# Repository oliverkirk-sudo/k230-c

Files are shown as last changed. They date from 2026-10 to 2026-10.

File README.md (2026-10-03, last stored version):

# k230-c

## 当前检查点：已恢复 v12 + R2.1 源工程

本仓库保存 CM-K230 核心板的可编辑源工程和验证证据。v12 基线与 R2.1 累积增量均已恢复并核验。**这是原理图/候选封装恢复检查点，不是生产版本。当前候选仍没有完整核心板 PCB。**

当前入口：`project/cad/recovery-physical-candidate/CMK230_Core_REVIEW.kicad_pro`（原理图同名 `.kicad_sch`）。保持 `project/` 内相对目录结构即可解析已恢复的 10 个封装库。

## 本次重新验证（2026-10-03，KiCad 9.0.2）

- v12 ZIP：888 个成员 CRC 通过，886 个原始保留文件哈希匹配；SHA-256 `63dab93b8433b3a367571ec64b11568b9c81dc466e8d562ce2108b647d341e58`
- R2.1 ZIP：332 个成员 CRC 通过，325 个增量文件哈希匹配；SHA-256 `4e23cf611b37900dab169f0b44da5974ae70c65bbcf7624c97ccb16688eb3b5b`
- 增量在独立 v12 工作副本上通过防覆盖校验后应用，全部 325 个增量文件保持一致
- 新导出网表：254 个元件、1,509 个引脚绑定，与 R2.1 归档的元件、属性、网络、引脚功能和类型一致
- 恢复后新 ERC：0 个错误、0 个警告；10 个封装库均能解析
- R528 保持默认 DNP，存储默认禁止；149 个元件有封装字段，105 个仍未分配。R574 封装尚未完成验证

新结果在 `validation/2026-10-03-restored/`。`validation/2026-10-03-delta-only/` 保存基线尚未到达时的历史检查（0 错误、150 个缺库警告）；这些缺库警告已由完整恢复后的新结果取代。`project/` 中其他报告保留历史阶段含义，不能视为本次全部重新执行。

## 尚未完成的工程资格验证

- 当前 `recovery-physical-candidate` 没有完整核心板 PCB；历史 PCB、8 层试验和封装/负控夹具仍保留用于追溯，不是当前 6 层成品
- 38 × 38 mm 外形、140 个触点、1 mm 间距、恰好 6 个铜层及仅顶面贴装是设计要求，并非已达成的制造验收
- 尚需完成封装缺口、整板布局布线、DDR/时序、高温/上电、DFM 和工厂工艺确认
- TI 候选阻焊桥名义 80 µm；NXP 示例名义 55 µm。KiCad 全局最小阻焊桥设为 75 µm 时可能合并开窗。必须核对实际 CAM 与铜/蚀刻/阻焊/钢网/贴装能力

## 发布内容、来源与完整性

`project/` 保留源 CAD、库、脚本、数据、网表、工程审查和来源 URL/哈希，以及必要的 `LICENSE-01studio.txt` 上游 MIT 版权许可声明。未将该许可扩展为对其他第三方材料的新授权。

本公开源文件检查点经过筛选，未包含厂商 PDF/扫描页面、图像、运行时缓存、会话设置、日志、备份 ZIP 及部分大型历史 DDR 搜索生成结果。它不是两个原始 ZIP 的逐字节镜像。历史报告和冻结清单可能引用这些省略文件；需要相关生成结果的旧测试须先重新生成。完整排除项/原始哈希/两处非技术署名编辑见 `PUBLICATION_PROVENANCE.json`；当前发布文件完整性以根目录 `SHA256SUMS` 为准。

## English summary

The verified v12 baseline plus R2.1 delta has been restored. The active editable schematic resolves all 10 footprint libraries. Fresh KiCad 9.0.2 ERC has zero errors and zero warnings; the exported 254-component / 1,509-binding graph matches R2.1. There are 149 assigned and 105 unassigned component footprints. This is a source-recovery checkpoint, not a production release: no complete active six-layer board has been recovered or routed. Historical trials and tests retain their original limited scope.

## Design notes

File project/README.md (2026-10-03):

# CM-K230 核心板重设计：v12 评审工程

最新说明：[V12_CORE_REVIEW.md](V12_CORE_REVIEW.md)

保留 38×38mm、140 针、1mm 间距、顶面器件、1GB LPDDR4、16GB eMMC，以及断电切换外部 TF。R528 默认 DNP，存储禁止；整板尚未完成布局布线、启动或高温资格验证。

## 打开哪些文件

- cad/high-temp-candidate/CMK230_Core_REVIEW.kicad_pro：当前条件式高温原理图，18 页、ERC0；同名 PCB 只是150个封装的部分导入，内部元件未放置
- cad/bga-engineering-candidates/bh153-sparse-trial/BH153_SPARSE_LOCAL_TRIAL.kicad_pcb：独立原生 eMMC 逃线试验，保留17个未连通项和32个悬空警告
- cad/conditional-process-check/：保留v11的38封装独立条件工艺规则试验，不是生产规则释放
- cad/edge-bound-seed/：140针逐一接入实际网络的边缘种子，尚无内部器件
- cad/castellation-proposal/：冻结的半孔和八层叠层机械提案，尚待工厂/装配联合接受
- cad/integrated/：保留 Samsung 参考分支及其原有温度限制

既有 GUI 截图按其实际版本保留；本轮 CLI、原生解析、故障对照和各阶段的限制见最新报告。几何局部通过、原理图 ERC0、整板可制造和硬件通过是不同结论。

历史说明保留在 V9_CORE_REVIEW.md、V10_CORE_REVIEW.md、V11_CORE_REVIEW.md 及 docs/。旧 v4 的 eMMC 电源映射错误已修复，禁止使用 v4 制板。

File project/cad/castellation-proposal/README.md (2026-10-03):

# New castellation proposal, not fabrication release

Open `CMK230_Castellation_NOMINAL_PROPOSAL.kicad_pcb` to review the editable 38 × 38 mm edge geometry. The library contains 140 plated, all-layer castellated pads at 1 mm pitch, Ø0.50 mm requested nominal finished opening, and 0.80 × 1.80 mm oval copper. Both mask layers have 0.05 mm expansion; there are no paste apertures. The board has eight copper layers and a proposed 1.2 mm nominal thickness. No dielectric stack or impedance width is invented in this CAD file.

This is a new module fabrication proposal. The original carrier's 1.6 × 0.56 mm oval lands at normal coordinates ±18.746 mm are a different geometry. The proposed module drill rows lie at ±19 mm. The inner drawing rectangle is a conditional 1.30 mm component reservation, not a fabrication keepout rule accepted by a factory.

Read the [source-backed review](../../engineering/mechanical/castellation-stackup-proposal-review.md), [dimensional proof](../../engineering/mechanical/castellation-proposal-dimensional-proof.json), [source comparison](../../engineering/mechanical/castellation-fab-source-review.json) and [stackup proposal](../../engineering/mechanical/core-stackup-process-proposal.json). The main CAD and committed area-screen baseline are unchanged.

Do not use this footprint as the carrier mating footprint, order fabrication from it, or infer factory acceptance from a clean KiCad DRC. Run `engineering/mechanical/build_castellation_proposal.py` with the system Python/KiCad environment to reproduce the proposal. Generated native UUIDs may change while geometry remains identical.

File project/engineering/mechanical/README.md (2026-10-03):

# Mechanical and footprint audit

Date: 2026-09-30. Scope: selected TI footprints and BGA package coordinates for the 38 x 38 mm top-component CM-K230 review. No master CAD edited. No module castellation geometry inferred from the existing carrier mating footprint.

## Outcomes

- Four editable TI footprints in `../../cad/verified-footprints/CMK230_Verified.pretty`
- 42 numbered copper pads; 42 explicit mask openings; 42 paste apertures
- 568 independent numeric checks through KiCad's parser, including pin positions, sizes, corners, layer membership, mask/paste and courtyard enclosure
- Native KiCad DRC on the isolated footprint QA board: 0 violations, 0 unconnected items. Its 0.075 mm local clearance rule is a geometry-test setting, not evidence a PCB vendor can manufacture the module
- Native Gerber verification: all 42 flashes on each of F.Cu/F.Mask/F.Paste match independently transcribed positions, dimensions, shapes and corner radii
- Independent manufacturer-source extraction corroborates 200 RAM, 153 eMMC and 390 K230 physical-ball centers with no occupancy mismatches

## TI drawing results

| Package | Body nominal / maximum, mm | Drawing-verified exposed pattern | Chosen copper / mask details | Courtyard, mm |
|---|---|---|---|---|
| RSV0016A | 1.80 x 2.60 / 1.85 x 2.65 | 0.4 pitch; 15 lands 0.6 x 0.2; pin1 0.7 x 0.2 | NSMD; copper = exposed land; explicit 0.05 expansion; constant-offset corners | 2.80 x 3.60 |
| DBV0005A | 1.60 x 2.90 / 1.75 x 3.05 | 1.1 x 0.6 lands; x=+/-1.3; y=0,+/-0.95 | NSMD; chosen 0.05 expansion within TI 0.07 max | 4.30 x 4.10 |
| DMQ0006A | 1.50 square / 1.55 square | left 0.6 x 0.25 at x=-0.65; right 1.0 x 0.2 at x=+0.45; y=0,+/-0.5 | TI-preferred SMD; chosen minimum 0.05 copper overlap each side; copper 0.70 x 0.35 / 1.10 x 0.30; exposed R0.05 | 2.50 x 2.10 |
| YCG0015 | 1.05 x 1.78 / 1.07 x 1.80 | 3 columns x 5 rows at 0.35 pitch; 0.200 circular exposed opening | TI-preferred SMD; chosen minimum 0.0325 overlap; copper diameter 0.265; aperture diameter 0.200 | 1.60 x 2.30 |

Courtyards are project-selected: at least 0.25 mm beyond maximum body/copper/mask envelope, rounded outward to 0.05 mm. DBV additionally accounts for the drawing's possible 0.25 mm body flash per side. Courtyards are not vendor package dimensions or an approved module placement density rule.

RSV pin1 center is (-0.75,-0.60), while the other left-side centers are x=-0.80. Its longer land shares the same outer edge as the other left lands. The RSV top-view functional pinout differs from the TSSOP package. DMQ's data-sheet function diagram is a bottom view; the footprint is transformed to the component-side pattern with pin1 upper-left. YCG A1 is (-0.35,-0.70), A3 (+0.35,-0.70), E1 (-0.35,+0.70).

The YCG stencil aperture is a 0.21 mm rounded square with R0.05 corners, not a 0.21 mm circular aperture. Its TI example stencil is 0.075 mm thick. RSV/DBV/DMQ examples are 0.125 mm. Those are assembly examples rather than automatically compatible selections for one board; obtain a reviewed common or stepped stencil.

Selected drawn minimum copper / mask gaps: RSV 0.200 / 0.100 mm; DBV 0.350 / 0.250 mm; DMQ 0.150 / 0.250 mm; YCG 0.085 / 0.150 mm. These are nominal geometric gaps, not guaranteed post-fabrication tolerances. SMD overlaps at the minimum must still be qualified for registration and etch tolerances.

## Existing KiCad library comparison

The installed libraries were read and preserved unchanged. Their common package names are not exact replacements for these TI examples:

- `SOT-23-5`: IPC-generated pads at x=+/-1.1375, size 1.325 x 0.6, rather than the TI example x=+/-1.3, size 1.1 x 0.6
- `UQFN-16_1.8x2.6mm_P0.4mm`: different IPC land lengths/centers (pin1 0.9 x 0.2 at -0.8,-0.6; others 0.8 long), rather than the exact RSV board example
- `WSON-6_1.5x1.5mm_P0.5mm`: TLV702-derived generic geometry; cannot substitute for DMQ's asymmetric short/long contacts
- A same-body QFN with a center exposed pad is not valid for RSV. No such pad was added

The installed-library JSON records actual parsed dimensions and rotations. Different IPC land dimensions are not themselves proof an installed footprint is unsafe; they simply do not reproduce the selected official TI land examples.

## Evidence and reproduction

- `small-parts-footprint-spec.json`: package dimensions, exact sources, process choices and build data
- `small-parts-pad-coordinate-audit.csv`: electrical pad positions and functions
- `small-parts-verification.json`: native-parser checks and footprint hashes
- `native-gerber-verification.json`: independently checked KiCad-exported aperture geometry
- `footprint-geometry-qa-drc.json`: native DRC result
- `TI-footprint-layer-gallery.png`: copper/mask/paste layers rendered from actual loaded footprint objects
- `native-svg/`, `native-render/`: KiCad's own footprint exports, visually reviewed
- Official PDF page/image evidence is retained outside this distributable tree in the reference workspace; source manifest records URLs and hashes
- `ti-source-manifest.json`: official URLs, local reviewed source hashes and pages
- `installed-kicad-library-comparison.json`: installed package comparisons
- `bga-mechanical-audit.md` and `bga-*-physical-centers.csv`: independent BGA findings, sources, centered coordinates and release boundaries

Run `python3 build_verified_footprints.py`, then `/usr/bin/python3 validate_verified_footprints.py`. Export the isolated QA board F.Cu/F.Mask/F.Paste through `kicad-cli pcb export gerbers`, then run `python3 check_native_gerbers.py`. The validator deliberately does not import the generator's spec; the Gerber validator uses a separate transcription. Native KiCad Python is available in `/usr/bin/python3`.

If regenerating exports, point XDG_CONFIG_HOME, XDG_CACHE_HOME and XDG_DATA_HOME to writable temporary locations. The footprint library uses explicit local mask/paste settings; keep the unnumbered mask/paste primitives when integrating.

Original manufacturer PDFs and source-image copies are research evidence, not new licensed package deliverables; preserve their attribution/usage terms and use source links in any externally distributed package. This audit does not expand source redistribution rights.

## Remaining release boundaries

The three large BGA sources establish occupancy, ball-center pitch, body envelope and orientation, not a complete PCB copper/mask/stencil design. Never use the published ball diameter as an automatic PCB pad diameter. K230's 0.270 mm mask statement is package-context evidence; it does not alone establish a board land pattern. Module castellations, drill/plating/edge offsets and the manufacturing edge definition remain unverified separately from the original carrier land pattern.

## Placement-only continuation

`../../cad/verified-footprints/placement-only/` contains an isolated 38 x 38 mm editable KiCad canvas with the 3 BGA mechanical placeholders and the actual 10 small-IC instances of the four verified TI footprint types. All are top-side. `placement-only-canvas.png` is the annotated preview. The 13 chosen assembly envelopes fit without overlaps (minimum pair gap 0.85 mm; outline gap 2.45 mm). There are no BGA copper/mask/paste pads, routes, vias, drills, zones or edge contacts. See the canvas README for the explicit omissions: this is body-fit evidence only, not proof of escape, passive fit, thermal/PDN performance or manufacturing feasibility.

## Compact-package alternatives, 2026-09-30 continuation

The expanded BOM makes the original 13-IC body canvas insufficient as a full-fit result. `compact-package-audit.md` reviews pin-equivalent DRL/DCK choices for SN74AUP1G06/07/08/17 and the exact TPS3808 DBV-to-DRV remap, with three new editable candidate footprints in `../../cad/verified-footprints/compact-options/`. Five AUP DRL instances plus two TPS3808 DRV instances recover 30.04 mm² against seven rough 11.52 mm² DBV reservations. The compact candidate coupon passes 226 native numeric checks and independent copper/mask/paste Gerber checks; no master integration was done.

`compact-inductor-mechanical-review.md` records the official DFE201610E-R47M drawing and 6.67 mm² body/land or 7.20 mm² hypothetical mask-sensitive reservations, pending electrical/thermal selection. `compact-area-scenarios.json` freezes the old area-screen hash and keeps the proposed savings separate from a latest full-BOM estimate. A limited U96-only update leaves essentially no arithmetic margin even before complete routing and support-part changes. These remain area-screen candidates, not proof of manufacturable single-sided fit.

Latest correction: U92/U94 use the six-pad SN74AUP1G97 DRL Schmitt-AND footprint; U96 and its capacitor are removed by the design lead. The older five-AUP area scenarios are historical, as is the optional eight-rail monitor assumption. See the first section of `compact-package-audit.md` and `compact-AUP1G97-status.json`. The expanded compact library now passes 302 numeric checks and 23/23/24 copper/mask/paste Gerber checks.

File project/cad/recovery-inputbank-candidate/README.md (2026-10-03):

# RCV-INBANK-R12 conditional sibling

Open CMK230_Core_REVIEW.kicad_sch to inspect the alternative eight-part22µF input-bank circuit. The preferred comparison baseline remains ../recovery-physical-candidate; every existing R11 project file is unchanged.

Exactly eight input values/footprints change and four named input capacitors are removed. All six100nF bypasses remain. No other values, pin/net/function/type bindings or population states change. The candidate is250 components/1501 bindings, with238 footprint identities and12 gaps. Fresh ERC and generator/graph checks pass within that scope.

See ../../recovery/r12-input-bank-candidate/README.md for exact references, current source evidence, Ceff assumptions,120→176µF nominal input increase, inrush/VIN-fall gates and34–36mm² matched-area cost. No full PCB, physical fit, operating qualification or production release follows from this candidate. R528 remains DNP and storage qualification remains inhibited.

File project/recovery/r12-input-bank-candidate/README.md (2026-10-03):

# R12: separate 22 µF input-bank candidate

This is a coherent alternative circuit, not the preferred or production-qualified core. The baseline at cad/recovery-physical-candidate is preserved byte-for-byte from published R11. Open cad/recovery-inputbank-candidate/CMK230_Core_REVIEW.kicad_sch to inspect this alternative. No full PCB or manufacturing output is produced.

## Exact revision

Eight existing positions become22µF CL31B226KPHNNNE input candidates: C203,C210,C211,C216,C217,C220,C225,C230. Only C204,C221,C226,C231 are removed. U22/U23 retain two local bulk capacitors each; U21/U24/U25/U26 have one each. C205,C209,C215,C222,C227,C232 retain their100nF bypass duties and values. All other nominal values, component population/BOM flags and numbered pin/function/type/net identities remain unchanged.

The candidate contains250 components and1501 bindings across457 nets. It has238 assigned footprints and12 gaps. The physical baseline remains254/1509 with230 assigned and24 gaps. JP1,R45,R47 and R528 remain DNP. Default storage qualification is still inhibited.

## Evidence and cost

Fresh manufacturer curves, not the archived result alone, support a conditional screen of6.925µF per selected part at5.5V. The pairs screen at13.849µF against the adopted8µF TPS628640B input criterion; the singles screen at6.925µF against the3µF TPS6282xA criterion. Initial tolerance, normalized typical AC response, temperature, aging and model reserve are individually identified in source-review. Separate typical curves and illustrative reserves do not establish a guaranteed combined minimum or lifetime qualification.

Nominal input bulk capacitance rises from120 to176µF. The same six100nF bypasses are retained and excluded from those bulk totals. Charging/inrush, source impedance, VIN ringing, input RMS current and ripple heating require review. TPS628640B's VIN falling-rate requirement below UVLO remains a hard integration gate; the favorable Ceff screen does not demonstrate compliance.

Matched source geometry comparisons add approximately34.40–36.08mm² despite removing four parts. The actual selected R11 footprint has a4.85×2.45mm engineering courtyard; eight rectangles total95.06mm² before routes, loops and access. That exact reservation and the earlier matched-clearance comparisons are different metrics. Neither proves38mm board fit. Continuing actual copper, local return and inductor/sense constraints remain required.

## Coherent source and checks

The alternative is regenerated from its sibling build_review.py with guarded original10µF values and exact VIN_5V/GND pin mappings. Source generator declarations and libraries shared with the baseline are not edited. A historical sidecar field is clarified as exclusion from generic Samsung bypass reassignment; it is not a claim that later Murata eMMC footprints are absent.

validate_candidate.py accepts explicit project, baseline and runtime directories. It verifies all remaining component properties and the complete pin/function/type/net graph, the generated pin CSV, symbol pin library, mandatory bypasses, DNP safeguards and exact source footprint identities. Fresh ERC reports zero violations. A separate runtime regeneration reproduces the same electrical contract. Negative controls reject an undeleted reference, removed100nF bypass, wrong survivor value/footprint, populated R528 and a capacitor moved from input to output.

All1417 already-published project files remain byte-identical; only the sibling and its review directory are new. Source review was originally bound to R10; the explicit R10→R11 scope bridge confirms the reviewed input/regulator/divider/bypass scope is unchanged, without claiming equal whole-master hashes.

## Remaining release boundaries

This alternative does not qualify combined Ceff, VIN collapse behavior, startup, current/thermal stress, stability, PDN, routing or placement. It does not resolve the47µF land gap, RTC startup/accuracy, BootROM/OTP storage policy, memory procurement or full-board process acceptance. The original baseline remains the comparison source. Promotion requires the relevant electrical and physical validation; no production readiness is claimed.

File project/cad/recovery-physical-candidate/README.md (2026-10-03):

# Physical candidate RCV-PHYS1

Active reconstruction candidate: this schematic binds U14 and U92 to independently audited manufacturer land examples. Frozen RCV-LOGIC1 remains the electrical reference. No PCB has been reconstructed in this branch. Exactly six copper layers, 38 mm outline, 140 contacts and top-only assembly remain requirements.

TI mask expansion is an engineering choice with an 80 µm nominal web. NXP source mask expansion produces a 55 µm web; KiCad merges these openings when global minimum mask web is 75 µm. Use actual exported CAM verification. Neither geometry is factory-approved. Do not globally relax unrelated mask rules to make these packages pass. Copper, etch, mask registration, stencil and assembly tolerances require a coherent process contract.

R3 binds R574 to a source-derived Vishay0201 land candidate and L22–L26 to existing Murata land candidates. These six added assignments preserve all values and nets;155 references now have footprints and99 remain unassigned. See ../../recovery/r3-physical-coverage/README.md for current validation and process limits. None of these footprints is factory-qualified. Default R528 is DNP and storage remains inhibited. Footprint assignment and ERC do not qualify thermal behavior, startup, DDR routing, timing, or manufacturing.

R4 adds all three BGA engineering footprint identities:158 assigned,96 unassigned. See ../../recovery/r4-bga-coverage/README.md. No full six-layer layout or factory-qualified BGA construction is implied.

R5 conditionally changes only eight DAT pullups to43k and assigns their source-land candidates:166 assigned/88unassigned. See ../../recovery/r5-dat43/README.md. Resistance-budget compliance is distinct from lifetime, signaling, boot and production qualification.

R6 assigns25 conditional bias-resistor footprints and the exact L21 source-land candidate, preserving all values and nets:192 assigned/62 gaps. See ../../recovery/r6-passive-coverage/README.md. Its correct winding-start orientation and larger maximum-body reservation do not establish a power-loop or board-fit pass.

R7 assigns ten further link/feature footprints and excludes three fabricated copper features from the BOM:202 assigned/52 gaps. All values, bindings and DNP states are preserved. See ../../recovery/r7-links-and-features/README.md. Default DNP does not remove R528 paste apertures; production stencil selection remains unresolved.

R8 assigns nine process-dependent ferrite patterns and four feedforward-capacitor source lands:215 assigned/39 gaps, unchanged values/nets/population. See ../../recovery/r8-filter-feedforward-lands/README.md. The18µm pattern reservation is not a selected or approved six-layer stack; hot DCR, bias response and process registration remain open.

R9 assigns six source-range eMMC bypass lands:221 assigned/33 gaps, with all nominal values/nets/population preserved. See ../../recovery/r9-emmc-bypass-lands/README.md. Table13 nominal/effective interpretation and combined operating capacitance remain explicit qualification gates.

R11 assigns nine Samsung22µF source-land identities with unchanged electrical graph/population:230 assigned/24 gaps. See ../../recovery/r11-22uf-source-lands/README.md. The47µF land proposal and input-bank options remain unselected; source-land coverage is not Ceff or board-fit qualification.

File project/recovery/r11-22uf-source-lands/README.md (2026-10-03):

# R11: 22 µF source-land identities

This conditional footprint checkpoint follows published R10, commit05b3254a3c19f15cf78588ed8095e06ab68f32da. It adds no completed core placement, routing or manufacturing qualification.

## Exactly nine assignments

C206/C207/C208 remain the CPU output bank, and C212/C213/C214 remain the KPU output bank. C540/C552 retain their respective DRAM VDD2/VDDQ local roles on VDD1P1_DDR_IO; C562 remains local VDD1 decoupling on VDD1P8. Their shared footprint does not merge these physical or electrical duties.

Each receives the conditional source-land identity for Samsung CL31B226KPHNNNE, nominal22µF, ±10%,10V,X7R,1206. No nominal value, component count, net, pin type/function, DNP or BOM flag changes. The full graph remains254 references,1509 bindings and457 nets. Coverage becomes230 assigned and24 missing. R528 remains DNP and default storage is inhibited.

## Geometry and process distinction

The exact manufacturer's metric3216±0.20mm reflow row is applicable. Its allowed gap/land-length/width ranges are1.64–1.76 /1.19–1.31 /1.74–1.86mm. The selected midpoint is two1.25×1.80mm rectangular copper pads centered at x=±1.475mm:1.70mm inner gap and4.20mm outer span. These are engineering selections within manufacturer ranges, not a prescribed unique land.

The maximum body is3.40×1.80mm, maximum height1.80mm. Mask expansion+0.05mm and separate1:1 paste apertures are project assumptions. The4.85×2.45mm courtyard uses a0.05mm stroke, leaving0.25mm from the nominal mask envelope to the courtyard's inner stroke edge. This construction is explicitly distinct from a manufacturer courtyard or factory approval. Assembly placement/etch/mask/stencil tolerances, solder transfer and reliability remain open.

The47µF candidate reviewed alongside this part has no matching exact±0.40mm-length reflow row. Its separate engineering proposal remains unselected and unassigned. The FLOW table is not substituted for a reflow recommendation. Input-capacitor bank count/value options also remain unapplied.

## Electrical and validation scope

The current CPU/KPU output banks retain the adopted30µF effective-capacitance design criterion per bank. Assigning22µF nominal parts does not establish combined biased/hot/aged Ceff or converter stability. DRAM local capacitors retain their own allocation, locality, return and PDN obligations; they do not automatically count as remote regulator capacitance.

Fresh KiCad9.0.2 ERC and exact graph/population comparison pass. The isolated20×13mm six-layer one-footprint fixture has no routing and unique diagnostic nets; its DRC has zero rule/unconnected items, with two copper/mask/paste flashes each. It is not the38×38mm module. Negative controls detect CPU/KPU or DRAM rail mixups, nominal changes and wrong pad geometry. Independent source/native review accompanies the final checkpoint.

Remaining24 footprint gaps comprise12 input capacitors, four47µF outputs, four oscillator load capacitors, C815, two oscillator feedback resistors and the RTC crystal. Complete top-only placement, a coherent six-layerHDI process, routing, startup/boot, clock accuracy, SI/PDN, sourcing and physical thermal/electrical testing remain unfinished. This source identity does not release production files.

The native [copper/mask comparison](bulk22-copper.svg) was visually checked. Independent review reports77 checks and six negative controls passing, including a real native clearance failure. This remains isolated geometry evidence.

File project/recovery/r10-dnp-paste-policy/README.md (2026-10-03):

# DNP stencil export policy review

**Result: PASS_REVIEW_ONLY on KiCad 9.0.2+dfsg-1.** The installed Gerber CLI and Python plot API do not expose a paste-specific “suppress DNP” option. A reversible, separately named assembly-board derivation successfully removes DNP paste while preserving copper, mask, holes, electrical bindings, placement and population attributes. This review does not qualify a stencil, assembly process, or production release.

## Installed controls and evidence

The local `kicad-cli pcb export gerbers --help` exposes these DNP controls:

- `--hide-DNP-footprints-on-fab-layers`
- `--sketch-DNP-footprints-on-fab-layers`
- `--crossout-DNP-footprints-on-fab-layers`

Their names and help scope them to fabrication layers. The installed `PCB_PLOT_PARAMS` has corresponding `Get/SetHideDNPFPsOnFabLayers`, `Get/SetSketchDNPFPsOnFabLayers` and `Get/SetCrossoutDNPFPsOnFabLayers` methods, but no DNP paste filter. `FOOTPRINT.IsDNP/SetDNP`, BOM/PnP exclusion flags, `PAD.Get/SetLayerSet`, and `LSET.RemoveLayer` are separate APIs. Position export independently has `--exclude-dnp`.

The installed evidence is retained in [Gerber help](final-evidence/gerbers-help.txt), [position help](final-evidence/pos-help.txt), and [API inventory](final-evidence/installed-api.json). The [official KiCad 9 CLI documentation](https://docs.kicad.org/9.0/en/cli/cli.html) corroborates the documented scope. The conclusion is bounded to the inspected 9.0.2 runtime, not other KiCad releases or third-party exporters.

Actual default CLI, hide-on-Fab CLI, combined Fab controls, and native Python `SetHideDNPFPsOnFabLayers(True)` plotting all retain the same DNP paste flashes in the fixture. In this build the tested CLI hide flag also left the fixture Fab output unchanged; this review does not claim that those Fab controls were effective or diagnose that separate behavior.

## Population source and immutable inputs

Authoritative inputs are the supplied project's `cad/recovery-physical-candidate/master.xml` and `tools/population_contract.py`. Their hashes and the source footprint-library hashes are in [results.json](final-evidence/results.json). The master marks **JP1, R45, R47 and R528 DNP**. JP1, J1, TP81 and TP82 are fabricated features in the population contract.

DNP is taken from the native master property and reconciled against board attributes, not inferred from value text, a generic BOM exclusion, or a reference prefix. Native BOM/PnP/board-only attribute parity, footprint library identity and every numbered electrical pad/net binding must agree with the master before derivation and on the derived board. Reference coverage alone is never sufficient electrical parity. Duplicate references, duplicate/ambiguous population properties, and unexplained board/master differences are errors. The master symbol pin declarations must exactly match its net-node pin set. Every included footprint must contain all expected numbered electrical pads, with no unknown numbers; each native pad must carry the exact expected net name. Multiple physical pads with one number are allowed only when every copy matches that same expected net. Both source and derived boards undergo these checks, including when subset-fixture mode is enabled.

The current master explicitly supplies a net node for every declared symbol pin, including NC pins. There are no NC or virtual-pin exceptions in this policy. An NC pad with an explicit master net must match that net; an importer that substitutes net zero needs a separately reviewed explicit rule. Missing master nodes, implicit virtual pins and unrecognized numbered mechanical pads fail closed rather than being guessed. File-level checks also reject electrical identity on non-copper pads and nonzero net declarations on unnumbered pads before native KiCad can normalize those declarations away.

The published master, population contract and footprint-library sources remained byte-identical. No published main-board or current R8 CAD was edited. The fixture deliberately represents only eight master references; the 246 absent references are explicitly reported, not silently treated as complete coverage.

## Derived-board procedure

1. Pin a source board, master XML and population contract by SHA-256. Keep the source as the canonical design. Require complete master reference coverage and exact per-reference pin/net parity by default; `--allow-subset-fixture` is an explicit review-only exception.
2. Generate a new, separately named native `.kicad_pcb` file. The helper refuses to overwrite the source or an existing output. Do not update footprint libraries, run footprint replacement, recalculate placement, or refill zones.
3. For each reconciled DNP footprint, remove only `F.Paste` and `B.Paste` layer membership from pads that retain other layers. Preserve the pad number, UUID, copper geometry, net, mask settings, position and every other field.
4. Remove a paste-only pad object only when it has no number, net declaration or drill. The CRCW0201 source footprint uses two such standalone apertures, so removing paste from its numbered copper pads alone would do nothing. Numbered/net-bound/drilled paste-only objects fail for review instead of being discarded.
5. Remove footprint-owned paste-only graphics from DNP footprints. All other footprint tokens remain unchanged. Paste-layer properties, zones, wildcard paste layers, unowned board paste, and groups referencing removed apertures fail closed for ownership/format review. These unsupported constructs are not guessed or silently dropped.
6. Reject paste on any contract-declared bare fabricated feature, including JP1 and TP81/TP82. A missing fitted-part aperture is likewise an error, not an acceptable side effect.
7. Verify that all remaining native board tokens exactly match the expected allowed-only edit; reload with native KiCad; check that DNP pads, graphics, fields and zones have no native paste membership; confirm native save/reload preserves the edit. Keep hashes and a per-object change manifest. Source and derived pin/net checks are independent of the allowed-only token comparison, so faithfully preserving a wrong source net does not pass.
8. Export **only F.Paste and B.Paste from the derived board** for the population variant. Continue taking copper, solder mask, outline and drill deliverables from the canonical source. Preserve the existing reconciled BOM/PnP process independently. Regenerate the derived artifact whenever the board, population variant, library binding or source contract changes.

The helper uses a bounded native S-expression patch instead of a full-board rewrite for the initial derivation. This preserves every non-paste token verbatim; KiCad itself then loads, saves and plots the result. A whitespace-insensitive token comparison allows native formatting while rejecting changes to values. The source plus the manifest makes the operation reversible: discard the derived board and regenerate; never copy it back into the canonical project.

R528 remains DNP and placement-excluded, and its original separated copper/net assignments remain unchanged. Removing its paste is one assembly safeguard; maintaining its electrical inhibit also requires the no-fit assembly instruction and the existing electrical/interlock review. This fixture does not certify circuit behavior.

## Reproduced results

The small two-sided fixture loads the existing source-library CRCW0201, bare bridge and bare testpad geometry. It adds clearly synthetic paste graphics/apertures, a mixed copper/paste pad case, a same-number/same-net plated-hole pad on TP81, track and via to exercise export semantics. The TP81 duplicate pad is a deliberate fixture control, not a source footprint-library change. Original numbered pads retain their authoritative master pin-net bindings; R528 retains VDD1P8 on pin 1 and BOOT_VOLTAGE_QUALIFIED_1V8 on pin 2, plus DNP and placement exclusion. It is not a production layout or a replacement netlist.

| Measurement | Default / Fab hide | Derived stencil |
|---|---:|---:|
| F.Paste flashes | 9 | 3 |
| B.Paste flashes | 7 | 3 |
| F.Paste component attribution | DNP and fitted | R529 only |
| B.Paste component attribution | DNP and fitted | R46 only |
| Fitted paste graphic regions | 1 per side | 1 per side |

Each surviving side has the fitted resistor's two source-library apertures plus one synthetic test aperture. The tested default DNP paste includes intentionally added test geometry; these counts must not be quoted as production-board aperture counts.

All **42 checks** pass, including sixteen intentional rejected controls:

- Copper deletion from R528 is rejected
- Fitted R529 aperture loss is rejected
- Paste added to bare TP81 is rejected for the bare-feature rule
- R528 board DNP-attribute removal is rejected
- R528 master-DNP removal is rejected independently
- Unowned board-level paste is rejected
- Wrong-net R528 and fitted R529 pads are rejected independently on source and derived boards (four controls)
- Missing R528 numbered pads and unknown TP81 pad numbers are rejected
- A duplicate-number TP81 pad with the wrong net is rejected, while both same-net copies pass
- A nonzero net declaration on an unnumbered pad is rejected
- Non-paste footprint position changes are rejected by the allowed-only token comparison
- A master missing a declared pin's net node is rejected without inventing an NC/virtual exception

Full F.Cu, B.Cu, F.Mask, B.Mask, Edge.Cuts and F.Fab Gerber content compares equal after removing only creation timestamp, file identity and checksum metadata. Excellon drill geometry compares equal after timestamp removal. Default PnP CSV is byte-identical and contains only fitted R46 and R529; DNP and bare features remain excluded. BOM attributes and master inputs are unchanged; no independent purchasing BOM regeneration is claimed.

The manifest records 14 unique expected pins and 15 numbered physical pads for the eight-reference fixture. This includes the deliberate same-number TP81 duplicate. It records an empty NC/virtual exception list. The results file also pins both executed Python scripts by SHA-256.

Machine-readable evidence: [checks and hashes](final-evidence/results.json), [per-object derivation manifest](final-evidence/derivation.json), [derived native board](final-evidence/DERIVED_STENCIL_REVIEW_ONLY.kicad_pcb), [native roundtrip](final-evidence/NATIVE_ROUNDTRIP_REVIEW_ONLY.kicad_pcb). Negative fixtures are deliberately invalid and must never be used as manufacturing inputs.

## Reproduce with parameterized paths

Requires the installed KiCad CLI and the Python interpreter that provides `pcbnew` (here `/usr/bin/python3`). No additional package installation is required. The output directory must be new.

```sh
/usr/bin/python3 test_policy.py --project "$PROJECT_ROOT" --out "$REVIEW_RUN_DIR"
```

Run an independent review derivation on a complete board:

```sh
/usr/bin/python3 derive_assembly_paste.py \
  --source "$SOURCE_BOARD" \
  --output "$DERIVED_BOARD" \
  --master "$MASTER_XML" \
  --population-contract "$POPULATION_CONTRACT" \
  --report "$DERIVATION_REPORT"

kicad-cli pcb export gerbers \
  --layers F.Paste,B.Paste \
  --output "$STENCIL_REVIEW_DIR/" \
  "$DERIVED_BOARD"
```

Supply only trusted project code as the population-contract argument. For a deliberately incomplete isolated fixture, explicitly add `--allow-subset-fixture`. To recheck an existing derived board, use `--verify-only` and a new report destination.

**Boundary:** CAD export policy is demonstrated for the supported constructs on this runtime. There is no claim about stencil thickness, area ratio, transfer efficiency, paste chemistry, print registration, mask-process limits, reflow or assembly yield. Those require a separate manufacturing/process review. No vendor was contacted and no production output was issued.

## R10 integration on the recovered project

R10 adds only this review/tool directory to exact published R9. Every existing project file remains byte-identical: the circuit revision remains RCV-R9, with221 assigned footprints and33 gaps. The42-check fixture suite was rerun against this exact project, not merely copied from the earlier R7 review.

The actual recovered R7 ten-reference native fixture was also tested. It uses an Audit_Footprints library alias, which strict source/master checking initially rejected as intended. A separate copy normalizes only those ten FPID strings after confirming every copied .kicad_mod is byte-identical to its authoritative current library file. The original fixture is preserved. This does not waive electrical parity.

[test_recovered_fixture.py](test_recovered_fixture.py) reproduces that normalization and derivation using explicit --project and --out arguments. [The actual-fixture result](recovered-fixture/recovered-fixture-results.json) confirms copper/mask18→18 flashes and paste14→12, removing only R528's two apertures. All non-paste CAM layers remain equal; all numbered pad/net identities and population flags agree with the current master. This is a recovered fixture, not the complete core board.

The synthetic two-sided fixture deliberately exercises both front and back paste. It does not change the user's top-only core assembly requirement. Deliberately corrupted negative fixtures and all diagnostic Gerbers are review artifacts, never production inputs. The bounded export-policy defect is addressed by the verified derivation, while full-board application and stencil/process qualification remain open.

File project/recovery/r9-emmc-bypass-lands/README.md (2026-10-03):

# R9: eMMC bypass footprint candidates

This conditional checkpoint assigns six previously empty footprints. Its predecessor is published R8, commit f5181cb06de490fb23de0e79c619210a664b3212. No complete PCB, assembly release or operating qualification is claimed.

## Preserved circuit

C64/C65 remain on EMMC_VDDIM, the eMMC internal regulator capacitor node at U3.C2. C69/C70 remain on VEMMC_IO, the VCCQ rail fed from VDD1P8 through R561. C71/C72 remain on VDD_3V3, the VCC supply. Every capacitor's pin2 remains GND. The internal regulator node must not be treated as VCCQ or driven by an external supply.

All 254 component values, 1,509 pin/function/type/net bindings across 457 nets, population and BOM flags remain unchanged. The six footprint identities are the only component-attribute changes. Coverage becomes 221 assigned, 33 unassigned. JP1/R45/R47/R528 remain DNP, and default storage qualification remains inhibited.

## Source-based geometry, conditional component choice

C64/C69/C71 use the candidate Murata GRM188R71A225KE15D: 2.2µF, ±10%, 10V, X7R, 0603, −55…125°C. Copper pads are 0.65×0.70mm at x=±0.675mm, giving a0.70mm inner gap. This is a midpoint engineering selection inside the manufacturer reflow ranges, not a mandated exact pattern. Maximum body is1.70×0.90mm, maximum height0.90mm. The project courtyard is2.60×1.50mm.

C65/C70/C72 use the candidate GRM155R71C104KA88D:100nF, ±10%,16V,X7R,0402,−55…125°C. Copper pads are0.40×0.50mm at x=±0.40mm, with0.40mm inner gap. Maximum body is1.05×0.55mm, height0.55mm. The project courtyard is1.80×1.20mm.

Both use rectangular copper, +0.05mm mask expansion and separate1:1 paste apertures. Mask/stencil/placement tolerances and courtyards are explicit engineering process choices. Current manufacturer approval sheets, lifecycle, procurement quantity and actual factory acceptance remain open. JLC catalog identity was found, but MOQ1 was not verified. No components were ordered.

## Capacitance qualification remains open

Micron Table13 gives capacitor Min/Max/Typ values but does not explicitly define their operating effective-capacitance basis, bias, tolerance, temperature or aging conditions. These preserved nominal choices fit the printed table. That is not a guaranteed hot/bias/aging margin. Conversely, interpreting the columns as absolute effective minima would be an additional unverified assumption, not an established Micron compliance failure.

The source review retains conditional numerical budgets and the unknown residual effects. Do not infer a numerical VDDIM voltage from VCCQ; the inspected Micron source gives no such range. A different nominal capacitance, if later justified, requires a separate coherent electrical revision. No such change is made here.

## Verification scope

Fresh KiCad9.0.2 ERC reports zero violations. Full exported graph and population comparison allows only the six footprint fields to change. The two-footprint geometry fixture is20×13mm with six copper layers, unique diagnostic nets and no interconnects. It has zero rule violations and four copper/mask/paste flashes per layer. It is not the38×38mm core or evidence of local BGA bypass placement.

Mutation checks catch a wrong CReg net, an unauthorized nominal-value change and wrong land geometry. Independent source/native checks accompany the checkpoint. The prior default-DNP paste export gate remains open for actual assembly; these diagnostic outputs are not a production stencil.

The remaining33 gaps include30 capacitors, two oscillator feedback resistors and the RTC crystal. Top-only full placement, six-layerHDI stack/routing, PDN/SI, cold-storage boot policy, clock startup/accuracy, thermal behavior and physical validation remain unfinished.

The native [copper/mask preview](bypass-copper.svg) was visually checked: left0603, right0402. It omits identification and drawing-sheet layers for clarity; all source CAD remains editable. This is an isolated geometry comparison.

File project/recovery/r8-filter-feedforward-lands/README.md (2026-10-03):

# R8: conditional analog-filter and feedforward lands

This checkpoint adds thirteen footprint identities to the recovered core schematic. It is not a complete layout or a production release. The exact predecessor is published R7, commit 1fddab33bbd0a6d00e7c53c8f09ba6f72e5ada13.

## Electrical identity and coverage

FB202–FB210 receive a conditional Murata BLM15PX121SN1D source-pattern option. C202/C219/C224/C229 receive KEMET C0402C122J5GACTU density-B source lands. No values, pin/net/function/type bindings, BOM flags or population states change. There are 254 components, 1,509 bindings, 457 nets, 215 assigned footprints and 39 gaps. JP1/R45/R47/R528 remain DNP. Source contracts nominate exact parts; assigning a footprint does not silently qualify generic value strings as a final procurement BOM.

## Ferrite copper is process-dependent

The exact Murata drawing specifies exposed lands 0.4 x 0.5 mm centered at x=±0.4 mm, but its power-family copper extends beneath solder resist. For the exact part's 2 A rating class, copper width d is 1.2/0.7/0.5 mm for 18/35/70 µm copper. Three distinct footprint variants preserve this distinction. The schematic uses the explicitly named 18 µm option as the larger conditional reservation. This does not choose or approve the six-layer factory stack.

Each numbered copper pad is 0.4 x d mm. Separate unnumbered mask apertures expose only the nominal 0.4 x 0.5 mm source opening; separate paste apertures use the same nominal dimensions as an engineering assumption. No expansion or registration allowance is included in that exact mask model. Factory acceptance must establish mask/copper registration and actual process margins. The engineering courtyard is 1.8 mm wide and at least 1.2 mm tall, increasing to1.8 mm for the 18 µm variant. These courtyards are not manufacturer assembly approval.

The rectangles implement only the local source pattern. They do not prove the continuing trace cross-section, heat spreading, filter impedance under DC bias, or current qualification. Initial55 mΩ and post-test70 mΩ are room-condition limits, not guaranteed hot DCR. Guide currents are reference module budgets, not measured peak loads. FB206 additionally feeds the R401 startup strap, whose pad current is not closed. The source-based branch screens and residual voltage budgets remain conditional; noise, transient, sequencing and thermal validation are still necessary.

## Feedforward source applicability

TI's Cff=12µ/Rbottom equation gives1.2 nF for each actual10 kΩ lower divider resistor. The four capacitor pin2 terminals reach the regulator FB pins; pin1 remains on the respective output side of the upper feedback resistor. KEMET density-B lands use0.62 mm square copper pads at x=±0.45 mm and the published1.90 x1.00 mm courtyard. Maximum body envelope is1.05 x0.55 mm, maximum height0.55 mm. Mask expansion+0.05 mm and separate1:1 paste are explicit unqualified process choices.

The nominated part is1.2 nF±5%,50 V,C0G,−55…125°C. This preserves nominal values but does not establish loop stability over all regulator/load/temperature conditions. LCSC C22402196 was verified searchable with minimum/multiple20, a user-preference exception; the same exact part has a quantity-one DigiKey cut-tape option. No purchase or stock reservation has occurred.

## Verification and remaining limits

Fresh KiCad9.0.2 netlist comparison preserves the complete electrical graph and all population attributes. ERC reports zero violations. The diagnostic20 x13 mm, six-layer fixture compares the three ferrite variants and one capacitor footprint. It uses unique diagnostic nets and has zero rule violations/unconnected items; all four parts remain isolated. Native exports have eight copper, eight mask and eight paste flashes. It is not the module and is not an assembly or routing pass.

Mutation controls detect wrong thickness-dependent copper width, accidentally exposed ferrite shoulders and an incorrect FB terminal net. Independent source/native review is retained separately when complete. The existing R528 DNP stencil gate remains: default paste export still includes its apertures. No manufacturing outputs are released.

The39 remaining footprint gaps are36 capacitors, two oscillator feedback resistors and the RTC crystal. Full38 x38 mm top-only placement, six-layerHDI construction, routing, SI/PDN, clocks, boot behavior, thermal testing and factory qualification remain unfinished. Historical lost geometry is not reconstructed by these source lands.

The native [copper/mask comparison](filter-copper.svg) was visually checked: top row18/35/70µm ferrite variants, bottom density-B capacitor. Drawing-sheet and text layers are omitted for clarity; the source footprints retain their identification. This preview does not add process tolerances.

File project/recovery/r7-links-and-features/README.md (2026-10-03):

# R7: links and fabricated core features

This is a conditional schematic/footprint reconstruction checkpoint, not a routed or production-ready core. The published R6 checkpoint is its exact predecessor.

## Verified change

Ten references receive footprint identities: R205/R206, R220/R221/R401/R528/R561, JP1 and TP81/TP82. JP1 and both test pads become BOM-excluded fabricated copper features. All 254 values, 1,509 pin/function/type/net bindings across 457 nets, on-board flags and population states remain unchanged. Coverage is now 202 assigned and 52 unassigned. JP1, R45, R47 and R528 remain DNP.

The source-derived WSL and WFZ copper lands are accompanied by explicit engineering body, courtyard, mask and paste assumptions. R205/R206 use the existing TNPW land option; ordinary links use the existing CRCW land. Exact part current, hot resistance, tolerance drift and assembly limits remain conditional. See source-review and the independent audit for source URLs, dimensions and applicability limits. The source review records the earlier unassigned footprint state; this checkpoint adds geometry without changing those seven references' electrical identities or values.

JP1 is an intentionally open two-pad solder bridge. Open selects the eMMC mode intent; a manual bridge selects TF mode intent. It is serviceable only with power removed and discharged. Neither state establishes BootROM/OTP or storage-voltage qualification. TP81/TP82 are bare, top-side observation pads on their original PMU status nets, without paste or drills; they are not external drive ports. These are engineering proposals, not factory land recommendations.

## Validation and assembly limits

Fresh KiCad 9.0.2 ERC reports zero violations. The five-reference 26 x 12 mm geometry-only fixture has zero DRC items; its copper/mask/paste exports contain 8/8/4 flashes. The separate independent ten-reference fixture preserves shared net names and therefore reports three unrouted connections, with zero rule violations. It exports 18/18/14 flashes and only six fitted resistors in the position file. Neither fixture is the 38 x 38 mm module or proves connected circuitry.

The population helper preserves native copper and net identity while excluding fabricated features from BOM/position output. Negative controls catch lost DNP, lost copper, wrong test-pad net, inappropriate BoardOnly and position/BOM reinclusion. R528 remains electrically inhibited by default.

IMPORTANT: R528's two paste apertures remain in KiCad's default paste export despite DNP and placement exclusion. Production needs an explicit assembly/stencil variant and inspection of the resulting paste output. Diagnostic Gerbers here are not manufacturing releases. The same policy must cover other DNP parts; DNP alone is not a stencil rule.

## Remaining work

The 52 footprint gaps comprise 40 capacitors, nine ferrites, two oscillator feedback resistors and the RTC crystal. Combined hot/bias/aging effective capacitance, clocks, reset/PG margins, storage boot policy, sourcing and thermal limits remain open. Full top-only 38 x 38 mm placement and a complete six-layer PCB remain unfinished. No prior lost layout geometry is recreated by this checkpoint. Factory stackup, copper/mask/stencil tolerances, routing/SI and physical electrical/thermal tests are release gates.

Reproduce the lead checks with validate_coverage.py and explicit --project, --baseline, --runtime arguments using system Python with pcbnew. The independent validator similarly accepts explicit input/output paths. Keep diagnostic outputs apart from production exports.

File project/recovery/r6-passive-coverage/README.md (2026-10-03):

# R6: passive footprint coverage

This physical-only revision assigns source-derived footprint candidates to 25 ordinary bias resistors and L21. All 254 component values, 1,509 pin/function/type/net bindings and population attributes remain unchanged from R5. R45/R47 and R528 remain DNP; storage remains inhibited. The eight DAT pullups stay at the R5 43k value. Coverage is 192 assigned references and 62 gaps. There is still no complete active six-layer PCB.

## Bias resistor batch

The exact 25 references are listed in assignments.json. They use the already checked Vishay CRCW0201 land candidate: 0.28×0.43mm lands, 0.23mm gap, with declared process-only mask/paste/courtyard choices. No precision VSET, zero-ohm/high-current, or oscillator-feedback part is swept into this batch. Two of the25 positions are DNP boot options and stay unpopulated.

The included bias-review was performed on R3; r6-applicability.json confirms that these25 actual values, terminal nets and population attributes still match. Its old47k DAT hold is historical and was addressed separately by the conditional R5 change. Its hypothetical180-reference coverage is not the current R6 inventory. Candidate order codes do not establish stock, one-piece orderability, lifecycle or mission-life qualification.

The source screen's worst steady DC stress is3.361mW on R204 under its stated assumptions, versus17.647mW from the125°C derating graph. This does not prove actual film temperature or transient behavior. CORE PG→EN noise/ramp limits, private-I²C drive/leakage and RC limits, reset/PMU/boot timing, and R571/R572 idle-state guarantees remain open. A footprint assignment cannot close them. R33 stays270k with its existing total-resistance acceptance requirement.

## Exact L21 geometry

The unchanged part is0.47µH XFL4015-471MEB. The official Coilcraft Document769-2, revised2026-03-10, supplies the recommended copper geometry: two0.98×3.40mm rectangles with2.37mm center spacing, hence1.39mm inner gap. Component-top-view pad1 is at(+1.185,0), on the marked right-hand start/short-lead side, and maps to SW_CORE. Pad2 at(−1.185,0) maps to VDD0P8_CORE. The numeric pin convention is ours; the source identifies the marked terminal. Do not mirror a bottom-view drawing or treat this as a generic pin1-left inductor.

Maximum body is4.30×4.30mm and height1.60mm for the reviewed E termination. The full maximum-body F.Fab rectangle and positive-X assembly cue are included. The cue's drawn size is an engineering illustration, not a manufacturing mark dimension. Mask expansion50µm per edge, separate1:1 paste apertures and4.80×4.80mm courtyard are process assumptions. The courtyard is1.88mm² larger than the old4.60mm reservation; this increase is retained. Neither etch/placement tolerance nor stencil/process capability is qualified.

Coilcraft does not state the Murata-specific blanket under-coil prohibition in the reviewed sources. No such automatic keepout is added to L21. This does not approve arbitrary routing beneath it: switching-loop, return, sensing, coupling and EMI review remain required. L22–L26 retain their separate Murata restrictions. The MEB→MEC product-page note concerns packaging; no suffix or electrical part is silently substituted here. Hot inductance/current/saturation/loss, solder profile, thermal rise and module fit are not qualified.

## Native validation

Fresh KiCad9.0.2 export/ERC checks exactly26 Footprint changes and no other component/graph/population changes. The isolated10×10mm L21 fixture has six copper layers and no route or plane; its two single-pad nets only prove the intended terminal identity. Its nominal geometry DRC passes. Mirrored winding-start numbering, wrong SW/output mapping, altered PG resistor and populated boot DNP controls are rejected. A deliberately1.40mm clearance control rejects the actual1.39mm land gap. This is not a whole-board or power-loop pass.

Run validate_coverage.py with explicit --project, --baseline (published R5 project) and --runtime paths using Python with pcbnew. Keep the38×38mm outline,140contacts,top-only assembly and six layers as the final integration requirements. Source PDFs and raw vendor images are excluded from this deliverable.

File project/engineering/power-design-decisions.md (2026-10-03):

# D0 补充：电源矩阵与待决设计

本文件比D0增加可计算的23个K230电源域基线，但仍不是已接线的电源原理图。

## 预算定义
`rail-budget.csv`逐行记录官方指南电源域电压/电流及原文行号。所有GPIO-bank暂按3.3V计算，这是预算假设，不是接口电压决定。排除LPDDR3和K230D内部DRAM专属行，避免把K230D电流套到外接Samsung RAM。

按指南各域电流与所列标称电压简单相加为9.01W。**这只是器件级设计分配和，不代表实测、典型、保证最大值或一定同时出现的模块功耗。** 没有包含Samsung外部RAM、eMMC、外供3.3/1.8V、损耗、时钟/无源、瞬态余量。不能据此指定整板5V电源额定值。

最终VIN预算需逐工作模式计算：P_IN = Σ(P_rail/η_rail) + 保护/辅助损耗；I_IN=P_IN/VIN_min。η随电压/负载/温度变化；线损、启动浪涌、外供输出和最高CPU/KPU DVFS电压必须纳入。每路还需阶跃负载模型，而非只检查连续电流。

## 可研究的调压器路线（未冻结BOM）
- TI TPS62826：官方3A降压，2.4–5.5V输入、可调0.6–4V，1.5×1.5mm封装；可作为CORE固定标称电压的候选，不能替代KPU推荐4A能力。资料：https://www.ti.com/product/TPS62826
- TI TPS62864：官方4A、I2C/DVS，0.4–1.675V输出，15球0.35mm节距WCSP。电压范围覆盖CPU/KPU低压调节，但增加BGA制造难度、地址/启动默认/上拉/供电时序/固件验证。资料：https://www.ti.com/product/TPS62864
- 这些只是比EA3059更明确的能力候选；尚未选完整订货号、L/C/R、环路/瞬态、EN逻辑和PG时序。不能把典型应用直接当成针对本板验证过的方案。

## 兼容性约束决定电源控制方案
CM-K230已引出大量GPIO。为I2C调压器随意占用外露GPIO会增加负载或改变功能，所以目前不指定任何“空闲I2C脚”。先核对原板电源控制/BSP与K230专用控制能力，再确定控制路径；没有可兼容路径时，必须明确性能/功耗模式边界或取得接口变更许可。

## 顺序图准备
约束有向边：VDD0P8_CORE→VDD1P8，VDD0P8_CORE→各VDDIO3P3_0..5，AVDD0P8_MIPI→AVDD1P8_MIPI，AVDD1P8_RTC→AVDD1P8_LDO（允许同时）。必须叠加Samsung RAM/eMMC厂商的顺序要求。没有数值时序数据时，不臆造RC延迟。

候选实现是PG/监督器控制的确定性使能，而不是假定所有EN并联上拉就安全。外部bank提前供电可能打破芯片先后顺序并反灌，仍需原模块/底板合同解决。

## 电源域到外围的待连接矩阵
1. LPDDR4 VDD1=1.8V，VDD2/VDDQ=1.1V；与相关K230 DDR域供电网络按参考实现配合
2. VDD0P8_DDR_CORE、VDD1P1_DDR_IO、VAA_DDR不得按相似名字接成K230D专有DDR脚
3. eMMC VCC选择3.3V域；VCCQ待与MMC0固定/可切换IO域核对，未在网表短接
4. VOUT_3V3/VOUT_1V8必须给出外部额定电流、过载保护和先后时序；官网标注3.3V最大300mA、1.8V最大100mA，应至少满足这一兼容要求；瞬态、过载/短路与总输入预算仍待设计
5. BANK0..5_VDDIO方向/内部连接待证据，不把它们同时接内部稳压与外部电源

输出额定来源：https://wiki.01studio.cc/en/docs/canmv_k230/intro/canmv_k230/#pinout （pin7/8，2026-09-30读取）。两路同时最大负载还需额外1.17W输出及其转换损耗，尚未计入9.01W SoC域分配和。

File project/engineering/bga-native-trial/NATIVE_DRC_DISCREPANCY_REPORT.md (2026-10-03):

# BH153 native local fanout trial

The frozen analytical witness was reproduced in editable KiCad 9.0.2 geometry for **MTFC16GAPALBH-AAT**. Native DRC reports **17 connectivity errors and 32 warnings**. It reports **no copper-clearance, drill, hole-clearance, annulus or mask-bridge violations at the declared nominal rules**. This is a local geometry result, not a routed module or manufacturing release.

## What is represented

The board contains one U3 footprint, all 153 physical 0.30 mm circular copper lands, 29 plated through vias of nominal 0.30/0.15 mm, and 16 track segments implementing the frozen witness. The 11 host signals have local exits on F.Cu (L1) and In2.Cu (L3); the VDDIM exit is also retained. A6 is VSS/GND with the remote ground via. M6 is CLK. DS remains on EMMC_DS_UNUSED without a route or via.

There are eight copper layers and a 1.2 mm reference thickness. No dielectric stack is supplied. The square 20 mm Edge.Cuts boundary is explicitly a computational analysis window, not the 38 mm module outline or proposed component placement. There are no additional components, port footprints, copper zones or invented plane connections.

Every U3 function and current net identity was checked against master-pin-assignments.csv and master.xml. VSS and VSSQ are GND; VCC is VDD_3V3; VCCQ is VEMMC_IO. The 109 NC, 4 RFU and 7 VSF lands retain distinct pin-function metadata and the XML's 120 unique unconnected net identities. None are joined. The 43 absent grid sites and 56 unsoldered package test contacts receive no PCB land, mask or paste aperture.

## Declared candidate rules

| Feature | Selected native rule / nominal geometry |
| --- | --- |
| Copper clearance | minimum 0.1016 mm |
| Track width | minimum / actual 0.1016 mm |
| Via land | minimum / maximum / actual 0.30 mm |
| Via hole | minimum / maximum / nominal request 0.15 mm |
| Via annulus | minimum / nominal 0.075 mm |
| Hole to other-net copper | minimum 0.20 mm |
| Hole to hole | minimum 0.20 mm |
| Front mask | 0.40 mm land aperture; minimum web 0.10 mm |
| Paste | 0.30 mm circular aperture |
| Stencil | 0.10 mm analysis assumption, unqualified |

The source-reviewed alternative JLCPCB table's 0.15/0.25 mm minimum via pair implies a 0.05 mm nominal annulus. This candidate instead uses the preferred +0.15 mm diameter increase and explicitly enforces the resulting 0.075 mm minimum. Those via-specific values do not replace generic component PTH or castellation rules. The original analytical file still records the earlier 0.1524 mm hole-to-copper assumption; alternate-via-process-check.json and this native trial apply the stricter 0.20 mm rule.

Filled, planarized, copper-capped VIPPO is **required**. The native through-via symbols display a nominal drill; they do not model the physical cap. Via tenting flags omit separate mask apertures, while each physical BGA land supplies its own 0.40 mm aperture. Tenting is not a substitute for filled/capped processing. Nominal mask web and annulus meet their chosen limits with zero tolerance margin. Mask registration, physical drill/tool diameter, plating, etch, registration/breakout, reflow and high-temperature reliability remain unqualified.

## Why the analytic and native results differ

| Native finding | Count | Explanation |
| --- | ---: | --- |
| Unconnected items, error | 17 | GND needs 10 joins, VDD_3V3 needs 3, and VEMMC_IO needs 4. The local witness supplies individual escapes, not a PDN |
| Dangling via, warning | 20 | All 20 PG escapes end without an attached inner plane or additional routing |
| Dangling track, warning | 12 | Eleven host signal exits plus the VDDIM exit deliberately end in the local window |
| Other native violations | 0 | No additional violations under the stated nominal settings |

The analytical proof screened separation of its modeled geometry. It did not claim board connectivity. KiCad adds these explicit unfinished-connectivity findings. Preserving real PG net identities is what lets KiCad report the missing connections. No severity was ignored, no DRC exclusion was added, and in-footprint solder-mask bridges are not allowed.

A single-pad net with a local trace stub is not a connection to the SoC. Native DRC cannot report a missing component absent from this deliberately isolated board. Full schematic parity is therefore not claimed or run; the standalone window's one U3 footprint is checked pin-by-pin against the source CSV/XML instead. All 11 host endpoints, supply distribution, VDDIM stabilization and bypass/return networks remain unfinished outside the window.

## Positive controls prove the checks are active

Separate copies under rule-controls intentionally tighten one rule at a time. The candidate's files remain unchanged during these checks.

| Positive control | Expected native error | Findings |
| --- | --- | ---: |
| Annulus minimum 0.080 mm | annular_width | 29 |
| Hole-to-other-net copper 0.280 mm | hole_clearance | 199 |
| Hole-to-hole minimum 0.360 mm | hole_to_hole | 21 |
| Mask web minimum 0.110 mm | solder_mask_bridge | 200 |

These counts demonstrate enforcement, not additional candidate violations. See rule-control-results.json and the raw control reports. The real candidate retains 0.075/0.20/0.20/0.10 mm respectively.

## Editable files, evidence and reproduction

- Board, project and custom rules: ../../cad/bga-engineering-candidates/bh153-sparse-trial/BH153_SPARSE_LOCAL_TRIAL.kicad_pcb, .kicad_pro and .kicad_dru
- Footprint library: ../../cad/bga-engineering-candidates/bh153-sparse-trial/BH153_Engineering.pretty
- Native SVG exports and PNG renders: ../../cad/bga-engineering-candidates/bh153-sparse-trial/preview
- Unfiltered DRC output: native-drc.json, native-drc.log and native-drc-command.json
- Source and pin identities: source-manifest.json and native-net-mapping.csv/.json
- Re-import checks: native-validation.json
- Independent native parser audit: native-independent-review.json and verify_native_emmc_independent.py; all 1,009 checks passed on the final annotated board, including corroboration of the four raw control reports

Run with the installed distribution Python and KiCad 9: first generate_bh153_native_trial.py, then check_native_rule_controls.py, then verify_native_trial.py. Each script configures the requested temporary KiCad XDG directories. The generator also runs native SVG export and Inkscape rasterization. No external vendor upload, contact or order is performed; the restricted Micron CSN-33 source was not accessed or retried.

KiCad rule semantics: https://docs.kicad.org/9.0/en/pcbnew/pcbnew.html. Process-rule source and limitations are preserved in the frozen alternate-via-process-check.json. Exact Micron package geometry comes from the already reviewed package evidence; the 0.30/0.40/0.30 NSMD footprint is an engineering candidate, not a manufacturer-qualified land pattern.

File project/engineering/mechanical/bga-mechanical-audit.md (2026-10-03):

# BGA mechanical and orientation audit

Date: 2026-09-30. Scope: nominal ball-center coordinates, physical occupancy, view/orientation, and package dimensions for the CM-K230 review draft. No master CAD was modified. These results do not qualify copper lands, solder mask, paste apertures, escape routing, assembly or fabrication.

## Result

All three physical-ball sets are independently corroborated by the manufacturer mechanical drawings:

| Device | Actual balls | Grid | Pitch X / Y | Center-to-center span X / Y | Package body |
|---|---:|---|---|---|---|
| Samsung K4F8E304HB-MGCJ | 200 | 12 columns x 22 named rows | 0.80 / 0.65 mm | 8.80 / 13.65 mm | 10.00 +/-0.10 x 15.00 +/-0.10 mm |
| Samsung KLMAG1JETD-B041, 16GB | 153 | 14 x 14 | 0.50 / 0.50 mm | 6.50 / 6.50 mm | 11.50 +/-0.10 x 13.00 +/-0.10 mm |
| Canaan K230, not K230D | 390 | 20 x 20 | 0.650 / 0.650 mm | 12.350 / 12.350 mm | 13.000 nominal; 12.900-13.100 mm on both axes |

Numeric pitch/span dimensions printed in basic-dimension boxes or nominal-only table entries are not independently asserted to have an unspecified +/- dimensional tolerance. Retain the package drawing's GD&T rather than inventing a pitch tolerance.

## Coordinate convention and deliverables

CSV coordinates are millimetres, origin at nominal package center, component-side/top view, +X right and +Y down. This is a useful KiCad front-footprint local-coordinate convention. A backend using Cartesian +Y up must invert Y explicitly. Bottom-layer placement must be handled by the CAD tool's layer transform, not an additional undocumented manual mirror.

- `bga-K4F8E304HB-physical-centers.csv`: 200 physical positions
- `bga-KLMAG1JETD-physical-centers.csv`: 153 physical positions
- `bga-K230-physical-centers.csv`: 390 physical positions
- `bga-coordinate-verification.json`: counts, full absent-position sets, source hashes and provenance
- `bga-verify-coordinates.py`: reproducible occupancy extraction and coordinate generation

Only existing source labels accompany the positions. This mechanical audit does not independently re-audit every electrical function label or approve net assignments. No missing-ball pad is emitted. NC, RFU, and DNU are physical positions where the source draws a ball, and are not collapsed into NO_BALL.

## Samsung LPDDR4

Source: [Samsung K4F8E304HB-MGCJ Rev1.0, mechanical p9 and explicit top-view ballout p10](https://www.szyuda88.com/home/8/a/2lhtb2/resource/2021/05/26/60ade38424a32.pdf#page=9), manufacturer-authored PDF hosted by a third-party mirror. Local `lp4.pdf` SHA-256 is recorded in the verification JSON.

Rows top-to-bottom: A B C D E F G H J K L M N P R T U V W Y AA AB. Columns increase left-to-right 1-12 in top view. Page9's ball drawing is explicitly BOTTOM VIEW, with 12 at left and 1 at right. Page10 is explicitly TOP VIEW, with 1 at left. The index mark is upper-left on the top package view and upper-right on the bottom ball view.

For zero-based row index r and one-based column c: x=(c-6.5)*0.80; y=(r-10.5)*0.65. Consequently A1=(-4.400,-6.825), A12=(+4.400,-6.825), AB1=(-4.400,+6.825), AB12=(+4.400,+6.825).

Exactly 64 absent grid locations: all 12 positions in each of rows L and M, plus columns 6 and 7 in each of the other 20 rows. This leaves 20 populated rows x 10 populated columns =200. The apparent gaps are integer-multiple spacings on a regular grid: columns5-to8 =2.40 mm; rowsK-toN =1.95 mm. Do not compress those gaps or substitute a square 0.65 mm grid.

Page9 dimensions also specify:

- Total package height 0.90 +/-0.10 mm
- Solder-ball stand-off dimension 0.22 +/-0.05 mm
- 200 post-reflow ball diameters 0.31 +/-0.05 mm; the parenthetical solder-ball diameter is 0.30 mm
- Coplanarity-type callout 0.10 MAX to datum C
- Ball-position callout diameter0.15 at maximum material condition relative to A/B

Verification: extracted exactly 200 closed four-Bezier circle subpaths from page9 and mapped its reversed column order to page10's top-view grid. The occupied-position set matches the existing 264-grid/200-physical CSV without differences. One circle shares a PDF drawing object with an unrelated line; treating whole-object bounds as circles would miss it. Pixel coordinates were used only to identify occupied sites; published dimensions determine the exported XY.

## Samsung eMMC

Source: [Samsung eMMC Rev1.1 family PDF including KLMAG1JETD-B041, ballmap p5 and 8/16GB package Figure2 on p6](https://e2e.ti.com/cfs-file/__key/communityserver-discussions-components-files/791/Samsung-eMMC_2D00_2611204514.pdf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), manufacturer-authored PDF hosted on TI's forum. The 32GB drawing lower on p6 is not the selected16GB package-height specification.

Rows top-to-bottom: A B C D E F G H J K L M N P. The p5 wording is "Ball-side down view": balls facing down, with the component viewed from above. It has column1 at left and A1 upper-left. This agrees with the p6 TOP VIEW index mark. The p6 mechanical BOTTOM VIEW has column14 at left and column1/index corner at right. Do not interpret the p5 wording as a bottom-surface view and mirror it again.

For zero-based row index r and one-based column c: x=(c-7.5)*0.50; y=(r-6.5)*0.50. Thus A1=(-3.250,-3.250), A14=(+3.250,-3.250), P1=(-3.250,+3.250), P14=(+3.250,+3.250).

The 43 absent locations are:

- D5-D11
- E4, E11
- F4, F6-F9, F11
- G4, G6-G9, G11
- H4, H6-H9, H11
- J4, J6-J9, J11
- K4, K11
- L4-L11

All other 153 sites contain balls. In particular D4 exists while D11 does not, so a symmetric central-void shortcut is wrong. Existing functional classifications count107 NC,13 RFU and33 explicitly functional/power/ground balls.

Figure2's actual 8/16GB drawing specifies:

- Total height 0.70 +/-0.10 mm; the section/caption's0.8 mm is consistent with the maximum height, not a separately supported0.8 mm nominal height
- Stand-off dimension 0.21 +/-0.05 mm
- 153 ball diameters 0.30 +/-0.05 mm
- Coplanarity-type callout0.08 MAX
- Ball-position callout diameter0.15 at maximum material condition relative to A/B

Verification: p5 contains154 circle paths at153 unique positions because N12 is drawn twice. Unique sites match the existing196-grid/153-physical CSV. Independent p6 Figure2 mechanical-circle extraction, after horizontal reflection, yields the same153 positions. No mismatched locations were found. Rasterized pages5-6 were also visually reviewed.

## Canaan K230

Official sources: [Hardware Design Guide, package section](https://github.com/kendryte/k230_docs/blob/main/en/00_hardware/K230_Hardware_Design_Guide.md), [Figure2-1 top/bottom drawing](https://raw.githubusercontent.com/kendryte/k230_docs/main/zh/00_hardware/images/HDG/image005.png), [Figure2-2 height/detail drawing](https://raw.githubusercontent.com/kendryte/k230_docs/main/zh/00_hardware/images/HDG/image006.png), [Figure2-3 dimension table](https://raw.githubusercontent.com/kendryte/k230_docs/main/zh/00_hardware/images/HDG/image007.png), [Figure2-6 function/occupancy map](https://raw.githubusercontent.com/kendryte/k230_docs/main/zh/00_hardware/images/HDG/image010.png).

Rows top-to-bottom: A B C D E F G H J K L M N P R T U V W Y. Figure2-1's BOTTOM VIEW has column20 at left and1 at right. Mirroring it horizontally yields the component-side/top map shown by Figure2-6: column1 at left. The top package index corner is upper-left, but A1 itself has NO BALL. Do not create an A1 pad as a marker or retain an old schematic-only A1=NC entry.

For zero-based row index r and one-based column c: x=(c-10.5)*0.650; y=(r-9.5)*0.650. Outer ball-center rows/columns are +/-6.175 mm. The A1 reference grid coordinate is(-6.175,-6.175), but is absent. First existing row-A ball A2=(-5.525,-6.175). A20=(+6.175,-6.175); Y1=(-6.175,+6.175); Y20=(+6.175,+6.175).

Exactly10 absent positions: A1, E5, F5, R4, R5, T4, T5, T6, U4, U5. Remaining20x20-10=390 physical balls match the existing390-ball table.

Dimension-table values in mm:

| Symbol | Minimum | Nominal | Maximum | Meaning supported by figures |
|---|---:|---:|---:|---|
| A | 0.770 | 0.870 | 0.970 | Overall height |
| A1 | 0.160 | 0.210 | 0.260 | Stand-off dimension; not ball-name A1 |
| A2 | 0.600 | 0.660 | 0.720 | Body thickness dimension |
| c | 0.180 | 0.210 | 0.240 | Substrate dimension c |
| D/E | 12.900 | 13.000 | 13.100 | Body sides |
| D1/E1 | - | 12.350 | - | Ball-center spans |
| e | - | 0.650 | - | Pitch |
| b | 0.250 | 0.300 | 0.350 | Ball diameter parallel to datum C |

The drawing's tolerance table also lists aaa0.100, bbb0.100, ddd0.080, eee0.150, fff0.080. Their actual GD&T frames remain in the cited drawings; they are not PCB fabrication dimensions. The ball count N is390 and MD/ME is20/20. A separate nominal ball-diameter entry is0.300 mm.

Verification: a dark-neutral-pixel/connected-component pass over the official bottom-view mechanical drawing detected390 ball-ring components. Converting bottom-view columns to top-view yielded exactly the same10 holes as the official function grid and the existing390-ball table, without mismatches. The three mechanical images were downloaded from the exact official links above and visually reviewed; their hashes are recorded.

## Land-pattern and release boundaries

These sources establish nominal package ball centers and package dimensions, not complete board land patterns. In particular the following remain UNVERIFIED and must not be marked manufacturer-qualified:

1. PCB copper land diameter, land tolerance, NSMD versus SMD choice and copper shape
2. PCB solder-mask opening/expansion, mask registration allowance and minimum mask web
3. Paste aperture diameter/shape/reduction, stencil thickness and area-ratio/process qualification
4. Via-in-pad size, filling/capping/plating and escape/drill rules
5. Courtyard/assembly clearances and board-specific manufacturability limits

For RAM and eMMC, their0.31/0.30 mm callouts describe balls, not PCB pads. The0.15 GD&T callout describes package ball positioning, not a pad or via diameter. Neither inspected Samsung package page provides an explicit board copper/mask/paste recommendation.

The K230 guide says "Ball Solder Mask Opening:0.270mm" directly below the package drawings, together with package-datum/ball-diameter notes. This establishes a package-context mask-opening statement. It does not identify a board-side land pattern, state PCB NSMD/SMD, or give a copper diameter or stencil design. Do not treat0.270 mm as a verified board solder-mask opening without manufacturer clarification. In particular it cannot by itself justify board copper0.270/0.300 mm or a matching paste aperture.

A manufacturing-release footprint still needs an explicit supplier land-pattern/application recommendation or an approved PCB/assembly-house land-pattern design, tied to the selected stackup and process. This audit resolves the occupancy/orientation/center-coordinate gate only.

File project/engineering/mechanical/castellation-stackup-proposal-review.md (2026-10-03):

# 38 mm core: new edge, stackup and component-reservation proposal

Status: **reviewable engineering proposal; factory and module-assembly acceptance remain open**. The main design and its historical 2 mm area-screen band are unchanged. This proposal retains 140 numbered contacts, 35 per side at 1 mm pitch, and permits components only on the top side.

## Proposed geometry and its evidence

The editable [KiCad proposal](../../cad/castellation-proposal/CMK230_Castellation_NOMINAL_PROPOSAL.kicad_pcb) has a 38 × 38 mm outline, 140 plated holes centered on the outline, and oval pads measuring 0.80 mm along the edge by 1.80 mm normal to it. The pads exist on every copper layer and both mask layers. Unused inner annuli are retained. No paste apertures are included: the carrier stencil and solder volume belong to the later module-mounting process.

**Ø0.50 mm means the requested nominal finished plated opening before edge routing.** The KiCad drill value is this nominal request; it is not the production drill-tool diameter. Tool compensation, copper plating, residual barrel shape and their tolerances need one factory's combined approval.

[Cirtech's Rev 001/A design note, PDF page 3](https://www.cirtech-electronics.com/wp-content/uploads/2024/03/Edge-Plating-and-Castellations-web.pdf) lists nominal minima of 0.50 mm hole, 0.80 mm pad and 1.00 mm pitch. Cirtech identifies itself as a PCB supplier working with manufacturing partners. Its publication supports this candidate geometry but does not accept a specific factory, eight-layer build, pad extension or tolerance stack.

The original STEP investigation independently finds 140 nominal Ø0.50 mm edge cutouts at the same pitch. Its modeled board thickness is 1.538354 mm. Those findings support nominal shape and position; they do not establish copper lands, plating or fabrication tolerances. See [original STEP evidence](original-step-edge-evidence.json).

Nominal geometry gives 0.15 mm transverse annulus, 0.65 mm inward centerline copper beyond the hole, 0.20 mm adjacent copper gap and 0.50 mm hole-edge gap. A 0.05 mm mask expansion leaves a 0.10 mm mask web. End-hole centers sit 2 mm from the corner; copper leaves 1.6 mm of edge at either end. These are derived dimensions, not fabrication allowances.

## Published process limits prevent an unconditional release

The [16-source comparison](castellation-fab-source-review.json) preserves the contradictions rather than selecting convenient values:

- [JLCPCB's capability table](https://jlcpcb.com/capabilities/pcb-capabilities) lists 0.5 mm holes/gaps, but its [dedicated castellation article](https://jlcpcb.com/blog/castellated-pcbs-introduction-and-design-requirements) gives stricter hole, ring and corner limits. The candidate fails that stricter published envelope
- [PCBWay's dedicated half-hole page](https://www.pcbway.com/pcb_prototype/What_are_Plated_Half_Holes_Castellated_Holes_.html) allows smaller holes, while other pages differ on spacing and cost. Its post-routing size is not dimensioned clearly enough to infer a retained radial-depth requirement
- [PCBWay's manufacturing table](https://www.pcbway.com/pcb_prototype/PCB_Manufacturing_tolerances.html) distinguishes a normal 0.20 mm PTH ring from a 0.15 mm via ring. The candidate does not meet the former. Increasing pad width to 0.90 mm consumes the available mask separation
- The nominal 0.10 mm mask web is below a literal 4 mil (0.1016 mm) rule. A 0.05 mm opening is also slightly below 2 mil. Global mask registration moves openings together and does not itself narrow their web; opening-width and differential-position errors are separate unknowns
- Four densely contacted edges need a specific panel support and routing plan. The corner gaps are not proof that break tabs, clamping or depanelization are safe

Consequently the hypothesis is rejected as an already-qualified generic standard service. It remains a source-backed custom-process candidate. No vendor has been contacted, no design has been uploaded, and no fabrication order has been made.

## Derived component reservation

The proposed reservation is **1.30 mm from each nominal board edge**:

0.90 mm inward copper + 0.05 mm mask expansion + 0.0762 mm mask-position budget + 0.25 mm component separation = 1.2762 mm, rounded outward.

The 0.0762 mm figure comes from [PCBWay's standard quality table](https://www.pcbway.com/oem/quality-control.html). Using it here is an engineering budget, not a claim that PCBWay accepts the rest of the geometry. The 0.25 mm component-to-mask separation is an explicit assembly assumption. It is applied to actual body and exposed solder-land extents; courtyard conventions must not silently consume or double-count it.

This produces a conditional 35.4 × 35.4 mm region, **1253.16 mm²**, 97.16 mm² larger than the historical 34 × 34 mm screen. It does not make that area routable. BGA escape, local decoupling, power paths, thermal spreading, test access and component rework still consume it. Ordinary plane/trace edge clearance remains a separate rule. Bottom-side routing is possible, but exposed bottom copper outside the castellations must not contact the carrier.

## Mating proof and its limits

The original carrier lands are **ovals**, 1.599999 × 0.559994 mm, with the long axis normal to the edge. The source Altium file says `SHAPE=ROUND` with unequal dimensions; the existing converted carrier footprint agrees. The authoritative carrier center rows remain ±18.746 mm, while this module's hole centers are ±19 mm. The intended normal offset is therefore 0.254 mm. Microscopic coordinate-conversion noise is retained in the input record and normalized to the explicitly specified 1 mm module grid.

Exact oval cross-section integration gives nominal retained copper overlap of approximately **0.385866 mm² per contact**, excluding the half-hole void. A continuous interval proof gives at least 0.132499 mm² for any pure relative translation within ±0.15 mm on each axis, under nominal copper/hole/profile dimensions. Sampled full-shape minima are labeled as samples, not global proofs. A separate conservative calculation covers an illustrative ±0.10 mm translation plus ±0.10° module rotation by eroding an inscribed carrier rectangle and bounding contact displacement.

These are conditional geometric proofs. Carrier pad/mask tolerances, assembly capability, wetting, solder volume, warpage and post-reflow stand-off are unknown. A generic ±0.2 mm outline size tolerance is not a local drill-to-route specification. An intentionally conservative combination with generic ±0.075 mm hole position and ±0.08 mm bore tolerance can even fail to guarantee that the profile intersects a hole. That calculation demonstrates why a joint registration specification is required; it is not a claim about the actual factory's correlated process.

The [dimensional JSON](castellation-proposal-dimensional-proof.json), [contact CSV](castellation-proposal-contacts.csv) and [profile drawing](castellation-proposal-profile.svg) contain the parameters and proofs. No worst-case assembly acceptance is claimed.

## Eight-layer trial and escape gates

The [stackup/process proposal](core-stackup-process-proposal.json) selects PCBWay's published eight-layer, nominal 1.2 mm through-hole construction, catalog entry 13, as a simulation and escape-routing trial. At its stated 70% copper assumption, the seven pressed dielectric gaps are 0.1195 / 0.1300 / 0.1090 / 0.1300 / 0.1090 / 0.1300 / 0.1195 mm, with 1 oz finished copper per layer. The catalog finished thickness is 1.19 mm ±10%. The [source catalog](https://www.pcbway.com/multi-layer-laminated-structure.html) explicitly excludes blind/buried vias; its 50% copper entry changes the pressed thicknesses. Neither nominal board thickness nor these typical Dk values fixes an impedance geometry.

Proposed roles are signal / ground / signal / ground / power / signal / ground / signal. L1 carries all components. L6 routes require return-path review near L5 splits; L8 has no components. A named laminate appropriate for reflow, temperature, CTE and electrical loss remains to be selected. High Tg alone is not a thermal solution.

A 1.2 mm board changes the original STEP's nominal height; the separately listed 1.6 mm construction is an alternative. Filled, planarized, copper-capped vias may be needed inside solder lands. Tenting is not equivalent. Actual BGA land patterns and the functional-ball escape must be qualified before choosing this route. For example, at literal 4/4 mil width/clearance, one channel between equal 0.65 mm pitch lands requires land diameter at most 0.3452 mm; at 0.50 mm pitch the bound is 0.1952 mm. A through-via's inner-layer hole keepout can be more restrictive. The report includes a separately sourced HDI alternative; no blind-via geometry is silently added to the through-hole catalog stack.

Before any fabrication release, one factory and assembler must accept the whole combination: finished holes/tooling and all-layer annuli; drill-to-route/copper registration; masks and residual castellations; four-edge panel retention; final laminate/pressed stack and impedance; qualified BGA lands/vias and escape; mating alignment/soldering; and hot-condition PDN/thermal performance. This proposal closes the dimensional definition step, not those remaining acceptance gates.

## Independent verification

The [independent geometry review](castellation-proposal-independent-review.json) passes 47/47 checks, including all 140 library and board pads, contact mapping, the original carrier shape, exact-curve overlap, continuous translation/rotation bounds and final input hashes. The isolated KiCad 9.0.2 DRC reports zero violations with edge-clearance checks enabled and no exclusions. The approximately 8.35 × 10⁻⁹ mm² maximum numerical difference between separate integration methods is below the documented 10⁻⁷ mm² comparison tolerance. This verifies the nominal proposal and its calculations; it does not close the process gates above.

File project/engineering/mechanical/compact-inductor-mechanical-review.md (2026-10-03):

# Compact-inductor mechanical reservation review

Status: mechanical candidate only, not electrically selected or approved for manufacture. Scope is L24/L25/L26. No integrated CAD, BOM, netlist, or baseline-area file has been changed.

Latest-status note: the area scenarios below are frozen historical comparisons. The subsequent Schmitt-AND correction removes U96 and changes the optional monitor topology; no total below describes the latest consolidated BOM. Per-inductor mechanical dimensions and candidate reservation deltas remain applicable.

## Result

Murata DFE201610E-R47M=P2 permits a substantially smaller *candidate reservation*. A provisional 0.25 mm clearance around the union of maximum body and recommended lands produces 2.9 x 2.3 mm = 6.67 mm² per inductor. Replacing the existing 21.16 mm² reservation for each of L24/L25/L26 would save 14.49 mm² each, 43.47 mm² total.

Applied only to the frozen area-screen snapshot cited below, the dense full-BOM area sum would be 1175.03 mm², still 19.03 mm² above its provisional 1156 mm² inner region. This is not the latest full-design total: the parent reports that a fifth AUP U96 has since been added and other packages are under review. This alternative alone does not clear the optimistic area screen. Even an area sum below the region would not establish packing, BGA escape, routing, decoupling, thermal, EMI, or single-side assembly feasibility.

## Official drawing reviewed

- [Murata reference specification](https://pim.murata.com/asset/pim4/inductor/J(E)TE243A-0001_PDF_INDUCTOR), document J(E)TE243A-0001E-01, 10 pages. The legacy official URL redirects here. Exact DFE201610E-R47M=P2 row is on page 2. Source is marked Reference Only; its ordering note requires confirmation of product specifications before ordering.
- Page 1 physical drawing: body length 2.0 +/- 0.2 mm; width 1.6 +/- 0.2 mm; height 1.0 mm maximum. Maximum XY body is 2.2 x 1.8 mm. End-terminal depth callout is 0.5 +/- 0.3 mm along the length; opposed end terminals are shown. The document does not furnish an additional terminal thickness or coplanarity tolerance in this view.
- Page 5 recommended PCB pattern: outer span 2.4 mm, width 1.8 mm, gap between the two equal rectangular pads 0.8 mm. Therefore pad length is (2.4 - 0.8)/2 = 0.8 mm and pad-center pitch is 1.6 mm. Centering the drawing gives centers (-0.8, 0) and (+0.8, 0) mm for 0.8 x 1.8 mm pads. These are a mechanical interpretation, not an issued fabrication footprint.
- Body and PCB-pattern drawings were visually reviewed from the downloaded PDF, rather than inferred from nominal case code or PDF text. Pages 1, 5, and 7 were rendered and inspected. Page 1 had also been inspected in dot's cloud browser.
- [TI TPS62827 family datasheet](https://www.ti.com/lit/ds/symlink/tps62827.pdf), SLVSEF9I, March 2024 revision, page 13 Table 8-5, names DFE201610E-R47M and nominal 2.0 x 1.6 x 1.0 mm dimensions. This is candidate provenance, not rail qualification or a source for package tolerances. The supplied local TI page was visually reviewed.

## Courtyard assumptions and area sensitivity

The manufacturer does not define a courtyard in the reviewed source. Start with the bounding union of maximum physical body (2.2 x 1.8 mm) and recommended lands (2.4 x 1.8 mm): 2.4 x 1.8 mm. Add the stated margin on every side. No board-routing corridor or thermal-spreading area is included.

| Assumed clearance per side | Candidate reservation | Each | Three | Savings vs existing three | Dense full-BOM sum | Excess over provisional inner area |
| --- | --- | ---: | ---: | ---: | ---: | ---: |
| 0.25 mm | 2.90 x 2.30 mm | 6.67 mm² | 20.01 mm² | 43.47 mm² | 1175.03 mm² | 19.03 mm² |
| 0.30 mm | 3.00 x 2.40 mm | 7.20 mm² | 21.60 mm² | 41.88 mm² | 1176.62 mm² | 20.62 mm² |
| 0.50 mm | 3.40 x 2.80 mm | 9.52 mm² | 28.56 mm² | 34.92 mm² | 1183.58 mm² | 27.58 mm² |

Existing area basis is full-bom-area-screen.json: three 21.16 mm² reservations = 63.48 mm², dense sum 1218.50 mm². Values remain unselected reservations. The primary scenario leaves 19.03 mm² of *excess*, not spare area. The 0402-passive sum becomes 1312.81 mm² in the same primary scenario, 156.81 mm² above the provisional inner region. The region assumes a 2 mm perimeter band inside 38 x 38 mm; it is not recovered original mechanical geometry.

### Separate hypothetical solder-mask sensitivity

If a later board process chooses +0.05 mm mask expansion at every copper-land edge and 0.25 mm assembly clearance outside the resulting mask envelope, the hypothetical 2.5 x 1.9 mm mask span leads to a 3.0 x 2.4 mm = 7.20 mm² reservation. Savings would be 13.96 mm² per instance or 41.88 mm² for three. This is a separately labeled sensitivity case. It happens to equal the second table row, whose 0.30 mm margin was applied directly to the body/land union. No final mask geometry is chosen or claimed; the manufacturer source supplies none.

## Layout conditions and unresolved details

- Murata page 7 prohibits through holes and copper below the coil except copper to its electrodes. The source does not specify a layer exemption; do not assume inner copper or vias are permitted without clarification. A land-pattern-only area calculation does not remove this layout constraint.
- Murata page 7 also requires that neighboring components not contact this product. The selected clearance is an explicit screening assumption and needs assembly/rework approval.
- No manufacturer courtyard, paste/stencil dimensions, solder-mask expansion, land dimensional tolerance, or placement tolerance is supplied in the reviewed pattern. These remain open.
- This review makes no electrical selection. In particular, TI's 4.8 A table entry must not be read as continuous-current approval: Murata page 2 separately lists 4.8 A at its inductance-change criterion and 3.6 A at its temperature-rise criterion. Actual rail peak/RMS current, loss, temperature, saturation, stability/transients and qualification require separate analysis.
- Final supply status, ordering specification and application qualification are outside this mechanical review.

## Evidence and reproduction

The source PDF and rendered manufacturer pages are kept outside the distributable design tree in the shared reference directory. Their precise paths and source hash are in compact-inductor-mechanical-review.json. PDF SHA-256: 5c02415289b2b9d2c0ceb283cfe004a986d9e729dadbfe92917a381db5eae84e.

Arithmetic is recomputed from the existing area-screen JSON using exact decimal values. Only the three specified inductor reservations change in the hypothetical sums; all other assumptions remain as stated by that baseline. The JSON includes 0.25, 0.30, and 0.50 mm per-side sensitivity cases.

Frozen baseline SHA-256: f0e43cb06da1f73f0a66e424a0af90c178ac351d479c2cade8481b321131c3a6. File modification time recorded at review: 2026-09-30T11:54:18.679739+00:00. Snapshot first read for this review: 2026-09-30T12:00:54Z. Per-instance and three-instance savings can be reapplied to a future verified full-BOM baseline; the hypothetical historical totals must not be presented as latest design fit.

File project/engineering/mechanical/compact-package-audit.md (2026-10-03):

# Compact-package audit: Schmitt correction and alternatives

Date: 2026-09-30. Scope: package-only alternatives for selected AUP logic, TPS3808 supervisors, and mechanical inductor reservations. This is a derived engineering review, not a production release or master-CAD edit. No capacitors were removed or values changed to force an area result.

## Latest correction: SN74AUP1G97 Schmitt AND

This supersedes the earlier proposed 1G08/1G17 reset arrangement and its area scenarios. U92/U94 now use SN74AUP1G97DRLR, U91/U93 retain SN74AUP1G07/06 DRL5, and U89/U90 retain TPS3808 DRV with grounded EP7. U96 and its capacitor are removed by the design lead. The optional eight-rail monitor network is omitted from the latest topology. No old area total below describes that latest BOM.

The 100 kΩ / 100 nF external-reset RC creates slow edges, so this is an electrical Schmitt-input correction, not a pin-equivalent package change from 1G08. Official SN74AUP1G97 pp1-3 show B=pin1, GND=pin2, A=pin3, Y=pin4, VCC=pin5, C=pin6. All inputs are Schmitt-trigger. Page2's eight truth rows and page3's Figure4 confirm Y=(C?A:B); tying B pin1 to GND gives Y=A AND C. Pin2 must also connect GND. Both signal inputs therefore enter A3 and C6. No input is left floating.

New footprint: `CMK230_Compact_Candidates:TI_DRL0006A_AUP1G97_DrawingVerified_CANDIDATE`. It is in the same compact library. Six-pad drawing DRL0006A, 4223266/F, 11/2024, pp18-20: each copper land is 0.67 x 0.30 mm R0.05; x=±0.74 mm; y=-0.50,0,+0.50 mm. Pins 1/2/3 run down the left; 6/5/4 run down the right. Body X 1.1-1.3 mm, Y1.5-1.7 mm; height 0.6 mm max; allowed extra body flash 0.15 mm per side. The chosen courtyard remains 2.8 x 2.5 mm (7.00 mm²). Explicit NSMD mask openings use selected +0.05 mm per side, R0.10. Paste is 1:1 with copper; TI example stencil 0.100 mm. No exposed pad is present.

Updated verification covers all four compact alternatives: 302 native numeric checks, 23 copper/23 mask/24 paste Gerber apertures checked, zero isolated geometry-DRC violations. `compact-AUP1G97-status.json`, function-pin CSV and truth-table CSV preserve the specific logic evidence. No integrated master was edited by this footprint audit. Other compact footprints remain alternatives; they are not authorization to restore the obsolete reset topology.

## Historical decision-level result (superseded for latest BOM)

DRL is the useful logic-package candidate. The same SN74AUP1G06/07/08/17 base part can move from DBV to DRL without changing numbered signals. TPS3808G01 can use2x2 mm DRV WSON, but all six signals must be remapped and the grounded exposed pad added. Neither change selects the other logic functions or changes the intended supply/logic role.

For five AUP instances (U91, U92, U93, U94, U96) plus two TPS3808 instances (U89, U90), the chosen candidate envelopes recover 30.04 mm² compared with seven 11.52 mm² boxes in the rough screening convention. The DFE201610E-R47M inductor mechanical alternative can recover another 43.47 mm² for L24/L25/L26, or 41.88 mm² with the separately labeled mask-margin sensitivity. Electrical/thermal inductor qualification remains the design lead's task.

Those savings do not establish full-board fit. On the frozen 269-part area-screen baseline, then adding only the new U96 in DRL, the combined optimistic arithmetic is 1156.51 mm² against a provisional 1156 mm² interior. The mask-margin sensitivity gives 1158.10 mm². These limited counterfactual sums omit any other BOM updates and the new gate's support parts; they are not the latest full-design estimate. A zero/negative area difference would still not prove packing, local decoupling, fanout, routing, thermal or PDN feasibility.

## Exact electrical-pin equivalence

Official pin-function pages are page 3 of each AUP PDF, visually inspected:

- SN74AUP1G06: pin 1 NC,2 A,3 GND,4 Y (inverting open drain),5 VCC for DBV/DCK/DRL
- SN74AUP1G07: pin 1 NC,2 A,3 GND,4 Y (noninverting open drain),5 VCC for DBV/DCK/DRL
- SN74AUP1G08: pin 1 A,2 B,3 GND,4 Y (AND),5 VCC for DBV/DCK/DRL
- SN74AUP1G17: pin 1 NC,2 A,3 GND,4 Y (noninverting Schmitt buffer),5 VCC for DBV/DCK/DRL

This supports package-only substitution within each named base part. The functions are not interchangeable across these part numbers. Different package parasitics/thermal behavior and the application's voltage/temperature limits still require design review. All four DRLR ordering codes appear in their official package-option addenda; no stock or procurement guarantee is made.

Official TPS3808 pin table, page 4, requires DBV→DRV remapping:

| Function | DBV pin | DRV pin |
|---|---:|---:|
| RESET_N |1|6|
| GND |2|5|
| MR_N |3|4|
| CT |4|3|
| SENSE |5|2|
| VDD |6|1|
| Exposed thermal pad, connect GND | none |7|

The drawing labels the exposed land7. Data-sheet instructions require connecting the thermal pad to the ground plane; the package drawing requires soldering it. Add an explicit EP7 symbol pin and verify the real netlist after substitution. Renumbering only footprint pads to hide the package difference is not the recommended audit trail.

Current source assignments intentionally leave DBV CT pin 4 open for 20 ms timing. Retain that intentional open condition on DRV pin 3 if the same timing is retained. A current U89/U90 net adaptation is provided, but the supervisor circuit is being consolidated; recheck against the latest master before editing. This audit made no integration changes.

## Official drawings and chosen envelopes

The actual PDF pixels were inspected, not just extracted text. The full original PDFs and rendered source images remain outside this distributable directory. `compact-TI-source-manifest.json` records exact local hashes, official URLs and pages.

### AUP DRL0005A

Source drawing 4220753/E,11/2024. SN74AUP1G08 pp34-36;1G06 pp49-51;1G07 pp45-47;1G17 pp35-37.

- Body X 1.1-1.3 mm, Y1.5-1.7 mm; maximum height 0.6 mm; overall lead span1.5-1.7 mm
- Body drawing excludes mold flash/protrusions/gate burrs up to0.15 mm per side
- Five exposed metal lands 0.67x0.30 mm, R0.05. Centers x=±0.74; left y=-0.50,0,+0.50; right pin 4 y=+0.50, pin 5 y=-0.50
- NSMD preferred; selected explicit0.05 mm mask expansion equals the drawing maximum. Stencil 1:1 with lands, example 0.100 mm thick
- Chosen courtyard 2.8x2.5 mm=7.00 mm². Copper/mask drives X; body maximum plus flash drives Y. Source does not prescribe this courtyard

### AUP DCK0005A

Source drawing 4214834/G,11/2024. SN74AUP1G08 pp50-52;1G06 pp33-35;1G07 pp32-34.

- Body X 1.1-1.4 mm, Y1.85-2.15 mm; maximum height1.1 mm; overall lead span1.8-2.4 mm
- Up to0.25 mm body flash/protrusion per side is excluded from body dimensions
- Five 0.95x0.40 mm exposed lands, R0.05. Centers x=±1.10, left y=-0.65,0,+0.65; pin 4 lower right, pin 5 upper right
- NSMD preferred; selected 0.05 mm expansion is within TI 0.07 mm maximum. Stencil 1:1, example 0.125 mm thick
- Chosen courtyard 3.8x3.2 mm=12.16 mm². It does not beat the current 11.52 mm² rough DBV box because the latter is an optimistic screening assumption. It is not evidence that a DCK body is larger than DBV

### TPS3808 DRV0006A / DRV0006D

TPS3808 RevN PDF pp30-35 contains DRV0006D 4225563/A12/2019 and DRV0006A 4222173/C11/2025. Their board and stencil examples are geometrically identical; optional side-wall/wettable-flank package details do not change these board lands.

- Body 1.9-2.1 mm on both axes, maximum height0.8 mm
- Six 0.45x0.30 mm side lands, R0.05, x=±0.975; y=-0.65,0,+0.65. Component-side numbering1/2/3 down left,6/5/4 down right
- Exposed pad 7:1.0x1.6 mm copper, R0.05, center0,0
- NSMD preferred, chosen0.05 mm mask expansion within TI 0.07 mm maximum. Explicit mask pad 7 is1.1x1.7 mm
- Side lands use1:1 paste. EP7 uses two1.0x0.7 mm R0.05 apertures at 0,±0.45. The nominal rectangular area ratio is87.5%, rounded to88% in the TI drawing; rounding corners gives approximately87.35%. Do not replace this with one full-area EP paste aperture
- TI example stencil0.125 mm. Optional0.2 mm thermal vias shown in the drawing are not instantiated; via fill/cap/stackup/process choices remain unqualified
- Chosen courtyard 3.0x2.6 mm=7.80 mm²

## Area comparison and its limits

All candidate courtyards add at least 0.25 mm outside the relevant maximum body/flash, copper and selected mask aperture envelope, rounded outward to 0.05 mm. They are project assumptions, not TI specifications or routing keepouts.

| Alternative | Rough existing reservation each | Candidate each | Saving each |
|---|---:|---:|---:|
| AUP DBV→DRL |11.52|7.00|4.52|
| AUP DBV→DCK |11.52|12.16|-0.64|
| TPS3808 DBV→DRV |11.52|7.80|3.72|
| L24/L25/L26→DFE201610E, body/land reservation |21.16|6.67|14.49|
| Same inductor, hypothetical mask sensitivity |21.16|7.20|13.96|

Units aremm². The existing rough DBV box is not a verified same-policy footprint area: for example the prior official DBV0005A reconstruction using full flash/mask allowance occupied 17.63 mm². Therefore the savings above are modifications to the documented optimistic screen, not a comprehensive remeasurement of all 269+ components. More exact choices can increase other reservations.

`compact-area-scenarios.json` preserves baseline hash and the limited scenario arithmetic. No original baseline file was overwritten. Do not present its frozen sums as the latest consolidated BOM or infer spare routing area.
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

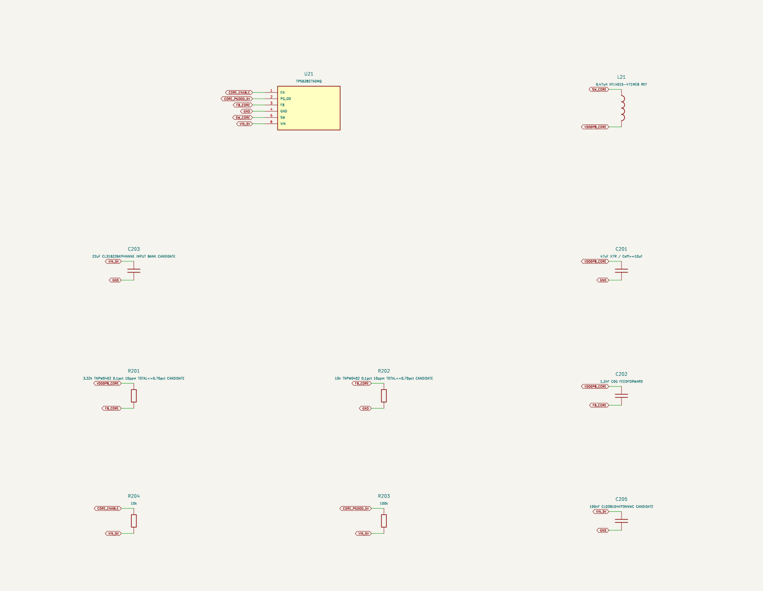
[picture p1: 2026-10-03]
project/recovery/r12-input-bank-candidate/core-input.png

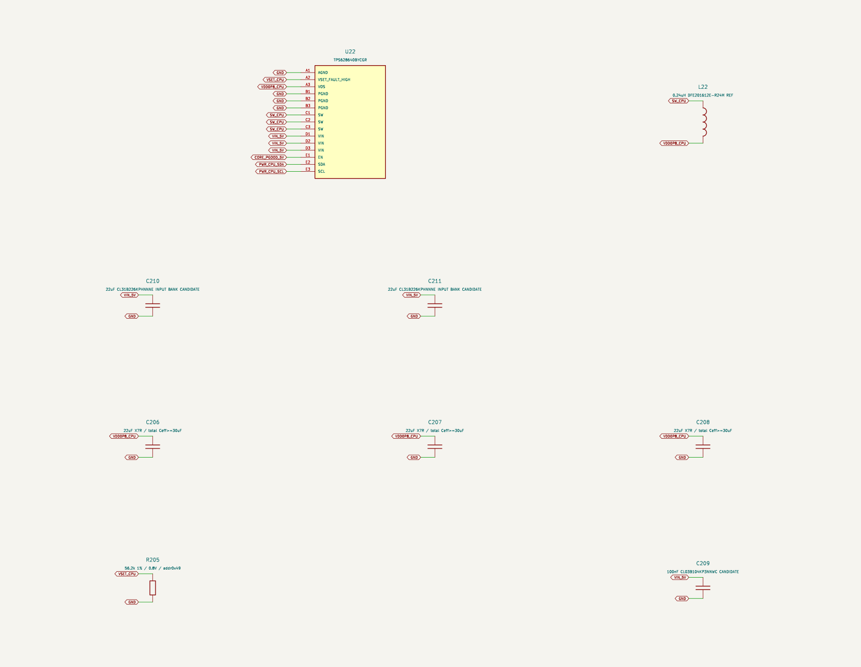
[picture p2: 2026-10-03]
project/recovery/r12-input-bank-candidate/cpu-input.png

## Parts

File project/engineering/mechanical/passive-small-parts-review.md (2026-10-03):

# Dense small passives: electrical and mounting screen

2026-09-30; compact 237-populated-part, 243-envelope design snapshot. The 0201 scenario contains 106 capacitor and 49 resistor envelopes at 1.1 × 0.7 mm. It already assigns larger boxes to all 1–47 µF capacitors, the precision feedback/sense resistors, the high-current R220 link, ferrites and power inductors. There is no basis to reject every 0201 assignment merely from the package name.

## Capacitors and unreserved bulk

Later source clarification from the design lead: the reference PLL/VAA filters use 100 nF local capacitors; the old “local bulk TBD” labels were speculative. No missing required bulk has been established or removed. The lead has added two source-backed MIPI 100 nF capacitors to the newer design. The counts and eleven-position sensitivity below describe this report's earlier snapshot, not a claim that eleven extra capacitors are required.

Six 100 nF bypass capacitors C205/C209/C215/C222/C227/C232 are directly on VIN_5V. A 6.3 V rating alone leaves limited supply-overshoot margin; a concrete 10 V option is preferable for the screening candidate. Official Samsung CL03B104KP3NNWC is a 0201 100 nF, 10 V X7R option; the separate capacitor review records its dimensions and typical bias curve. At 5 V it is approximately 56.8 nF, so “100 nF nominal fits” does not mean “100 nF effective is provided.” Most other 100 nF parts sit on 0.8/1.1/1.8/3.3 V rails, and still need rail-specific PDN acceptance.

C233–C238 and C240–C244 explicitly say “100nF REF / local bulk TBD.” Their present small boxes do not reserve additional bulk. If an additional 0603-like 2.2 × 1.3 mm capacitor is needed at each of these eleven sites, keeping the existing bypass parts adds **31.46 mm²** and eleven placements; an additional 0402-like 1.6 × 1.0 mm part each adds **17.60 mm²**. These are sensitivity cases, not recommendations to add eleven parts or to replace/remove the existing bypass capacitors. Filter impedance, load steps and analog-noise results determine actual need.

System ambient and local component temperature limits have not been established. The memory devices' case-temperature specification is not an 85°C board-ambient specification. An X5R alternative must not be substituted for the frozen X7R wording without a justified temperature range and effective-capacitance margin.

## Resistors and jumpers

Vishay CRCW0201 e3 provides a concrete ordinary-resistor family: 50 mW rating at 70°C, 30 V limiting element voltage, 1% grades, and a zero-ohm option CRCW02010000Z0ED specified at 50 mΩ maximum and 1 A maximum at 70°C. Its official 2022-09-21 drawing (document 20052 p2, inspected visually) gives body 0.60±0.03 × 0.30±0.03 × 0.23±0.03 mm; recommended copper pads 0.28 × 0.43 mm with 0.23 mm inner gap. The outer copper envelope is 0.79 × 0.43 mm, fitting the current 1.1 × 0.7 reservation with 0.155/0.135 mm per-side allowance. Mask, stencil and assembly clearance remain unqualified. A blanket 0.25 mm courtyard convention would enlarge even these small parts; the dense boxes are explicitly a denser assembly assumption.

For ordinary pull-ups/pull-downs, rated voltage is ample: 5.5 V across 10 kΩ is 3.03 mW; 3.3 V across 10 kΩ is 1.09 mW. The 1.1 V, two-240 Ω DDR_VREF divider dissipates approximately 1.26 mW in each resistor. This supports plausibility, not lifetime or signal-integrity qualification. R63/R64/R69–R71 calibration resistors need their actual pin currents and temperature accuracy checked; assigning the entire rail voltage to a calibration pin is not a valid substitute for that check. Existing total-error≤0.15% feedback and guard-divider parts are already excluded from the generic 0201 bin; a commodity 1% resistor cannot satisfy that budget.

**R561 is a supply feed, not a logic pull-up.** The lead's visually checked Samsung eMMC Table 33 gives 180 mA controller and 50 mA NAND for the 16 GB device under x8 HS400, using 100 ms RMS averaging. It does not guarantee transient peak current. At 180 mA, a 50 mΩ link contributes up to 9 mV and 1.62 mW using the published room-condition resistance, before PCB drop and temperature. A 0201 jumper is therefore not ruled out by that RMS figure, but peak/inrush, thermal derating and the 1.70 V minimum VCCQ margin must be qualified. If later enlarged to the existing 0402 reservation convention, R561 adds 0.83 mm².

R221 feeds the K230 VDD3P3_SD branch, for which the lead reports a 50 mA guide budget; it does not supply an external TF card's main supply. At 50 mA and 50 mΩ, link drop is 2.5 mV and dissipation 0.125 mW. Do not reject its 0201 reservation based on an assumed external-card load. A 0402 sensitivity for both R221 and R561 together is +1.66 mm², not a required correction established by this audit. R220 remains the separately selected 0603 low-ohmic power link.

## Concrete power-feed candidate and R220 correction

For a coherent conservative power-feed candidate, use **Vishay WFZ040200000ZE66** at R561 for review: 0402 metal-foil jumper, 3 mΩ maximum, 6.5 A published current rating with temperature derating (power derating begins at 70°C). Its body is 1.00±0.10 × 0.50±0.10 × 0.40±0.10 mm. The official p2 drawing gives two 0.50 × 0.60 mm pads with 0.40 mm gap, a 1.40 × 0.60 mm land envelope. Adding hypothetical 0.05 mm mask and 0.25 mm clearance gives a **2.0 × 1.2 mm reservation**, +1.63 mm² over R561's current box. At 180 mA and 3 mΩ, the room-condition link drop is 0.54 mV and loss 0.0972 mW. PCB and contact resistance, peak/inrush and operating temperature still require system acceptance. This exact MPN is listed on Vishay's product quality page; no purchase or procurement commitment was made.

**R220's reservation correction:** its already specified WSL060300000ZEA9 has two recommended 1.01 × 1.01 mm pads and 0.50 mm gap, hence a 2.52 × 1.01 mm copper envelope. This cannot fit the old 2.2 × 1.3 mm box. With the same hypothetical mask/clearance convention, round outward to **3.2 × 1.7 mm**, adding 2.58 mm². Vishay's 2026-08-24 WSL-9 p2 drawing was inspected visually. The lead subsequently authorized this reservation correction and R561's 2.0×1.2 mm candidate reservation in the current area tool. R220's circuit was not changed by this audit; do not add these already-applied deltas to the current baseline a second time.

## Concrete smaller ferrite candidate

Murata **BLM15PX121SN1D** is a 0402 DC-power-line ferrite with 120 Ω ±25% at 100 MHz; initial DCR≤0.055 Ω, post-test limit 0.070 Ω; rated current 2.0 A at 85°C, linearly derated to 1.1 A at 125°C. Body is 1.00±0.05 × 0.50±0.05 mm, height 0.50±0.05 mm. This meets the nominal impedance/DCR wording of FB202–FB210, but is not a complete electrical selection: biased impedance, noise attenuation, DC voltage drop, filter resonance and branch current must be reviewed.

Official drawing JENF243A_0018AR-01 pp3/4/9 was visually inspected. Recommended pad opening dimensions are gap a=0.4, outer span b=1.2, width c=0.5 mm. The manufacturer's power-line copper extension dimension d depends on current class and copper thickness. For the 2.2-A-or-lower row, d is 1.2 mm at 18 µm foil, 0.7 mm at 35 µm, and 0.5 mm at 70 µm. Thus a generic two-pad 0402 footprint must not erase the copper/current condition.

Using a **hypothetical** 0.05 mm mask expansion and 0.25 mm clearance around the union of maximum body, mask and local copper, then rounding outward, gives these provisional reservations:

| Foil thickness | Reservation | Area per bead | Delta for nine versus current 2.2×1.3 |
|---|---:|---:|---:|
| 18 µm | 1.8×1.7 mm | 3.06 mm² | +1.80 mm² |
| 35 µm | 1.8×1.2 mm | 2.16 mm² | −6.30 mm² |
| 70 µm | 1.8×1.1 mm | 1.98 mm² | −7.92 mm² |

These figures exclude the continuing power traces and route space. They do not authorize changing all nine parts, copper thickness or the PCB stackup. No ferrite footprint or master edit is made.

## Sources

- [Vishay CRCW0201 e3](https://www.vishay.com/docs/20052/crcw0201e3.pdf), SHA-256 `95854b1c87ad23bded6a4bc3f6c09c1d6fedb230cada90c6c80b39376ad35af1`; [exact jumper order code](https://www.vishay.com/en/product/20052/tab/quality/)
- [Vishay WFZ jumper specification](https://www.vishay.com/docs/30432/wfz-jumper.pdf), SHA-256 `e848e86d529942d7992878b21873481261d0f01f8511f236cb1ed8ad4b178352`; [exact WFZ040200000ZE66 listing](https://www.vishay.com/en/product/30432/tab/quality/); [WSL-9 existing power jumper](https://www.vishay.com/docs/30192/wsl-9.pdf)
- [Murata BLM15PX121SN1 current product page](https://pim.murata.com/en-us/pim/details/?partNum=BLM15PX121SN1%23); [official detailed specification](https://pim.murata.com/asset/pim4/ferriteBeadInductortypefilter/ENFA0018_PDF_FERRITEBEADINDUCTORTYPEFILTER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), SHA-256 `26e3632f29268632a2ae03ce1b86b971044e76f3b1ad7dbe24eb5c39f4f6c5ee`
- Existing project source Samsung `emmc.pdf` p25, Table 33, provided by the lead; power/signal roles checked against the frozen integrated `master.xml`

Manufacturer originals remain outside the distributable design tree. This report identifies plausible candidates and unresolved requirements; it establishes neither full-board fit nor routed/thermal/PDN feasibility.

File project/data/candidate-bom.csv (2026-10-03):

block | reference_candidate | qty | description | status | release_requirement
SoC | K230 | 1 | VFBGA390 13x13mm 0.65mm pitch | architecture candidate | Official full ball map and lifecycle; verify all power and reserved pins
RAM | K4F8E304HB-MGCJ | 1 | 8Gb LPDDR4; 2 channels x16; 200FBGA 10x15mm | Canaan verified model; Samsung datasheet checked | Exact package land pattern; channel and DQ/CA matrix; procurement; DDR training
eMMC | KLMAG1JETD-B041 | 1 | 16GB eMMC5.1; 153FBGA 11.5x13x0.8mm; host use HS200 | Samsung-authored datasheet checked from mirror | Lifecycle and availability; ball map; VCCQ-bank voltage; boot validation
CORE regulator | TPS62827A DMQ | 1 | Independent rail sized against peak and continuous load | Connected candidate; independently checked pins/divider | 4A rating;0.7992V nominal;dynamic/ripple/thermal and footprint validation
CPU regulator | TPS628640BYCGR | 1 | DVFS-capable rail | Connected candidate;0.8V startup;private CPU bus | 0x49;GPIO65/66 open-drain firmware and voltage-frequency validation
KPU regulator | TPS628640BYCGR | 1 | DVFS-capable rail | Connected candidate;0.8V startup;private KPU bus | 0x49;GPIO67/69 open-drain firmware and voltage-frequency validation
DDR and IO regulators | TPS62826A / TPS62825A | 3 | Appropriate DDR 1.1V/1.8V and 3.3V/1.8V network supplies | Connected candidates | 1.107V/1.8V/3.318V nominal;effective capacitance;transient and external loads
Analog supply filters | Ferrites and local capacitors | 9 ferrites | Reference-style isolated supply branches;common filtered PMU rail | Connected candidate;not ripple qualified | DCR/current/noise/resonance checks;LDO alternative if analog noise targets require
Main crystal | TBD | 1 | 24MHz; target <=20ppm; package and loading to be designed | requirement only | Crystal datasheet ESR and load; matched capacitors; startup test
RTC crystal | TBD | 1 | 32.768kHz; target <=20ppm | requirement only | RTC voltage network; load and startup test
Passives and protection | TBD | TBD | Decoupling; calibration; straps; filtering; protection | not selected | Complete reference schematic audit; actual rail and layout values

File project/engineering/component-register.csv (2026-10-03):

reference | value_or_candidate | footprint | DNP | excluded_from_BOM | stage | blocking_value | notes
U1 | K230 full 390 physical balls |  | False | False | REVIEW_ONLY_NOT_PROCUREMENT |  | Footprint and exact sourcing not released
U2 | K4F8E304HB 1GB LPDDR4 REVIEW |  | False | False | REVIEW_ONLY_NOT_PROCUREMENT |  | Footprint and exact sourcing not released
U3 | KLMAG1JETD 16GB eMMC REVIEW |  | False | False | REVIEW_ONLY_NOT_PROCUREMENT |  | Footprint and exact sourcing not released
J1 | CM-K230 edge contract ONLY |  | False | True | REVIEW_ONLY_NOT_PROCUREMENT |  | 140-pad interface model; not a physical extra connector
C41 | 12pF REF / TUNE |  | False | False | REVIEW_ONLY_NOT_PROCUREMENT |  | Footprint and exact sourcing not released
C42 | 12pF REF / TUNE |  | False | False | REVIEW_ONLY_NOT_PROCUREMENT |  | Footprint and exact sourcing not released
C43 | 12pF REF / TUNE |  | False | False | REVIEW_ONLY_NOT_PROCUREMENT |  | Footprint and exact sourcing not released
C44 | 12pF REF / TUNE |  | False | False | REVIEW_ONLY_NOT_PROCUREMENT |  | Footprint and exact sourcing not released
C45 | 100nF REF |  | False | False | REVIEW_ONLY_NOT_PROCUREMENT |  | Footprint and exact sourcing not released
R41 | 1M REF |  | False | False | REVIEW_ONLY_NOT_PROCUREMENT |  | Footprint and exact sourcing not released
R42 | 1M REF |  | False | False | REVIEW_ONLY_NOT_PROCUREMENT |  | Footprint and exact sourcing not released
R43 | 100k REF |  | False | False | REVIEW_ONLY_NOT_PROCUREMENT |  | Footprint and exact sourcing not released
R44 | 10k BOOT0 LOW |  | False | False | REVIEW_ONLY_NOT_PROCUREMENT |  | Footprint and exact sourcing not released
R45 | 10k BOOT0 HIGH / DNP |  | True | False | REVIEW_ONLY_NOT_PROCUREMENT |  | Footprint and exact sourcing not released
R46 | 10k BOOT1 HIGH |  | False | False | REVIEW_ONLY_NOT_PROCUREMENT |  | Footprint and exact sourcing not released
R47 | 10k BOOT1 LOW / DNP |  | True | False | REVIEW_ONLY_NOT_PROCUREMENT |  | Footprint and exact sourcing not released
Y1 | 32.768kHz / MPN TBD |  | False | False | REVIEW_ONLY_NOT_PROCUREMENT | YES | Footprint and exact sourcing not released
Y2 | 24MHz / MPN TBD |  | False | False | REVIEW_ONLY_NOT_PROCUREMENT | YES | Footprint and exact sourcing not released
C31 | 100nF |  | False | False | REVIEW_ONLY_NOT_PROCUREMENT |  | Footprint and exact sourcing not released
C32 | 100nF |  | False | False | REVIEW_ONLY_NOT_PROCUREMENT |  | Footprint and exact sourcing not released
C33 | 100nF |  | False | False | REVIEW_ONLY_NOT_PROCUREMENT |  | Footprint and exact sourcing not released
C34 | 100nF |  | False | False | REVIEW_ONLY_NOT_PROCUREMENT |  | Footprint and exact sourcing not released
JP1 | OPEN=EMMC / CLOSED=TF; COLD ONLY |  | True | False | REVIEW_ONLY_NOT_PROCUREMENT |  | Footprint and exact sourcing not released
R31 | 10k |  | False | False | REVIEW_ONLY_NOT_PROCUREMENT |  | Footprint and exact sourcing not released
R32 | 10k |  | False | False | REVIEW_ONLY_NOT_PROCUREMENT |  | Footprint and exact sourcing not released
R33 | 10k |  | False | False | REVIEW_ONLY_NOT_PROCUREMENT |  | Footprint and exact sourcing not released
R34 | 10k RESET BIAS |  | False | False | REVIEW_ONLY_NOT_PROCUREMENT |  | Footprint and exact sourcing not released
U11 | TMUX1574RSVR / CANDIDATE |  | False | False | REVIEW_ONLY_NOT_PROCUREMENT |  | Footprint and exact sourcing not released
U12 | TMUX1574RSVR / CANDIDATE |  | False | False | REVIEW_ONLY_NOT_PROCUREMENT |  | Footprint and exact sourcing not released
U13 | TMUX1574RSVR / CANDIDATE |  | False | False | REVIEW_ONLY_NOT_PROCUREMENT |  | Footprint and exact sourcing not released
U14 | SN74LVC1G32DBVR |  | False | False | REVIEW_ONLY_NOT_PROCUREMENT |  | Footprint and exact sourcing not released
C201 | 47uF X7R / Ceff>=10uF |  | False | False | REVIEW_ONLY_NOT_PROCUREMENT |  | Footprint and exact sourcing not released
C202 | 120pF C0G |  | False | False | REVIEW_ONLY_NOT_PROCUREMENT |  | Footprint and exact sourcing not released
C203 | 10uF 10V X7R |  | False | False | REVIEW_ONLY_NOT_PROCUREMENT |  | Footprint and exact sourcing not released
C204 | 10uF 10V X7R |  | False | False | REVIEW_ONLY_NOT_PROCUREMENT |  | Footprint and exact sourcing not released
C205 | 100nF |  | False | False | REVIEW_ONLY_NOT_PROCUREMENT |  | Footprint and exact sourcing not released
C206 | 22uF X7R / total Ceff>=30uF |  | False | False | REVIEW_ONLY_NOT_PROCUREMENT |  | Footprint and exact sourcing not released
C207 | 22uF X7R / total Ceff>=30uF |  | False | False | REVIEW_ONLY_NOT_PROCUREMENT |  | Footprint and exact sourcing not released
C208 | 22uF X7R / total Ceff>=30uF |  | False | False | REVIEW_ONLY_NOT_PROCUREMENT |  | Footprint and exact sourcing not released
C209 | 100nF |  | False | False | REVIEW_ONLY_NOT_PROCUREMENT |  | Footprint and exact sourcing not released
C210 | 10uF 10V X7R |  | False | False | REVIEW_ONLY_NOT_PROCUREMENT |  | Footprint and exact sourcing not released
C211 | 10uF 10V X7R |  | False | False | REVIEW_ONLY_NOT_PROCUREMENT |  | Footprint and exact sourcing not released
C212 | 22uF X7R / total Ceff>=30uF |  | False | False | REVIEW_ONLY_NOT_PROCUREMENT |  | Footprint and exact sourcing not released
C213 | 22uF X7R / total Ceff>=30uF |  | False | False | REVIEW_ONLY_NOT_PROCUREMENT |  | Footprint and exact sourcing not released
C214 | 22uF X7R / total Ceff>=30uF |  | False | False | REVIEW_ONLY_NOT_PROCUREMENT |  | Footprint and exact sourcing not released
C215 | 100nF |  | False | False | REVIEW_ONLY_NOT_PROCUREMENT |  | Footprint and exact sourcing not released
C216 | 10uF 10V X7R |  | False | False | REVIEW_ONLY_NOT_PROCUREMENT |  | Footprint and exact sourcing not released
C217 | 10uF 10V X7R |  | False | False | REVIEW_ONLY_NOT_PROCUREMENT |  | Footprint and exact sourcing not released
C218 | 47uF X7R / Ceff>=10uF |  | False | False | REVIEW_ONLY_NOT_PROCUREMENT |  | Footprint and exact sourcing not released
C219 | 120pF C0G |  | False | False | REVIEW_ONLY_NOT_PROCUREMENT |  | Footprint and exact sourcing not released
C220 | 10uF 10V X7R |  | False | False | REVIEW_ONLY_NOT_PROCUREMENT |  | Footprint and exact sourcing not released
C221 | 10uF 10V X7R |  | False | False | REVIEW_ONLY_NOT_PROCUREMENT |  | Footprint and exact sourcing not released
C222 | 100nF |  | False | False | REVIEW_ONLY_NOT_PROCUREMENT |  | Footprint and exact sourcing not released
C223 | 47uF X7R / Ceff>=10uF |  | False | False | REVIEW_ONLY_NOT_PROCUREMENT |  | Footprint and exact sourcing not released
C224 | 120pF C0G |  | False | False | REVIEW_ONLY_NOT_PROCUREMENT |  | Footprint and exact sourcing not released
C225 | 10uF 10V X7R |  | False | False | REVIEW_ONLY_NOT_PROCUREMENT |  | Footprint and exact sourcing not released
C226 | 10uF 10V X7R |  | False | False | REVIEW_ONLY_NOT_PROCUREMENT |  | Footprint and exact sourcing not released
C227 | 100nF |  | False | False | REVIEW_ONLY_NOT_PROCUREMENT |  | Footprint and exact sourcing not released
C228 | 47uF X7R / Ceff>=10uF |  | False | False | REVIEW_ONLY_NOT_PROCUREMENT |  | Footprint and exact sourcing not released
C229 | 120pF C0G |  | False | False | REVIEW_ONLY_NOT_PROCUREMENT |  | Footprint and exact sourcing not released
C230 | 10uF 10V X7R |  | False | False | REVIEW_ONLY_NOT_PROCUREMENT |  | Footprint and exact sourcing not released
C231 | 10uF 10V X7R |  | False | False | REVIEW_ONLY_NOT_PROCUREMENT |  | Footprint and exact sourcing not released
C232 | 100nF |  | False | False | REVIEW_ONLY_NOT_PROCUREMENT |  | Footprint and exact sourcing not released
C233 | 100nF REF / local bulk TBD |  | False | False | REVIEW_ONLY_NOT_PROCUREMENT | YES | Footprint and exact sourcing not released
C234 | 100nF REF / local bulk TBD |  | False | False | REVIEW_ONLY_NOT_PROCUREMENT | YES | Footprint and exact sourcing not released
C235 | 100nF REF / local bulk TBD |  | False | False | REVIEW_ONLY_NOT_PROCUREMENT | YES | Footprint and exact sourcing not released
C236 | 100nF REF / local bulk TBD |  | False | False | REVIEW_ONLY_NOT_PROCUREMENT | YES | Footprint and exact sourcing not released
C237 | 100nF REF / local bulk TBD |  | False | False | REVIEW_ONLY_NOT_PROCUREMENT | YES | Footprint and exact sourcing not released
C238 | 100nF REF / local bulk TBD |  | False | False | REVIEW_ONLY_NOT_PROCUREMENT | YES | Footprint and exact sourcing not released
C239 | 100nF local second PMU ball |  | False | False | REVIEW_ONLY_NOT_PROCUREMENT |  | Footprint and exact sourcing not released
C240 | 100nF REF / local bulk TBD |  | False | False | REVIEW_ONLY_NOT_PROCUREMENT | YES | Footprint and exact sourcing not released
C241 | 100nF REF / local bulk TBD |  | False | False | REVIEW_ONLY_NOT_PROCUREMENT | YES | Footprint and exact sourcing not released
C242 | 100nF REF / local bulk TBD |  | False | False | REVIEW_ONLY_NOT_PROCUREMENT | YES | Footprint and exact sourcing not released
C243 | 100nF REF / local bulk TBD |  | False | False | REVIEW_ONLY_NOT_PROCUREMENT | YES | Footprint and exact sourcing not released
C244 | 100nF REF / local bulk TBD |  | False | False | REVIEW_ONLY_NOT_PROCUREMENT | YES | Footprint and exact sourcing not released
FB202 | 120Ohm@100MHz Rdc<=0.1Ohm |  | False | False | REVIEW_ONLY_NOT_PROCUREMENT |  | Footprint and exact sourcing not released
FB203 | 120Ohm@100MHz Rdc<=0.1Ohm |  | False | False | REVIEW_ONLY_NOT_PROCUREMENT |  | Footprint and exact sourcing not released
FB204 | 120Ohm@100MHz Rdc<=0.1Ohm |  | False | False | REVIEW_ONLY_NOT_PROCUREMENT |  | Footprint and exact sourcing not released
FB205 | 120Ohm@100MHz Rdc<=0.1Ohm |  | False | False | REVIEW_ONLY_NOT_PROCUREMENT |  | Footprint and exact sourcing not released
FB206 | 120Ohm@100MHz Rdc<=0.1Ohm |  | False | False | REVIEW_ONLY_NOT_PROCUREMENT |  | Footprint and exact sourcing not released
FB207 | 120Ohm@100MHz Rdc<=0.1Ohm |  | False | False | REVIEW_ONLY_NOT_PROCUREMENT |  | Footprint and exact sourcing not released
FB208 | 120Ohm@100MHz Rdc<=0.1Ohm |  | False | False | REVIEW_ONLY_NOT_PROCUREMENT |  | Footprint and exact sourcing not released
FB209 | 120Ohm@100MHz Rdc<=0.1Ohm |  | False | False | REVIEW_ONLY_NOT_PROCUREMENT |  | Footprint and exact sourcing not released
FB210 | 120Ohm@100MHz Rdc<=0.1Ohm |  | False | False | REVIEW_ONLY_NOT_PROCUREMENT |  | Footprint and exact sourcing not released
L21 | 0.47uH XFL4015-471MEB REF |  | False | False | REVIEW_ONLY_NOT_PROCUREMENT |  | Footprint and exact sourcing not released
L22 | 0.24uH DFE201612E-R24M REF |  | False | False | REVIEW_ONLY_NOT_PROCUREMENT |  | Footprint and exact sourcing not released
L23 | 0.24uH DFE201612E-R24M REF |  | False | False | REVIEW_ONLY_NOT_PROCUREMENT |  | Footprint and exact sourcing not released
L24 | 0.47uH XFL4015-471MEB REF |  | False | False | REVIEW_ONLY_NOT_PROCUREMENT |  | Footprint and exact sourcing not released
L25 | 0.47uH XFL4015-471MEB REF |  | False | False | REVIEW_ONLY_NOT_PROCUREMENT |  | Footprint and exact sourcing not released
L26 | 0.47uH XFL4015-471MEB REF |  | False | False | REVIEW_ONLY_NOT_PROCUREMENT |  | Footprint and exact sourcing not released
R201 | 33.2k 0.1% |  | False | False | REVIEW_ONLY_NOT_PROCUREMENT |  | Footprint and exact sourcing not released
R202 | 100k 0.1% |  | False | False | REVIEW_ONLY_NOT_PROCUREMENT |  | Footprint and exact sourcing not released
R203 | 100k |  | False | False | REVIEW_ONLY_NOT_PROCUREMENT |  | Footprint and exact sourcing not released
R204 | 10k |  | False | False | REVIEW_ONLY_NOT_PROCUREMENT |  | Footprint and exact sourcing not released
R205 | 56.2k 1% / 0.8V / addr0x49 |  | False | False | REVIEW_ONLY_NOT_PROCUREMENT |  | Footprint and exact sourcing not released
R206 | 56.2k 1% / 0.8V / addr0x49 |  | False | False | REVIEW_ONLY_NOT_PROCUREMENT |  | Footprint and exact sourcing not released
R207 | 84.5k 0.1% |  | False | False | REVIEW_ONLY_NOT_PROCUREMENT |  | Footprint and exact sourcing not released
R208 | 100k 0.1% |  | False | False | REVIEW_ONLY_NOT_PROCUREMENT |  | Footprint and exact sourcing not released
R209 | 100k |  | False | False | REVIEW_ONLY_NOT_PROCUREMENT |  | Footprint and exact sourcing not released
R210 | 200k 0.1% |  | False | False | REVIEW_ONLY_NOT_PROCUREMENT |  | Footprint and exact sourcing not released
R211 | 100k 0.1% |  | False | False | REVIEW_ONLY_NOT_PROCUREMENT |  | Footprint and exact sourcing not released
R212 | 100k |  | False | False | REVIEW_ONLY_NOT_PROCUREMENT |  | Footprint and exact sourcing not released
R213 | 453k 0.1% |  | False | False | REVIEW_ONLY_NOT_PROCUREMENT |  | Footprint and exact sourcing not released
R214 | 100k 0.1% |  | False | False | REVIEW_ONLY_NOT_PROCUREMENT |  | Footprint and exact sourcing not released
R215 | 100k |  | False | False | REVIEW_ONLY_NOT_PROCUREMENT |  | Footprint and exact sourcing not released
R216 | 4.7k |  | False | False | REVIEW_ONLY_NOT_PROCUREMENT |  | Footprint and exact sourcing not released
R217 | 4.7k |  | False | False | REVIEW_ONLY_NOT_PROCUREMENT |  | Footprint and exact sourcing not released
R218 | 4.7k |  | False | False | REVIEW_ONLY_NOT_PROCUREMENT |  | Footprint and exact sourcing not released
R219 | 4.7k |  | False | False | REVIEW_ONLY_NOT_PROCUREMENT |  | Footprint and exact sourcing not released
R220 | 0R Rmax<=50mOhm |  | False | False | REVIEW_ONLY_NOT_PROCUREMENT |  | Footprint and exact sourcing not released
R221 | 0R Rmax<=50mOhm |  | False | False | REVIEW_ONLY_NOT_PROCUREMENT |  | Footprint and exact sourcing not released
U21 | TPS62827ADMQ |  | False | False | REVIEW_ONLY_NOT_PROCUREMENT |  | Footprint and exact sourcing not released
U22 | TPS628640BYCGR |  | False | False | REVIEW_ONLY_NOT_PROCUREMENT |  | Footprint and exact sourcing not released
U23 | TPS628640BYCGR |  | False | False | REVIEW_ONLY_NOT_PROCUREMENT |  | Footprint and exact sourcing not released
U24 | TPS62826ADMQ |  | False | False | REVIEW_ONLY_NOT_PROCUREMENT |  | Footprint and exact sourcing not released
U25 | TPS62825ADMQ |  | False | False | REVIEW_ONLY_NOT_PROCUREMENT |  | Footprint and exact sourcing not released
U26 | TPS62826ADMQ |  | False | False | REVIEW_ONLY_NOT_PROCUREMENT |  | Footprint and exact sourcing not released
C61 | 100nF REF |  | False | False | REVIEW_ONLY_NOT_PROCUREMENT |  | Footprint and exact sourcing not released
C62 | 100nF REF |  | False | False | REVIEW_ONLY_NOT_PROCUREMENT |  | Footprint and exact sourcing not released
C63 | 100nF REF |  | False | False | REVIEW_ONLY_NOT_PROCUREMENT |  | Footprint and exact sourcing not released
C64 | CReg TBD - verify Samsung |  | False | False | REVIEW_ONLY_NOT_PROCUREMENT | YES | Footprint and exact sourcing not released
R61 | 10k REF |  | False | False | REVIEW_ONLY_NOT_PROCUREMENT |  | Footprint and exact sourcing not released
R62 | 10k REF |  | False | False | REVIEW_ONLY_NOT_PROCUREMENT |  | Footprint and exact sourcing not released
R63 | 240R 1% REF |  | False | False | REVIEW_ONLY_NOT_PROCUREMENT |  | Footprint and exact sourcing not released
R64 | 240R 1% REF |  | False | False | REVIEW_ONLY_NOT_PROCUREMENT |  | Footprint and exact sourcing not released
R65 | 240R 1% REF |  | False | False | REVIEW_ONLY_NOT_PROCUREMENT |  | Footprint and exact sourcing not released
R66 | 240R 1% REF |  | False | False | REVIEW_ONLY_NOT_PROCUREMENT |  | Footprint and exact sourcing not released
R67 | 30k 1% REF |  | False | False | REVIEW_ONLY_NOT_PROCUREMENT |  | Footprint and exact sourcing not released
R68 | 30k 1% REF |  | False | False | REVIEW_ONLY_NOT_PROCUREMENT |  | Footprint and exact sourcing not released
R69 | 200R 1% REF |  | False | False | REVIEW_ONLY_NOT_PROCUREMENT |  | Footprint and exact sourcing not released
R70 | 200R 1% REF |  | False | False | REVIEW_ONLY_NOT_PROCUREMENT |  | Footprint and exact sourcing not released
R71 | 200R 1% REF |  | False | False | REVIEW_ONLY_NOT_PROCUREMENT |  | Footprint and exact sourcing not released
C501 | 4.7uF |  | False | False | REVIEW_ONLY_NOT_PROCUREMENT |  | Footprint and exact sourcing not released
C502 | 4.7uF |  | False | False | REVIEW_ONLY_NOT_PROCUREMENT |  | Footprint and exact sourcing not released
C503 | 100nF |  | False | False | REVIEW_ONLY_NOT_PROCUREMENT |  | Footprint and exact sourcing not released
C504 | 100nF |  | False | False | REVIEW_ONLY_NOT_PROCUREMENT |  | Footprint and exact sourcing not released
C505 | 100nF |  | False | False | REVIEW_ONLY_NOT_PROCUREMENT |  | Footprint and exact sourcing not released
C506 | 100nF |  | False | False | REVIEW_ONLY_NOT_PROCUREMENT |  | Footprint and exact sourcing not released
C507 | 100nF |  | False | False | REVIEW_ONLY_NOT_PROCUREMENT |  | Footprint and exact sourcing not released
C508 | 100nF |  | False | False | REVIEW_ONLY_NOT_PROCUREMENT |  | Footprint and exact sourcing not released
C509 | 100nF |  | False | False | REVIEW_ONLY_NOT_PROCUREMENT |  | Footprint and exact sourcing not released
C510 | 100nF |  | False | False | REVIEW_ONLY_NOT_PROCUREMENT |  | Footprint and exact sourcing not released
C511 | 100nF |  | False | False | REVIEW_ONLY_NOT_PROCUREMENT |  | Footprint and exact sourcing not released
C512 | 100nF |  | False | False | REVIEW_ONLY_NOT_PROCUREMENT |  | Footprint and exact sourcing not released
C513 | 100nF |  | False | False | REVIEW_ONLY_NOT_PROCUREMENT |  | Footprint and exact sourcing not released
C514 | 100nF |  | False | False | REVIEW_ONLY_NOT_PROCUREMENT |  | Footprint and exact sourcing not released
C515 | 100nF |  | False | False | REVIEW_ONLY_NOT_PROCUREMENT |  | Footprint and exact sourcing not released
C516 | 100nF |  | False | False | REVIEW_ONLY_NOT_PROCUREMENT |  | Footprint and exact sourcing not released
C517 | 4.7uF |  | False | False | REVIEW_ONLY_NOT_PROCUREMENT |  | Footprint and exact sourcing not released
C518 | 100nF |  | False | False | REVIEW_ONLY_NOT_PROCUREMENT |  | Footprint and exact sourcing not released
C519 | 100nF |  | False | False | REVIEW_ONLY_NOT_PROCUREMENT |  | Footprint and exact sourcing not released
C520 | 100nF |  | False | False | REVIEW_ONLY_NOT_PROCUREMENT |  | Footprint and exact sourcing not released
C521 | 4.7uF |  | False | False | REVIEW_ONLY_NOT_PROCUREMENT |  | Footprint and exact sourcing not released
C522 | 4.7uF |  | False | False | REVIEW_ONLY_NOT_PROCUREMENT |  | Footprint and exact sourcing not released
C523 | 100nF |  | False | False | REVIEW_ONLY_NOT_PROCUREMENT |  | Footprint and exact sourcing not released
C524 | 100nF |  | False | False | REVIEW_ONLY_NOT_PROCUREMENT |  | Footprint and exact sourcing not released
C525 | 100nF |  | False | False | REVIEW_ONLY_NOT_PROCUREMENT |  | Footprint and exact sourcing not released
C526 | 100nF |  | False | False | REVIEW_ONLY_NOT_PROCUREMENT |  | Footprint and exact sourcing not released
C527 | 100nF |  | False | False | REVIEW_ONLY_NOT_PROCUREMENT |  | Footprint and exact sourcing not released
C528 | 100nF |  | False | False | REVIEW_ONLY_NOT_PROCUREMENT |  | Footprint and exact sourcing not released
C529 | 4.7uF |  | False | False | REVIEW_ONLY_NOT_PROCUREMENT |  | Footprint and exact sourcing not released
C530 | 100nF |  | False | False | REVIEW_ONLY_NOT_PROCUREMENT |  | Footprint and exact sourcing not released
C531 | 100nF |  | False | False | REVIEW_ONLY_NOT_PROCUREMENT |  | Footprint and exact sourcing not released
C532 | 100nF |  | False | False | REVIEW_ONLY_NOT_PROCUREMENT |  | Footprint and exact sourcing not released
C533 | 100nF |  | False | False | REVIEW_ONLY_NOT_PROCUREMENT |  | Footprint and exact sourcing not released
C534 | 4.7uF |  | False | False | REVIEW_ONLY_NOT_PROCUREMENT |  | Footprint and exact sourcing not released
C535 | 100nF |  | False | False | REVIEW_ONLY_NOT_PROCUREMENT |  | Footprint and exact sourcing not released
C536 | 100nF |  | False | False | REVIEW_ONLY_NOT_PROCUREMENT |  | Footprint and exact sourcing not released
C537 | 100nF |  | False | False | REVIEW_ONLY_NOT_PROCUREMENT |  | Footprint and exact sourcing not released
C538 | 100nF |  | False | False | REVIEW_ONLY_NOT_PROCUREMENT |  | Footprint and exact sourcing not released
C539 | 100nF |  | False | False | REVIEW_ONLY_NOT_PROCUREMENT |  | Footprint and exact sourcing not released
C540 | 22uF |  | False | False | REVIEW_ONLY_NOT_PROCUREMENT |  | Footprint and exact sourcing not released
C541 | 4.7uF |  | False | False | REVIEW_ONLY_NOT_PROCUREMENT |  | Footprint and exact sourcing not released
C542 | 100nF |  | False | False | REVIEW_ONLY_NOT_PROCUREMENT |  | Footprint and exact sourcing not released
C543 | 100nF |  | False | False | REVIEW_ONLY_NOT_PROCUREMENT |  | Footprint and exact sourcing not released
C544 | 100nF |  | False | False | REVIEW_ONLY_NOT_PROCUREMENT |  | Footprint and exact sourcing not released
C545 | 100nF |  | False | False | REVIEW_ONLY_NOT_PROCUREMENT |  | Footprint and exact sourcing not released
C546 | 100nF |  | False | False | REVIEW_ONLY_NOT_PROCUREMENT |  | Footprint and exact sourcing not released
C547 | 100nF |  | False | False | REVIEW_ONLY_NOT_PROCUREMENT |  | Footprint and exact sourcing not released
C548 | 100nF |  | False | False | REVIEW_ONLY_NOT_PROCUREMENT |  | Footprint and exact sourcing not released
C549 | 100nF |  | False | False | REVIEW_ONLY_NOT_PROCUREMENT |  | Footprint and exact sourcing not released
C550 | 100nF |  | False | False | REVIEW_ONLY_NOT_PROCUREMENT |  | Footprint and exact sourcing not released
C551 | 100nF |  | False | False | REVIEW_ONLY_NOT_PROCUREMENT |  | Footprint and exact sourcing not released
C552 | 22uF |  | False | False | REVIEW_ONLY_NOT_PROCUREMENT |  | Footprint and exact sourcing not released
C553 | 4.7uF |  | False | False | REVIEW_ONLY_NOT_PROCUREMENT |  | Footprint and exact sourcing not released
C554 | 100nF |  | False | False | REVIEW_ONLY_NOT_PROCUREMENT |  | Footprint and exact sourcing not released
C555 | 100nF |  | False | False | REVIEW_ONLY_NOT_PROCUREMENT |  | Footprint and exact sourcing not released
C556 | 100nF |  | False | False | REVIEW_ONLY_NOT_PROCUREMENT |  | Footprint and exact sourcing not released
C557 | 100nF |  | False | False | REVIEW_ONLY_NOT_PROCUREMENT |  | Footprint and exact sourcing not released
C558 | 100nF |  | False | False | REVIEW_ONLY_NOT_PROCUREMENT |  | Footprint and exact sourcing not released
C559 | 100nF |  | False | False | REVIEW_ONLY_NOT_PROCUREMENT |  | Footprint and exact sourcing not released
C560 | 100nF |  | False | False | REVIEW_ONLY_NOT_PROCUREMENT |  | Footprint and exact sourcing not released
C561 | 100nF |  | False | False | REVIEW_ONLY_NOT_PROCUREMENT |  | Footprint and exact sourcing not released
C562 | 22uF |  | False | False | REVIEW_ONLY_NOT_PROCUREMENT |  | Footprint and exact sourcing not released
C563 | 4.7uF |  | False | False | REVIEW_ONLY_NOT_PROCUREMENT |  | Footprint and exact sourcing not released
C564 | 100nF |  | False | False | REVIEW_ONLY_NOT_PROCUREMENT |  | Footprint and exact sourcing not released
C565 | 100nF |  | False | False | REVIEW_ONLY_NOT_PROCUREMENT |  | Footprint and exact sourcing not released
C566 | 100nF |  | False | False | REVIEW_ONLY_NOT_PROCUREMENT |  | Footprint and exact sourcing not released
C567 | 100nF |  | False | False | REVIEW_ONLY_NOT_PROCUREMENT |  | Footprint and exact sourcing not released
C568 | 100nF |  | False | False | REVIEW_ONLY_NOT_PROCUREMENT |  | Footprint and exact sourcing not released
C569 | 100nF |  | False | False | REVIEW_ONLY_NOT_PROCUREMENT |  | Footprint and exact sourcing not released
C570 | 100nF |  | False | False | REVIEW_ONLY_NOT_PROCUREMENT |  | Footprint and exact sourcing not released
C571 | 100nF |  | False | False | REVIEW_ONLY_NOT_PROCUREMENT |  | Footprint and exact sourcing not released
C572 | 100nF |  | False | False | REVIEW_ONLY_NOT_PROCUREMENT |  | Footprint and exact sourcing not released
C573 | 100nF |  | False | False | REVIEW_ONLY_NOT_PROCUREMENT |  | Footprint and exact sourcing not released
C574 | 100nF |  | False | False | REVIEW_ONLY_NOT_PROCUREMENT |  | Footprint and exact sourcing not released
C575 | 100nF |  | False | False | REVIEW_ONLY_NOT_PROCUREMENT |  | Footprint and exact sourcing not released
C576 | 100nF |  | False | False | REVIEW_ONLY_NOT_PROCUREMENT |  | Footprint and exact sourcing not released
C577 | 100nF |  | False | False | REVIEW_ONLY_NOT_PROCUREMENT |  | Footprint and exact sourcing not released

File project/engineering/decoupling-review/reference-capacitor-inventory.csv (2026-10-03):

source | pdf_page | net_as_drawn | reference | value | role | note
01studio-CanMV-K230.pdf | 3 | VDD_0V8 | C52 | 4.7uF | digital local | VDD0V8_CORE;VDD0V8_CPU;VDD0V8_KPU;VDD0V8_DDRCORE tied to common rail
01studio-CanMV-K230.pdf | 3 | VDD_0V8 | C53 | 4.7uF | digital local | VDD0V8_CORE;VDD0V8_CPU;VDD0V8_KPU;VDD0V8_DDRCORE tied to common rail
01studio-CanMV-K230.pdf | 3 | VDD_0V8 | C54 | 100nF | digital local
01studio-CanMV-K230.pdf | 3 | VDD_0V8 | C55 | 100nF | digital local
01studio-CanMV-K230.pdf | 3 | VDD_0V8 | C56 | 100nF | digital local
01studio-CanMV-K230.pdf | 3 | VDD_0V8 | C57 | 100nF | digital local
01studio-CanMV-K230.pdf | 3 | VDD_0V8 | C58 | 100nF | digital local
01studio-CanMV-K230.pdf | 3 | VDD_0V8 | C59 | 100nF | digital local
01studio-CanMV-K230.pdf | 3 | VDD_0V8 | C60 | 100nF | digital local
01studio-CanMV-K230.pdf | 3 | VDD_0V8 | C61 | 100nF | digital local
01studio-CanMV-K230.pdf | 3 | VDD_0V8 | C62 | 100nF | digital local
01studio-CanMV-K230.pdf | 3 | VDD_0V8 | C63 | 100nF | digital local
01studio-CanMV-K230.pdf | 3 | VDD_0V8 | C64 | 100nF | digital local
01studio-CanMV-K230.pdf | 3 | VDD_0V8 | C65 | 100nF | digital local
01studio-CanMV-K230.pdf | 3 | VDD_0V8 | C68 | 100nF | digital local
01studio-CanMV-K230.pdf | 3 | VDD_0V8 | C69 | 100nF | digital local
01studio-CanMV-K230.pdf | 3 | VDD_0V8 | C70 | 100nF | digital local
01studio-CanMV-K230.pdf | 3 | VDD_0V8 | C71 | 100nF | digital local
01studio-CanMV-K230.pdf | 3 | VDD_0V8 | C72 | 100nF | digital local
01studio-CanMV-K230.pdf | 3 | VDD_0V8 | C73 | 100nF | digital local
01studio-CanMV-K230.pdf | 3 | VDD_1V1 | C74 | 4.7uF | SoC DDR IO local
01studio-CanMV-K230.pdf | 3 | VDD_1V1 | C75 | 100nF | SoC DDR IO local
01studio-CanMV-K230.pdf | 3 | VDD_1V1 | C76 | 100nF | SoC DDR IO local
01studio-CanMV-K230.pdf | 3 | VDD_1V1 | C77 | 100nF | SoC DDR IO local
01studio-CanMV-K230.pdf | 3 | VDD_1V1 | C78 | 100nF | SoC DDR IO local
01studio-CanMV-K230.pdf | 3 | VDD_1V1 | C79 | 100nF | SoC DDR IO local
01studio-CanMV-K230.pdf | 2 | VDD_1V1 | C20 | 22uF | DRAM local
01studio-CanMV-K230.pdf | 2 | VDD_1V1 | C21 | 4.7uF | DRAM local
01studio-CanMV-K230.pdf | 2 | VDD_1V1 | C22 | 100nF | DRAM local
01studio-CanMV-K230.pdf | 2 | VDD_1V1 | C23 | 100nF | DRAM local
01studio-CanMV-K230.pdf | 2 | VDD_1V1 | C24 | 100nF | DRAM local
01studio-CanMV-K230.pdf | 2 | VDD_1V1 | C25 | 100nF | DRAM local
01studio-CanMV-K230.pdf | 2 | VDD_1V1 | C26 | 100nF | DRAM local
01studio-CanMV-K230.pdf | 2 | VDD_1V1 | C27 | 100nF | DRAM local
01studio-CanMV-K230.pdf | 2 | VDD_1V1 | C28 | 100nF | DRAM local
01studio-CanMV-K230.pdf | 2 | VDD_1V1 | C29 | 100nF | DRAM local
01studio-CanMV-K230.pdf | 2 | VDD_1V1 | C30 | 100nF | DRAM local
01studio-CanMV-K230.pdf | 2 | VDD_1V1 | C31 | 100nF | DRAM local
01studio-CanMV-K230.pdf | 2 | VDD_1V8 | C32 | 22uF | DRAM local
01studio-CanMV-K230.pdf | 2 | VDD_1V8 | C33 | 4.7uF | DRAM local
01studio-CanMV-K230.pdf | 2 | VDD_1V8 | C34 | 100nF | DRAM local
01studio-CanMV-K230.pdf | 2 | VDD_1V8 | C35 | 100nF | DRAM local
01studio-CanMV-K230.pdf | 2 | VDD_1V8 | C36 | 100nF | DRAM local
01studio-CanMV-K230.pdf | 2 | VDD_1V8 | C37 | 100nF | DRAM local
01studio-CanMV-K230.pdf | 2 | VDD_1V8 | C38 | 100nF | DRAM local
01studio-CanMV-K230.pdf | 2 | VDD_1V8 | C39 | 100nF | DRAM local
01studio-CanMV-K230.pdf | 2 | VDD_1V1 | C40 | 22uF | DRAM local
01studio-CanMV-K230.pdf | 2 | VDD_1V1 | C41 | 4.7uF | DRAM local
01studio-CanMV-K230.pdf | 2 | VDD_1V1 | C42 | 100nF | DRAM local
01studio-CanMV-K230.pdf | 2 | VDD_1V1 | C43 | 100nF | DRAM local
01studio-CanMV-K230.pdf | 2 | VDD_1V1 | C44 | 100nF | DRAM local
01studio-CanMV-K230.pdf | 2 | VDD_1V1 | C45 | 100nF | DRAM local
01studio-CanMV-K230.pdf | 2 | VDD_1V1 | C46 | 100nF | DRAM local
01studio-CanMV-K230.pdf | 2 | VDD_1V1 | C47 | 100nF | DRAM local
01studio-CanMV-K230.pdf | 2 | VDD_1V1 | C48 | 100nF | DRAM local
01studio-CanMV-K230.pdf | 2 | VDD_1V1 | C49 | 100nF | DRAM local
01studio-CanMV-K230.pdf | 1 | VDD_3V3 | C13 | 100nF | IO bank pool | Banks0-4 use VDD_3V3; bank5 uses VDD_1V8; no one-to-one capacitor assignment
01studio-CanMV-K230.pdf | 1 | VDD_3V3 | C14 | 100nF | IO bank pool | Banks0-4 use VDD_3V3; bank5 uses VDD_1V8; no one-to-one capacitor assignment
01studio-CanMV-K230.pdf | 1 | VDD_3V3 | C15 | 100nF | IO bank pool | Banks0-4 use VDD_3V3; bank5 uses VDD_1V8; no one-to-one capacitor assignment
01studio-CanMV-K230.pdf | 1 | VDD_3V3 | C16 | 100nF | IO bank pool | Banks0-4 use VDD_3V3; bank5 uses VDD_1V8; no one-to-one capacitor assignment
01studio-CanMV-K230.pdf | 1 | VDD_3V3 | C17 | 100nF | IO bank pool | Banks0-4 use VDD_3V3; bank5 uses VDD_1V8; no one-to-one capacitor assignment
01studio-CanMV-K230.pdf | 3 | VDD_1V8 | C117 | 100nF | 1.8V local pool | Same rail serves generic SoC supply and other unfiltered loads; no per-ball mapping
01studio-CanMV-K230.pdf | 3 | VDD_1V8 | C118 | 100nF | 1.8V local pool | Same rail serves generic SoC supply and other unfiltered loads; no per-ball mapping
01studio-CanMV-K230.pdf | 3 | VDD_1V8 | C119 | 100nF | 1.8V local pool | Same rail serves generic SoC supply and other unfiltered loads; no per-ball mapping
01studio-CanMV-K230.pdf | 3 | VDD_0V8 | C85 | 22uF/10V | regulator output
01studio-CanMV-K230.pdf | 3 | VDD_0V8 | C86 | 22uF/10V | regulator output
01studio-CanMV-K230.pdf | 3 | VDD_0V8 | C87 | 22uF/10V | regulator output
01studio-CanMV-K230.pdf | 3 | VDD_1V1 | C92 | 22uF/10V | regulator output
01studio-CanMV-K230.pdf | 3 | VDD_1V1 | C93 | 22uF/10V | regulator output
01studio-CanMV-K230.pdf | 3 | VDD_1V1 | C94 | 22uF/10V | regulator output
01studio-CanMV-K230.pdf | 3 | VDD_3V3 | C99 | 22uF/10V | regulator output
01studio-CanMV-K230.pdf | 3 | VDD_3V3 | C100 | 22uF/10V | regulator output
01studio-CanMV-K230.pdf | 3 | VDD_3V3 | C101 | 22uF/10V | regulator output
01studio-CanMV-K230.pdf | 3 | VDD_1V8 | C106 | 22uF/10V | regulator output
01studio-CanMV-K230.pdf | 3 | VDD_1V8 | C107 | 22uF/10V | regulator output
01studio-CanMV-K230.pdf | 3 | VDD_1V8 | C108 | 22uF/10V | regulator output
CanMV-K230-V1.0_2023-09-15.pdf | 3 | CORE_0V8 | C56 | 22uF | digital local | CORE_0V8 powers CORE+CPU+DDR_CORE; tied to VDD_0V8 and KPU_0V8
CanMV-K230-V1.0_2023-09-15.pdf | 3 | CORE_0V8 | C57 | 4.7uF | digital local
CanMV-K230-V1.0_2023-09-15.pdf | 3 | CORE_0V8 | C58 | 100nF | digital local
CanMV-K230-V1.0_2023-09-15.pdf | 3 | CORE_0V8 | C59 | 100nF | digital local
CanMV-K230-V1.0_2023-09-15.pdf | 3 | CORE_0V8 | C60 | 100nF | digital local
CanMV-K230-V1.0_2023-09-15.pdf | 3 | CORE_0V8 | C61 | 100nF | digital local
CanMV-K230-V1.0_2023-09-15.pdf | 3 | CORE_0V8 | C62 | 100nF | digital local
CanMV-K230-V1.0_2023-09-15.pdf | 3 | CORE_0V8 | C63 | 100nF | digital local
CanMV-K230-V1.0_2023-09-15.pdf | 3 | CORE_0V8 | C64 | 100nF | digital local
CanMV-K230-V1.0_2023-09-15.pdf | 3 | CORE_0V8 | C65 | 100nF | digital local
CanMV-K230-V1.0_2023-09-15.pdf | 3 | CORE_0V8 | C66 | 100nF | digital local
CanMV-K230-V1.0_2023-09-15.pdf | 3 | CORE_0V8 | C67 | 100nF | digital local
CanMV-K230-V1.0_2023-09-15.pdf | 3 | CORE_0V8 | C68 | 100nF | digital local
CanMV-K230-V1.0_2023-09-15.pdf | 3 | CORE_0V8 | C69 | 100nF | digital local
CanMV-K230-V1.0_2023-09-15.pdf | 3 | CORE_0V8 | C70 | 100nF | digital local
CanMV-K230-V1.0_2023-09-15.pdf | 3 | CORE_0V8 | C71 | 100nF | digital local
CanMV-K230-V1.0_2023-09-15.pdf | 3 | CORE_0V8 | C72 | 100nF | digital local
CanMV-K230-V1.0_2023-09-15.pdf | 3 | KPU_0V8 | C73 | 22uF | digital local | Tied directly to VDD_0V8 and CORE_0V8
CanMV-K230-V1.0_2023-09-15.pdf | 3 | KPU_0V8 | C74 | 22uF | digital local | Tied directly to VDD_0V8 and CORE_0V8
CanMV-K230-V1.0_2023-09-15.pdf | 3 | KPU_0V8 | C75 | 4.7uF | digital local
CanMV-K230-V1.0_2023-09-15.pdf | 3 | KPU_0V8 | C76 | 100nF | digital local
CanMV-K230-V1.0_2023-09-15.pdf | 3 | KPU_0V8 | C77 | 100nF | digital local
CanMV-K230-V1.0_2023-09-15.pdf | 3 | KPU_0V8 | C78 | 100nF | digital local
CanMV-K230-V1.0_2023-09-15.pdf | 3 | KPU_0V8 | C79 | 100nF | digital local
CanMV-K230-V1.0_2023-09-15.pdf | 3 | DDR_1V2 | C80 | 22uF | SoC DDR IO local | LPDDR3 configured reference, not a 1.1V LPDDR4 recipe
CanMV-K230-V1.0_2023-09-15.pdf | 3 | DDR_1V2 | C81 | 4.7uF | SoC DDR IO local
CanMV-K230-V1.0_2023-09-15.pdf | 3 | DDR_1V2 | C82 | 100nF | SoC DDR IO local
CanMV-K230-V1.0_2023-09-15.pdf | 3 | DDR_1V2 | C83 | 100nF | SoC DDR IO local
CanMV-K230-V1.0_2023-09-15.pdf | 3 | DDR_1V2 | C84 | 100nF | SoC DDR IO local
CanMV-K230-V1.0_2023-09-15.pdf | 3 | DDR_1V2 | C85 | 100nF | SoC DDR IO local
CanMV-K230-V1.0_2023-09-15.pdf | 3 | DDR_1V2 | C86 | 100nF | SoC DDR IO local
CanMV-K230-V1.0_2023-09-15.pdf | 5 | DDR_VDDQ | C10 | 22uF | LPDDR3 DRAM local | As drawn; do not rename first DDR_VDDQ row to VDD2_VDDCA
CanMV-K230-V1.0_2023-09-15.pdf | 5 | DDR_VDDQ | C11 | 4.7uF | LPDDR3 DRAM local
CanMV-K230-V1.0_2023-09-15.pdf | 5 | DDR_VDDQ | C12 | 100nF | LPDDR3 DRAM local
CanMV-K230-V1.0_2023-09-15.pdf | 5 | DDR_VDDQ | C13 | 100nF | LPDDR3 DRAM local
CanMV-K230-V1.0_2023-09-15.pdf | 5 | DDR_VDDQ | C14 | 100nF | LPDDR3 DRAM local
CanMV-K230-V1.0_2023-09-15.pdf | 5 | DDR_VDDQ | C15 | 100nF | LPDDR3 DRAM local
CanMV-K230-V1.0_2023-09-15.pdf | 5 | DDR_VDDQ | C16 | 100nF | LPDDR3 DRAM local
CanMV-K230-V1.0_2023-09-15.pdf | 5 | DDR_VDDQ | C17 | 100nF | LPDDR3 DRAM local
CanMV-K230-V1.0_2023-09-15.pdf | 5 | DDR_VDDQ | C18 | 100nF | LPDDR3 DRAM local
CanMV-K230-V1.0_2023-09-15.pdf | 5 | DDR_VDDQ | C19 | 100nF | LPDDR3 DRAM local
CanMV-K230-V1.0_2023-09-15.pdf | 5 | DDR_VDDQ | C20 | 100nF | LPDDR3 DRAM local
CanMV-K230-V1.0_2023-09-15.pdf | 5 | DDR_VDDQ | C21 | 100nF | LPDDR3 DRAM local
CanMV-K230-V1.0_2023-09-15.pdf | 5 | DDR_VDDQ | C22 | 22uF | LPDDR3 DRAM local | As drawn; do not rename first DDR_VDDQ row to VDD2_VDDCA
CanMV-K230-V1.0_2023-09-15.pdf | 5 | DDR_VDDQ | C23 | 4.7uF | LPDDR3 DRAM local
CanMV-K230-V1.0_2023-09-15.pdf | 5 | DDR_VDDQ | C24 | 100nF | LPDDR3 DRAM local
CanMV-K230-V1.0_2023-09-15.pdf | 5 | DDR_VDDQ | C25 | 100nF | LPDDR3 DRAM local
CanMV-K230-V1.0_2023-09-15.pdf | 5 | DDR_VDDQ | C26 | 100nF | LPDDR3 DRAM local
CanMV-K230-V1.0_2023-09-15.pdf | 5 | DDR_VDDQ | C27 | 100nF | LPDDR3 DRAM local
CanMV-K230-V1.0_2023-09-15.pdf | 5 | DDR_VDDQ | C28 | 100nF | LPDDR3 DRAM local
CanMV-K230-V1.0_2023-09-15.pdf | 5 | DDR_VDDQ | C29 | 100nF | LPDDR3 DRAM local
CanMV-K230-V1.0_2023-09-15.pdf | 5 | DDR_VDDQ | C30 | 100nF | LPDDR3 DRAM local
CanMV-K230-V1.0_2023-09-15.pdf | 5 | DDR_VDDQ | C31 | 100nF | LPDDR3 DRAM local
CanMV-K230-V1.0_2023-09-15.pdf | 5 | DDR_VDDQ | C32 | 100nF | LPDDR3 DRAM local
CanMV-K230-V1.0_2023-09-15.pdf | 5 | DDR_VDDQ | C33 | 100nF | LPDDR3 DRAM local
CanMV-K230-V1.0_2023-09-15.pdf | 5 | DDR_VDD1_1V8 | C36 | 22uF | LPDDR3 DRAM local | As drawn; do not rename first DDR_VDDQ row to VDD2_VDDCA
CanMV-K230-V1.0_2023-09-15.pdf | 5 | DDR_VDD1_1V8 | C37 | 4.7uF | LPDDR3 DRAM local
CanMV-K230-V1.0_2023-09-15.pdf | 5 | DDR_VDD1_1V8 | C38 | 100nF | LPDDR3 DRAM local
CanMV-K230-V1.0_2023-09-15.pdf | 5 | DDR_VDD1_1V8 | C39 | 100nF | LPDDR3 DRAM local
CanMV-K230-V1.0_2023-09-15.pdf | 5 | DDR_VDD1_1V8 | C40 | 100nF | LPDDR3 DRAM local
CanMV-K230-V1.0_2023-09-15.pdf | 5 | DDR_VDD1_1V8 | C41 | 100nF | LPDDR3 DRAM local
CanMV-K230-V1.0_2023-09-15.pdf | 5 | DDR_VDD1_1V8 | C42 | 100nF | LPDDR3 DRAM local
CanMV-K230-V1.0_2023-09-15.pdf | 5 | DDR_VDD1_1V8 | C43 | 100nF | LPDDR3 DRAM local
CanMV-K230-V1.0_2023-09-15.pdf | 3 | VDD_1V8 | C90 | 100nF | 1.8V local pool
CanMV-K230-V1.0_2023-09-15.pdf | 3 | VDD_1V8 | C91 | 100nF | 1.8V local pool
CanMV-K230-V1.0_2023-09-15.pdf | 3 | VDD_1V8 | C92 | 100nF | 1.8V local pool
CanMV-K230-V1.0_2023-09-15.pdf | 3 | VDD_1V8_RTC | C93 | 100nF | RTC pool | VDD_1V8_RTC is tied to VDD_1V8 in source
CanMV-K230-V1.0_2023-09-15.pdf | 3 | VDD_1V8_RTC | C94 | 100nF | RTC pool | VDD_1V8_RTC is tied to VDD_1V8 in source
CanMV-K230-V1.0_2023-09-15.pdf | 3 | VDD_0V8 | C138 | 22uF | regulator output
CanMV-K230-V1.0_2023-09-15.pdf | 3 | VDD_0V8 | C139 | 22uF | regulator output
CanMV-K230-V1.0_2023-09-15.pdf | 3 | VDD_0V8 | C140 | 22uF | regulator output
CanMV-K230-V1.0_2023-09-15.pdf | 3 | DDR_1V2 | C142 | 22uF | regulator output
CanMV-K230-V1.0_2023-09-15.pdf | 3 | DDR_1V2 | C143 | 22uF | regulator output
CanMV-K230-V1.0_2023-09-15.pdf | 3 | DDR_1V2 | C144 | 22uF | regulator output
CanMV-K230-V1.0_2023-09-15.pdf | 3 | VDD_3V3 | C146 | 22uF | regulator output
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

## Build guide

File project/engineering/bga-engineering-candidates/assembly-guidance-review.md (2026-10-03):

# BGA land and assembly guidance: bounded engineering comparison

Status: **ENGINEERING CANDIDATES ONLY — NOT MANUFACTURER-QUALIFIED PCB FOOTPRINTS**. Reviewed 2026-09-30. No released CAD, frozen v10 files, orders, or vendor communications changed.

The accessible guidance supports a useful comparison of land constructions. It does not establish an approved Micron FW200, Micron BH153, or Canaan K230 footprint. Package solder-ball dimensions, package pad openings, PCB copper, PCB mask, and solder-paste apertures remain separate quantities.

## Primary evidence and limits

1. [Texas Instruments, SPRAA99C, nFBGA Packaging, May 2021](https://www.ti.com/lit/an/spraa99c/spraa99c.pdf), PDF pp6–7, 11, 15. The complete official PDF was downloaded; these pages were rendered and visually reviewed. Page 7 separates copper, mask opening, paste aperture, and stencil thickness. Selected NSMD examples are below. Its SMD counterparts exchange the copper and mask diameters. Page 6 balances package-interface and board-land dimensions; p11 refines NSMD copper to approximately 90% of the package interface. Page 15 makes mounted joint geometry dependent on paste, land, reflow, and package mass; reducing lands solely to increase standoff can worsen fatigue. Table examples and prose use different stencil thicknesses: they are process starting points, not one universal specification. The document recommends stencil area ratio at least 0.66. This is TI package guidance, not qualification of the reviewed parts.

| TI example pitch | PCB copper diameter | PCB mask opening diameter | Circular paste aperture | Stencil thickness | Area ratio, calculated |
|---:|---:|---:|---:|---:|---:|
| 0.50 | 0.300 | 0.400 | 0.300 | 0.100 | 0.750 |
| 0.65 | 0.350 | 0.450 | 0.350 | 0.127 | 0.689 |
| 0.80 | 0.400 | 0.500 | 0.400 | 0.152 | 0.658, rounded to 0.66 in TI |

2. [Infineon, Recommendations for Board Assembly of xWLy Packages, V03, 2016-01-11](https://www.infineon.com/dgdl/Infineon-Recommendations_Board_Assembly_xWLy_Packages-AP-v03_00-EN.pdf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), PDF pp8–9. Complete official PDF downloaded and those pages visually reviewed. NSMD exposes the pad sidewall; mask registration must leave the copper unobscured. Its 0.300 mm ball example uses 0.275 copper, 0.375 mask, 0.275 paste, and 0.100 stencil. Its prose mentions 0.075 mm mask clearance, while that table's diameter difference gives 0.050 mm per side: neither can be treated as a universal fabrication allowance. It warns that open vias drain solder and recessed microvia tops can increase voiding. Paste volume, print inspection, supplier capability, and component-specific routing matter. These wafer-level packages differ materially from molded memory BGAs, so use the document only as supporting process evidence. Search-result metadata described a newer revision, but the actual downloaded body is V03/2016; this report uses the body.

3. [Cypress/Infineon, AN98508, 001-98508 Rev. *D](https://community.infineon.com/gfawx74859/attachments/gfawx74859/KnowledgeBaseArticles/3788/1/Infineon-AN98508_Infineon_Serial_Peripheral_Interface_%28SPI%29_FL_Flas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), PDF p26 §4.1. Its official-hosted PDF text was accessible through the web tool before a subsequent local download returned HTTP 403. Retrieval stopped; no alternate endpoint or mirror was attempted. The inspected text gives an NSMD copper heuristic of 80–100% of solder-ball diameter and mask diameter 0.15 mm larger than copper. Its concrete examples concern Cypress SPI flash packages, not either Micron part or K230. This limited evidence is a secondary comparison only; it is not required to instantiate any candidate below. No complete local PDF was obtained and no rendered page was inspected.

NXP AN4982 was not obtained (web internal error; direct official request HTTP 404). It supplies no numeric evidence here. Micron CSN-33 was deliberately not accessed, retried, or obtained from any mirror. The older search-index quotation in existing mechanical work is not evidence used by this review.

Downloaded complete PDFs, source renders, and retrieval records reside outside the redesign deliverable tree at `/workspace/shared/k230-reference/mechanical/bga-engineering-candidates/`. Exact URLs, hashes, inspection pages, and failures are in `assembly-guidance-evidence.json`.

## Exact-package inputs, kept separate from the PCB

| Part | Verified physical grid | Package ball diameter | Package-side interface condition | Consequence |
|---|---|---|---|---|
| MT53E256M32D2FW-046 AAT:B | 200 balls; 0.80 X / 0.65 Y pitch | 0.436 ±0.050 | Post-reflow on 0.400 SMD ball pads | Tight 0.65 axis controls escape; package note does not authorize 0.400 PCB copper |
| MTFC16GAPALBH-AAT | 153 balls; 0.50 pitch | 0.319 nominal; no explicit diameter tolerance shown in inspected figure | Post-reflow on 0.300 SMD ball pads | 56 additional 0.270 test pads have no solder balls; never generate corresponding PCB solder lands |
| K230, escape comparison only | 390 balls; 0.65 pitch | 0.300 nominal, 0.250–0.350 | Guide lists 0.270 ball solder-mask opening in package context | A pitch-only 0.350 PCB land is not justified by this much smaller ball/interface |

Micron inputs come from the existing verified FW mechanics and LP4 grid review, and BH Figure 5, PDF p11 of the supplied automotive eMMC datasheet. K230 inputs come from the parent audit's verified package review. No exact-part PCB land-pattern instruction was found in these inputs. None establishes assembled standoff, paste volume, reflow recipe, or service-life qualification.

## Engineering candidates and calculated constraints

All dimensions below are millimetres. Every row is a **conditional nominal geometry for engineering evaluation**, not a recommended production footprint. Use only real solder-ball centers; preserve absent, NC, DNU, and VSF distinctions from the independent grid/net review.

| Evaluation case | NSMD copper | Mask opening | Circular paste aperture | Stencil thickness | Area ratio | Narrowest copper gap | Narrowest nominal mask web |
|---|---:|---:|---:|---:|---:|---:|---:|
| FW, pitch-table comparison | 0.350 | 0.450 | 0.350 | 0.100–0.120 | 0.875–0.729 | 0.300 | 0.200 |
| FW, interface-ratio comparison | 0.360 | 0.460 | 0.360 | 0.100–0.120 | 0.900–0.750 | 0.290 | 0.190 |
| FW, larger-land comparison | 0.400 | 0.500 | 0.400 | 0.100–0.120 | 1.000–0.833 | 0.250 | 0.150 |
| BH, interface-ratio comparison | 0.270 | 0.370 | 0.270 | 0.100 | 0.675 | 0.230 | 0.130 |
| BH, pitch-table comparison | 0.300 | 0.400 | 0.300 | 0.100 | 0.750 | 0.200 | 0.100 |
| K230, smaller-land comparison | 0.250 | 0.350 | 0.250 | 0.080–0.090 | 0.781–0.694 | 0.400 | 0.300 |
| K230, interface-size comparison | 0.270 | 0.370 | 0.270 | 0.100 | 0.675 | 0.380 | 0.280 |

FW spans 0.350–0.400 copper; 0.360 is 90% of its 0.400 package opening, conditionally treating that opening as the relevant wettable interface. BH 0.270 similarly compares 90% of its 0.300 interface with TI's 0.300 pitch example. K230 0.250–0.270 is only an escape sensitivity range near its smaller interface; the 90% arithmetic point is 0.243, not a selected land. The numerical resemblance of package and PCB dimensions does not convert a hypothesis into manufacturer approval.

Calculations are independent geometry:

- For a cylindrical aperture, area ratio = diameter / (4 × stencil thickness). At a 0.66 screening floor, maximum thickness = diameter / 2.64. Thus 0.270 allows at most 0.1023, while 0.250 allows at most 0.0947. A common 0.120 stencil gives only 0.5625 for 0.270; a 0.100 stencil gives 0.625 for 0.250. Those combinations fail this screen, although passing it still does not prove print yield.
- A nominal 0.050 radial NSMD mask clearance means mask diameter = copper diameter + 0.100. Evaluating 0.075 radial clearance instead adds 0.150 to the copper. BH then has only 0.080 web at 0.270 copper or 0.050 at 0.300 copper. These larger-mask variants are sensitivity checks requiring explicit fabrication capability; they are not interchangeable defaults.
- Straight escape between equal circular lands requires trace width + 2 × clearance ≤ pitch − copper diameter, before all tolerances. FW with 0.350 lands fits nominal 0.100/0.100 exactly, leaving no tolerance budget; 0.400 lands need finer rules. BH with 0.300 lands cannot fit even 0.075/0.075; 0.270 lands leave just 0.005 nominal spare. K230 at 0.270 leaves 0.080 spare with 0.100/0.100. Via capture pads, solder-mask-covered trace exposure, layer transitions, and signal integrity still require a routed study.
- For the limited ball-percentage heuristic, FW nominal 0.436 gives 0.3488–0.436. If one incorrectly required the rule to hold over every stated ball extreme, the lower bound would be 0.8 × 0.486 = 0.3888 and upper bound 0.386, leaving no intersection. K230 similarly produces 0.280 > 0.250. This demonstrates why a nominal ratio cannot replace toleranced solder-joint validation. BH lacks the ball tolerance needed even for that sensitivity exercise.

For an SMD comparison, TI's 0.500 copper / 0.400 opening and 0.400 copper / 0.300 opening are useful construction examples. The opening bounds the top wettable area; copper is larger underneath. Applying those to FW/BH would reduce nominal copper escape gaps to 0.150/0.100 respectively. Do not swap SMD and NSMD dimensions without rebuilding routing, mask registration, paste, and reliability assumptions.

### Additional BH SMD engineering case

**BH_SMD_CU0400_SM0300** is included as a separate, unqualified SMD evaluation case. Its geometry reproduces TI SPRAA99C Table 2-1's 0.50 mm-pitch SMD example: 0.400 copper diameter, 0.300 mask opening, 0.300 circular paste aperture, and 0.100 stencil. Its provenance is this general TI example; it is not a Micron land-pattern recommendation. All 153 physical solder-ball sites remain required, and the 56 bare package test pads remain excluded.

The BH package-side 0.300 SMD opening and this PCB-side 0.300 SMD opening give a nominal wettable-interface diameter ratio of 1.00. The copper diameter itself is 1.333 times the package opening, but 0.050 of copper is covered radially by mask. This distinction explains why the 0.400 SMD copper can be a supported generic comparison even though a 0.350 NSMD copper proposal falls outside the present NSMD comparison. That unsupported NSMD proposal does not become qualified by a sparse routing proof.

Calculated checks for the SMD case:

- Adjacent copper edge gap: 0.500 − 0.400 = **0.100 mm**. Literal 4 mil is **0.1016 mm**, so the nominal geometry fails a 4 mil copper-clearance rule by **0.0016 mm / 1.6 µm**. A separately specified 100 µm rule reaches equality, with zero nominal spare. Do not relabel 4 mil as 100 µm or imply that equality budgets copper-size/position tolerances.
- Mask opening edge gap: 0.500 − 0.300 = **0.200 mm**. This is mask web, not copper spacing; it cannot be used to claim a 0.200 mm electrical clearance.
- Mask overlap: (0.400 − 0.300) / 2 = **0.050 mm per side** nominally. To preserve SMD construction over the whole pad, the minimum copper radius minus maximum opening radius must exceed the worst-case relative registration displacement, with any required residual overlap. No fabrication tolerance budget has yet demonstrated this. Local loss of overlap creates unintended mixed SMD/NSMD geometry.
- Paste area ratio: 0.300 / (4 × 0.100) = **0.750**. This clears the 0.66 geometry screen; SPI transfer, aperture registration/sealing, flux, solder volume, wetting and reflow still require process validation.
- The 0.100 copper gap cannot carry a 0.075 trace with 0.075 clearance on both sides; that needs 0.225. VIPPO can avoid an inter-pad top-layer escape, but its drill, capture/annular ring, filling, capping, planarity, layer escape and full 153-site layout need their own fabrication/routing checks. A sparse proof does not establish those outcomes.

The covered pad edge changes wetting and the solder-joint neck relative to NSMD. Mask dimensional control, adhesion, thickness, registration and thermal/mechanical behavior therefore join the qualification inputs; do not inherit NSMD reliability results or treat the nominal interface ratio as life prediction. Higher-temperature operation makes representative board-level validation material, but does not itself select SMD or prove it unacceptable. The defensible outcome is an explicit SMD option for DFM/process review, conditional on a **separate literal 100 µm copper process** and a demonstrated tolerance budget; it cannot pass an unchanged literal 4 mil clearance check.

## Qualification still required

Release needs exact supplier/device/package revision applicability, finished copper and mask-registration tolerances, minimum surviving mask web, stackup and escape/via capability, planar filled/capped via treatment where needed, pad finish and paste/alloy compatibility, stencil transfer validation across the entire BOM, and an instrumented reflow process inside every component's limits. FW's supplied SACQ alloy must not silently become SAC305 in the process assumptions.

The high-temperature part ratings do not establish solder-joint life on this module. A representative assembly should demonstrate wetting, opens/bridges/voids and standoff through suitable inspection/cross-sections, electrical operation, and thermal/mechanical stress representative of the application. PCB thickness, CTE, package warpage, board support, copper balance, rework, and any underfill materially affect the outcome. Define acceptance criteria and mission profile before declaring a geometry qualified. No universal void percentage, reflow peak, underfill requirement, or lifetime is asserted here.

No proposed range closes the exact manufacturer land-pattern gap. It provides traceable choices and explicit constraints for a separate engineering candidate, preserving the current release boundary.

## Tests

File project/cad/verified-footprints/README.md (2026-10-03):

# Drawing-verified TI footprint library

Date: 2026-09-30. KiCad 9.0.2. This is an isolated engineering library, not a manufacturing release. No module master CAD or original carrier land pattern was changed.

## Editable outputs

The `CMK230_Verified.pretty` directory contains four front-side footprints:

- `TI_RSV0016A_TMUX1574_1.8x2.6_P0.4_DrawingVerified`: TMUX1574RSVR, 16 numbered copper pads
- `TI_DBV0005A_SN74LVC1G32_SOT23_5_DrawingVerified`: SN74LVC1G32DBVR, 5 numbered copper pads
- `TI_DMQ0006A_TPS6282xA_1.5x1.5_SMD_DrawingVerified`: TPS62824A/25A/26A/27A DMQ family, 6 numbered copper pads
- `TI_YCG0015_TPS628640_1.05x1.78_P0.35_SMD_DrawingVerified`: TPS628640BYCGR, 15 numbered copper pads

`DrawingVerified` means the package outline, numbered copper positions, exposed-metal geometry and TI example stencil were checked against the actual official drawing. It does not mean the selected PCB/assembly process has approved them. Numeric copper overlap and mask expansions chosen within TI's limits, and courtyard clearances chosen by the project, are documented separately from manufacturer dimensions.

`fp-lib-table` resolves the library relative to this directory. `Footprint_Geometry_QA_ONLY.kicad_pcb` and `.kicad_pro` load all four footprints on an isolated test coupon. That board has isolated one-pad nets, no functional circuit, no escape routing and no actual module connector. It is only for footprint geometry/DRC inspection. Do not send its QA Gerbers to manufacturing.

## Critical editing convention

Each footprint has one explicit, unnumbered `F.Mask`-only aperture per electrical pad. DMQ and YCG additionally have one unnumbered `F.Paste`-only aperture per electrical pad. These are deliberate CAD primitives, not extra pins. Preserve them when importing or modifying the footprints.

Copper pads intentionally omit `F.Mask`, avoiding two superimposed mask openings. All explicit mask apertures have local mask margin zero. All paste apertures have local paste margin and ratio zero. This keeps global board defaults from changing the audited example geometry.

Why explicit mask apertures? KiCad's ordinary rounded-pad mask-margin calculation rescales the corner radius with pad dimensions. It does not preserve the exact constant-radius offset required to reproduce the TI examples. Separate apertures preserve the DMQ exposed R0.05 corners and the specified circular YCG opening; native Gerber export was checked directly.

Coordinates are millimetres in component-side view: origin at nominal body center, +X right, +Y down. Pin 1/A1 is at the upper-left orientation. `F.Fab` shows nominal body with an orientation chamfer; `Dwgs.User` shows maximum body excluding any noted additional flash; `F.CrtYd` is a project-selected assembly clearance. There is no thermal center pad on RSV or DMQ.

## What remains before board release

- PCB/assembly-house approval of copper tolerances, mask registration/overlap, soldermask web, stencil design and paste process
- YCG's selected minimum-overlap SMD copper has 0.085 mm neighbor clearance at 0.35 mm pitch. Validate the selected fabricator's fine-pitch/HDI and escape capabilities
- TI's YCG paste example assumes a 0.075 mm stencil; the other three examples assume 0.125 mm. A single top-side board process needs an approved common or stepped-stencil solution, not unreviewed mixing of those examples
- Complete selected MPN/symbol-to-pad audit after integrating these footprints into the real schematic/PCB
- Placement, signal/power integrity, routing, thermal, assembly and real-board checks
- RAM, eMMC and K230 copper/mask/paste land patterns and module castellation manufacturing geometry remain separate release gates

See `../../engineering/mechanical/README.md` and the accompanying reports, layer gallery and verification JSONs.

## Compact alternatives addendum

`compact-options/` adds separate drawing-checked DRL and DCK logic-package candidates and a TPS3808 DRV WSON candidate. This does not change the four footprints above. Read its README before assigning them: TPS3808 requires every signal to be remapped and exposed pad 7 connected to GND. The compact audit covers SN74AUP1G06/07/08/17 within each same base part. See `../../engineering/mechanical/compact-package-audit.md` for source/verification evidence and bounded area comparisons.

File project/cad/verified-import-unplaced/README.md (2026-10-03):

# Partial core PCB import, unplaced

150 assigned source-reviewed candidate footprints have been imported from the current high-temperature schematic, including the 140-pad core edge. All 566 numbered electrical copper pads match their actual master-netlist nets. Unnumbered mask/paste-only apertures are retained and are not treated as electrical contacts. Schematic UUID paths are stored for continued KiCad editing.

All 149 internal footprints are parked outside the board outline. They are **not placed**, and no internal routing exists. 104 remaining component references still have no imported footprint. In particular, the main BGA land/escape candidates remain separate process studies. Missing footprints are not excluded from the schematic to hide this incompleteness.

The high-temperature project's same-named PCB is a copy of this partial import so the editable project can continue into layout. It is not a physical-fit, full parity or fabrication pass. Existing geometric DRC results for isolated footprints and the mechanical-only edge must not be applied to this board. Its parking arrangement intentionally violates normal finished-board expectations.

The source netlist hash, imported references and missing-reference list are recorded in import-validation.json. The source edge proposal is preserved separately.

## Native full-parity diagnostic on this incomplete import

Fresh HT-DRAFT13 checking reports 58 copper-clearance violations under the unqualified 0.20 mm default, 351 unrouted items, and 104 missing-footprint parity issues. The complete independent import ledger also lists 104 missing references. The extra sixth pin on the corrected U14 Schmitt OR increases the unrouted count by one; it is not a new short or missing logical net. All 566 imported numbered pads retain actual master-netlist bindings.

The older v11 diagnostic had 38 footprints, 341 bound pads, 138 unrouted items and 199 reported missing footprints versus 216 in its complete ledger. That historical report is preserved separately under engineering/process-rule-controls/default-v11-diagnostic.json. It does not describe the current 150-footprint import.

The tightest imported source land gap is0.085mm at U22/U23 (TPS62864 WLCSP), followed by0.15mm at the four TPS6282xA regulators and0.18mm at NVT4858. No rule was relaxed or violation excluded to obtain a pass. The source-reviewed footprint dimensions do not guarantee that the eventual board factory accepts those dimensions. A coherent process-specific rule set and complete layout remain necessary.

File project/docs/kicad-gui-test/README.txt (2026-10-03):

KiCad 9.0 actual cloud desktop GUI test, 2026-09-30 UTC

Test target: immutable extracted D0 CAD copy, not a finished internal core-board design.

Schematic loads: four symbol units, 140 module pins.
GUI ERC: 139 Pin not connected errors, 0 warnings. No errors were suppressed. Four default ignored test types are visible in erc-ignored.png: single-use global label, four-way junction, SPICE model issue, footprint filter mismatch.

PCB outline loads. Board status: 0 pads,0 vias,0 track segments,0 nets. GUI DRC:0 errors,0warnings,0unconnected items; schematic parity not run. A blank-outline DRC is not validation of a functioning circuit or manufacturing readiness.

Carrier mating footprint imports and displays140pads. Initial GUI Footprint Checker:1error (no courtyard defined),0warnings. The conservative assembly courtyard correction is complete. GUI retest:0 errors,0 warnings. The temporary import filename f is byte-identical to the delivered footprint, SHA256 4fcfaf56d54d20161bed00568c61657c48e143d964af848d7b44a9133fcd10ad. This footprint is a carrier land pattern, not a fabricated castellated core-board pad/drill design.

Screenshots were captured directly from the applications. No physical simulation, signal integrity/DDR timing analysis, firmware test or real hardware test was performed.

Final integrated update (2026-09-30): final13-root/power/erc.png show actual GUI on frozen thirteen-sheet master. Final GUI ERC51 =50errors+1warning, matching CLI. integrated-*.png are earlier ten-sheet/223-issue checkpoint, not final. No fabricated PCB/hardware qualification is implied.

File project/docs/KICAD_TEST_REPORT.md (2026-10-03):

# v9 高温候选实际GUI及双分支CLI检查

高温候选254引用，实际KiCad GUI打开并运行ERC，0错误/0警告。截图：kicad-gui-test/high-temp-root.png、high-temp-emmc.png、high-temp-erc.png。四个未核实Nexperia封装字段仍留空，不能把ERC0当作封装完整。标题栏文字偏长是已知显示问题，下一次非功能清理处理。

Samsung参考本轮为253引用，最新CLI/ERC/网表/PDF核对通过；没有声称它又做了GUI测试。两者温度/启动/布板均未合格。

# v8 当前CLI检查

18页、246引用，ERC0；743球位类型和主要网络回归通过。缓冲复位34项结构/16态检查通过。新温度要求仍阻止硬件释放，默认存储禁止。v7截图仅证明v7；v8未另做GUI检查；当前v8结果为CLI/网表/导出PDF检查，前次v7GUI截图仅适用于v7。

# v7 当前检查

2026-09-30：当前 18 页紧凑原理图经 KiCad 9 CLI 导出/检查，ERC 0。全部 743 个 BGA 球位类型审查已应用。未新增屏蔽规则；0 只表示当前原理图模型未报告违反。默认 R528 DNP，存储仍禁止。实际启动、PCB、波形、SI/PI和制造尚未合格。

实际 KiCad 9 GUI 重新加载当前 18 页工程并运行 ERC，结果 0 错误 / 0 警告，与 CLI 一致。标准 4 类默认忽略项目未改变。截图：kicad-gui-test/v7-root.png 和 v7-erc.png。早期 placement-only.png 只含 13 个 IC 外形，不能证明整板放得下；新增完整 BOM 矩形图不是 PCB 布局。

## 历史测试记录

v6 实际GUI复测已完成：KiCad9打开14页工程并重新运行ERC，结果14项=13错误+1警告，与CLI一致。截图 `kicad-gui-test/v6-root.png`、`v6-erc.png`。测试期间未修改CAD。没有声称ERC通过或可制板。

# v6 当前 CLI 复测

当前工程14页。KiCad9.0.2重新导出网表、ERC和PDF：13错误+1警告。131个存储器电源/地球位、65个DDR连接、62个外露GPIO和71个隔离子电路引脚分配回归通过；静态二选一真值表4状态通过。这些不是实物时序、SI、供电或启动测试。

本次修复eMMC供电名称反接，并增加可追溯电源声明、按官方数据标注不用引脚；所有未闭环的真实信号/供电问题均保留。19个CAD虚拟源不计入209个器件引用，也不进入BOM/PCB。

后续若有v6 GUI截图，以下补充；旧v4/v5/更早截图均仅为其版本历史，不能替代当前字节验证。

> v5供电纠正：请先阅读 `V5_CORRECTION_READ_FIRST.md`。旧v4的eMMC VDD/VDDF供电含义反接已修复；历史GUI截图不代表此修订。

# KiCad最终集成工程测试记录

最终对象：`cad/integrated/CMK230_Core_REVIEW.kicad_pro`，13页，209个参考位号、1382个针脚记录。

- 实际云端KiCad9 GUI成功打开根页及六轨电源页
- 最终GUI ERC为51项：50错误、1警告，与最终文件的CLI结果一致
- 细分：24个未连接引脚、26组未声明有效驱动/尚有集成问题的电源网络、1个MMC0_STROBE悬空全局端点
- 全部已分配针脚网络匹配XML导出；65条DDR对应、62个外露GPIO、TF无旁路、私有调压总线和关键偏置检查通过
- 真实NC/RFU/必须悬空端点均有制造商证据后才标记，没有用NC掩盖其他未知网络
- 没有PCB布局、完整上电验证、SI/PI、热测试或实际硬件功能测试

截图：`kicad-gui-test/final13-root.png`、`final13-power.png`、`final13-erc.png`。这不是ERC通过或可制板结论。

下面保留此前接口/配合封装测试的历史记录。`integrated-*.png`为较早的10页/223项检查快照，不是最终13页状态；其他旧截图对应最初D0接口/空轮廓。以本段和最终13页文件报告为准。

---

# KiCad 9 实际打开与规则检查

测试日期：2026-09-30。工具：云端桌面实际KiCad9 GUI，以及KiCad9.0.2命令行。截图位于`kicad-gui-test/`。测试范围是本D0接口草稿，不是尚未建立的内部电路。

## 结果
- 接口原理图成功打开；4个单元，140个编号/名称完整
- GUI ERC报告139条未连接错误、0警告。没有关闭相关未连接检查或加NC标记来消除错误；默认忽略项目截图另存：单次使用全局标签、四路连接点、SPICE模型问题、封装筛选器不匹配
- 导出网表有140个彼此独立的单节点未连接网络。pin45 ADC2在网表中明确未连接，但此次ERC未列出；具体遗漏原因尚未确认，不把139条报告解释为第140针已经连通
- PCB轮廓成功打开；仅38×38mm轮廓和说明，没有器件、铜、孔或布线。GUI DRC结果0；本次没有原理图一致性检查。这不表示核心板电气设计通过
- 底板配合封装成功打开，140个SMD焊盘。首次Footprint Checker发现1个缺少courtyard错误、0警告

## 已修复的courtyard
在工作版本的配合封装添加闭合F.CrtYd矩形，坐标±19.80mm、线宽0.05mm。现有铜焊盘包络±19.546mm，名义额外间距0.254mm；38mm本体包络较小，亦包含在内。此尺寸是保守的底板装配空间占位，不是已通过板厂批准的模块结构/半孔加工尺寸。

140个原焊盘中心和原始尺寸/方向保持不变。几何检查记录见`courtyard-validation.json`。含单个修复后配合封装的独立检查夹具，CLI DRC结果0违规、0未连项；原始不可变GUI测试副本没有覆盖。

GUI修复后Footprint Checker复测：0错误、0警告，截图`footprint-after.png`和`footprint-check-after.png`。为导入方便，窗口标题显示临时文件名f；该文件与交付封装SHA-256完全一致，140个焊盘未改变。复测未关闭检查规则。

## 如何理解这些检查
ERC仍有错误是因为接口没有内部电路。无器件的轮廓PCB获得0DRC，只能说明当前空轮廓没有报告违规。courtyard修复只改善配合封装装配检查，不解决半孔加工、DDR布线、BGA逃线、电源时序或TF/eMMC隔离。

## 继续设计前的具体问题
1. 官方TF边缘引脚与eMMC固件均指向MMC0；eMMC固件是1.8V/8bit/HS200。原模块在eMMC装配中的外部TF隔离/电压/使用限制须确认，不能把3.3V卡接到未确认的1.8V共享网络
2. 半孔孔径/镀层、实际板厚、叠层和制造公差未建立；现文件默认层数/厚度不是设计规格
3. DDR已有65信号端点候选及器件球图，仍需训练映射、完整供电/去耦/终端、版图与SI/PI审核
4. 两路对外电源按官网300mA/100mA要求设计；瞬态、过载、热和电源顺序未实测

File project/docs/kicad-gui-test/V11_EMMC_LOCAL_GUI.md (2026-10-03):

# v11 eMMC local-trial GUI test

The exact BH153_SPARSE_LOCAL_TRIAL.kicad_pcb was opened in cloud KiCad PCB Editor. The visible board statistics were153 pads,29 vias,16 track segments,136 nets and17 unrouted items.

A fresh GUI DRC run reported17 errors, all unconnected items, and32 dangling warnings. No tests were ignored. Schematic parity was not run for this local fragment. This matches the command-line/native validation; it does not prove complete core routing, timing, power-plane connectivity, capacitor placement or fabrication acceptance.

Screenshots: v11-emmc-local-open.png and v11-emmc-local-drc.png. The GUI operator did not save or alter the geometry. The earlier high-temp-* schematic GUI screenshots remain historical v9 evidence, not a GUI check of the current HT-DRAFT11 precision-resistor changes.

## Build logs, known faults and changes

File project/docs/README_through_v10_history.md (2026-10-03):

# v10：核心板评审工程

最新说明见 [V10_CORE_REVIEW.md](V10_CORE_REVIEW.md)。以下 v9 内容是历史检查记录，当前高温候选已增加 GW 封装和缩小反馈分压修订；新的边缘/叠层提案单独存放。默认 R528 DNP，存储禁止，尚非启动或制造合格设计。

# v9：核心板专用评审工程，含独立高温候选

保留38×38mm、顶面器件、140针1mm接口、1GB内存与16GB eMMC。允许同板断电切换eMMC/TF；TF卡座在核心板外，不设计底板、外设或外部散热系统。核心板内保留必要隔离和电平转换，不把接口电压问题转嫁为未说明的底板改造。

## 两个明确工程

- cad/high-temp-candidate/CMK230_Core_REVIEW.kicad_pro：新的条件式高温候选，18页、254个网表引用，247个拟装功能件。Micron1GB LPDDR4为105°C壳温等级，16GB eMMC为105°C环境温度等级；四个Nexperia逻辑器件为125°C环境温度等级。不是整板温度评级
- cad/integrated/CMK230_Core_REVIEW.kicad_pro：保留Samsung参考并补齐本轮去耦，18页、253个引用，246个拟装功能件。原85°C存储器限制明确保留

所有计数排除逻辑J1、四个DNP选项和两个观测点后才称为拟装功能件。R528仍默认DNP，主机存储通路禁止；两版均没有被证明可以启动。

## 本轮核验和修正

1. Micron两颗存储器全部353个物理球位有独立核对；保留真实NC/DNU/RFU/VSF差异。没有把不同料号简单改名为“兼容件”
2. Micron专属CReg、VCC/VCCQ本地旁路及独立DS偏置已落图；Samsung参考中的新增本地旁路仍为工程候选值
3. 官方完整检查表转成44项审查记录，覆盖22个章节，含11个自动断言。补上MICBIAS的4.7µF+100nF及VCM缺少的4.7µF；外设条目只保留接口边界，不扩展成外设设计
4. 原针脚合同的部分MIPI差分对间没有插入地针，与检查表建议存在继承的接口例外。针脚不改，后续用布局/回流/串扰验证处理，不能伪称全部建议已满足
5. 两版最新CLI ERC均为0；全部743个BGA电气类型、65条DDR连接、131个电源/参考节点和62个外露GPIO回归通过。互锁34项结构与16态检查通过
6. 高温候选已在实际KiCad GUI打开并重新ERC，0错误/0警告；截图为high-temp-root、high-temp-emmc、high-temp-erc。这证明工程载入与原理图模型检查，不是温度、启动或制造通过

## 物理进展与真实缺口

NVT4858和Y2晶体候选封装有图纸/几何审核。新的Nexperia微型封装没有冒用TI封装：其精确铜/阻焊/钢网多边形图目前未能读取，四个关联暂留空；正在评估同功能标准封装。三颗BGA仍没有获释放的生产焊盘/逃线方案。

当前Samsung基线的252个预留矩形可无重叠拼排，密集面积1043.50mm²；0402情形1175.47mm²超过暂定1156mm²内部面积。高温实料电容会显著改变这些数值；这一结果不适用于宣称高温版本已放得下。矩形没有解决局部去耦、热回路、BGA逃线或高速布线。

## 未关闭的核心板问题

- 暂按85°C密闭环境空气作保守筛选，尚非确认边界。存储器等级提高不代表热设计完成；K230、NVT4858、晶体、稳压器和无源器件仍须满足各自局部壳温/结温/环境温度限制
- Micron高温DDR需要正确训练、模式寄存器、温度相关刷新及可能的时序降额，不能沿用未审核的Samsung初始化
- 板级OTP首次驱动电压、读回和同OTP下MMC0双介质启动行为仍需依据。未生成或烧录OTP
- 高温逻辑的最窄静态低电平余量约60mV，供电全范围、噪声、棕断和实际复位波形未测
- 精确无源BOM、有效电容量、生产焊盘、叠层、完整布局布线、SI/PI及核心板实测仍未完成

官方IBIS模型要求适用的书面许可；未运行模型，亦未放入压缩包。没有采购、外部发送、外设设计或制造文件释放。旧v4存在的eMMC供电映射错误已修复，禁止用v4制板。

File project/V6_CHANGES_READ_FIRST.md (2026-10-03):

# v6 变更与当前硬件状态

本版延续v5对危险eMMC供电映射错误的修复：VDDF=VCC闪存主电源接3.3V，VDD=VCCQ接独立VEMMC_IO。v4不得接线或制板。

-131个LPDDR4/eMMC电源及地球位自动回归全部匹配
-官方K230引脚工作簿和参考图支持14个LPDDR4模式不用引脚、4个单rank不用输出；Samsung H5为HS400专用输出，在HS200方案中明确不用
-17个稳压器经L/FB/0Ω供电路径被逐条追踪；另对外部5V输入/地返回作CAD电源声明，没有给VEMMC_IO或六个bank输入伪造来源
-TMUX模拟触点改为passive类型，TEST_EN为input，MMC0_STROBE为input；更准确的类型暴露了真实未驱动输入问题
-当前KiCad实际GUI及CLI均为14项：13错误、1警告，工程14页。静态隔离真值表4种状态和71个引脚连接回归通过

ERC从51降到14不代表硬件接近可生产。余下项目中有启动依赖：PMU默认需要PAD64长按或PAD68高电平，当前输入开路/下拉没有证明PMU启动；完整硬件复位和存储使能仍缺失。PAD68自动启动有官方寄存器依据，下一步应把同域偏置、PMU状态和隔离时序共同设计。

官方文档还显示SDIO0启动电压涉及不可逆OTP；普通冷选择焊盘不能自行改变它。未生成或烧写OTP。固定1.8V主机配TF电平转换是待审方案，不是已完成修改，也没有降低原定性能。

通用TPS386000监控候选的DDR阈值/迟滞与当前最差电源公差不相容，因而没有装成一个表面完整但不能保证启动的复位电路。确切eMMC CReg参数仍待制造商资料。完整PCB、封装、顶面放置、半孔工艺、SI/PI、热、固件与实测均未完成。

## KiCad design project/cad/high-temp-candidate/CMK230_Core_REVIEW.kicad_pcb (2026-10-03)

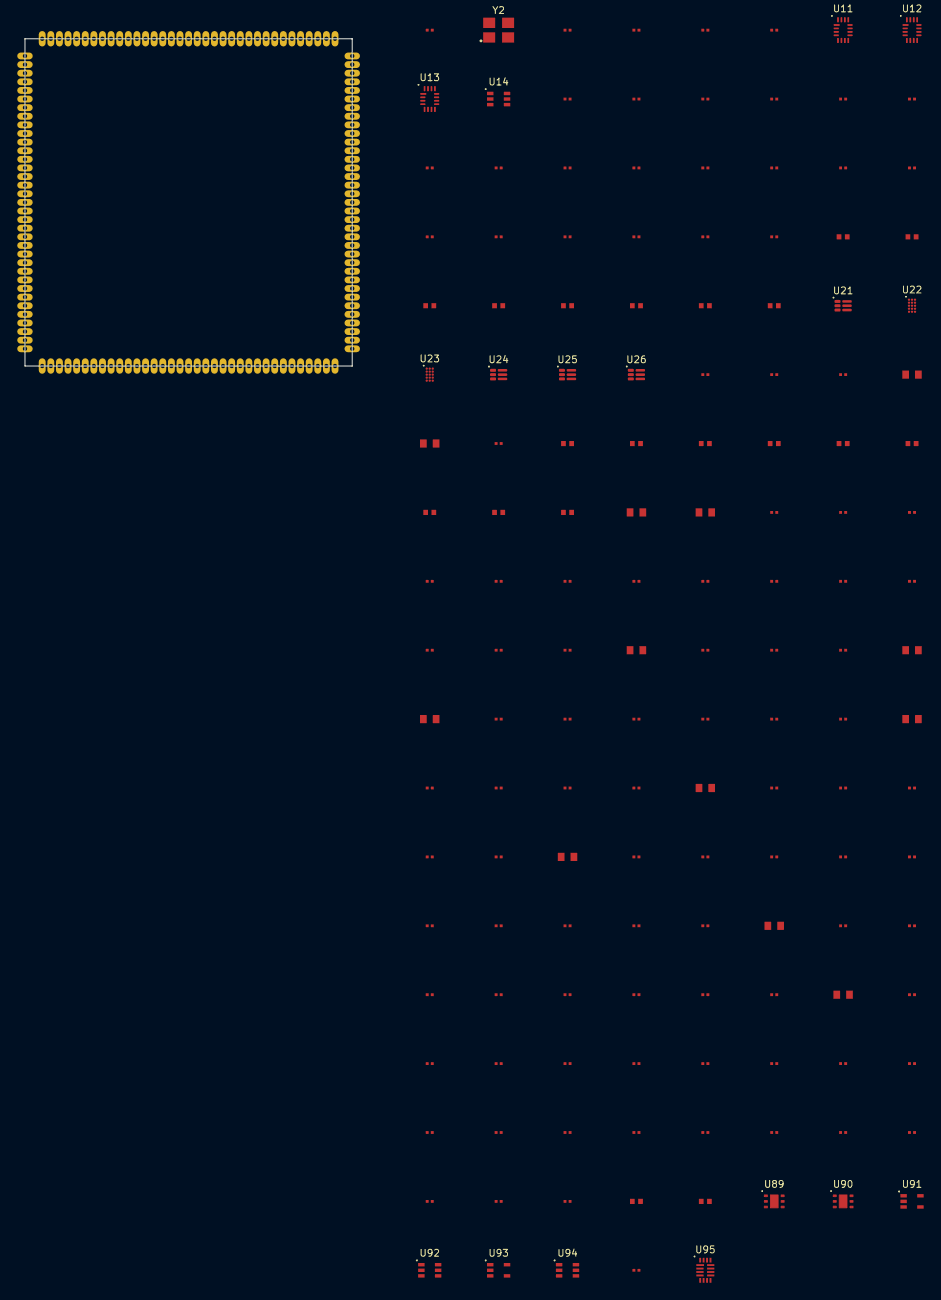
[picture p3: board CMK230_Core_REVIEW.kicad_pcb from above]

Board: 8 copper layers, 150 parts (0 on the bottom side), 49 nets, no tracks yet.

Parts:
C31, C32, C33, C34, C45, C61, C62, C63, C68, C205, C209, C215, C222, C227, C232, C233, C234, C235, C236, C237, C238, C239, C240, C241, C242, C243, C244, C245, C246, C503, C504, C505, C506, C507, C508, C509, C510, C511, C512, C513, C514, C515, C516, C518, C519, C520, C523, C524, C525, C526, C527, C528, C530, C531, C532, C533, C535, C536, C537, C538, C539, C542, C543, C544, C545, C546, C547, C548, C549, C550, C551, C554, C555, C556, C557, C558, C559, C560, C561, C564, C565, C566, C567, C568, C569, C570, C571, C572, C573, C574, C575, C576, C577, C809, C810, C811, C812, C813, C814, C816: 100nF CL03B104KP3NNWC CANDIDATE; Samsung_CL03B104KP3NNWC_MIDPOINT_LAND_DENSE_CANDIDATE
C66, C67, C501, C502, C517, C521, C522, C529, C534, C541, C553, C563: 4.7uF CL10B475KQ8NFQC CANDIDATE; Samsung_CL10B475KQ8NFQC_MIDPOINT_LAND_DENSE_CANDIDATE
J1: CM-K230 edge contract ONLY; CMK230_38x38_140P1_D0.50_Oval0.80x1.80_PROCESS_UNQUALIFIED
R63, R64, R65, R66: 240R TNPW0402 0.1pct 10ppm TOTAL<=0.70pct CANDIDA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; Vishay_TNPW0402_IPC7351_SourceLand_PROCESS_CANDIDATE
R67, R68: 30k TNPW0402 0.1pct 10ppm TOTAL<=0.70pct CANDIDATE; Vishay_TNPW0402_IPC7351_SourceLand_PROCESS_CANDIDATE
R69, R70, R71: 200R TNPW0402 0.1pct 10ppm TOTAL<=0.70pct CANDIDA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; Vishay_TNPW0402_IPC7351_SourceLand_PROCESS_CANDIDATE
R201: 3.32k TNPW0402 0.1pct 10ppm TOTAL<=0.70pct CANDID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; Vishay_TNPW0402_IPC7351_SourceLand_PROCESS_CANDIDATE
R202, R208, R211, R214, R526: 10k TNPW0402 0.1pct 10ppm TOTAL<=0.70pct CANDIDATE; Vishay_TNPW0402_IPC7351_SourceLand_PROCESS_CANDIDATE
R207: 8.66k TNPW0402 0.1pct 10ppm TOTAL<=0.70pct CANDID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; Vishay_TNPW0402_IPC7351_SourceLand_PROCESS_CANDIDATE
R210: 20k TNPW0402 0.1pct 10ppm TOTAL<=0.70pct CANDIDATE; Vishay_TNPW0402_IPC7351_SourceLand_PROCESS_CANDIDATE
R213: 45.3k TNPW0402 0.1pct 10ppm TOTAL<=0.70pct CANDID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; Vishay_TNPW0402_IPC7351_SourceLand_PROCESS_CANDIDATE
R525: 88.7k TNPW0402 0.1pct 10ppm TOTAL<=0.70pct CANDID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; Vishay_TNPW0402_IPC7351_SourceLand_PROCESS_CANDIDATE
U11, U12, U13: TMUX1574RSVR / CANDIDATE; TI_RSV0016A_TMUX1574_1.8x2.6_P0.4_DrawingVerified
U14: 74AUP1G97GW,125 SCHMITT OR CANDIDATE; Nexperia_SOT363-2_AUP1G97_DrawingVerified_CANDIDATE
U21: TPS62827ADMQ; TI_DMQ0006A_TPS6282xA_1.5x1.5_SMD_DrawingVerified
U22, U23: TPS628640BYCGR; TI_YCG0015_TPS628640_1.05x1.78_P0.35_SMD_DrawingVerified
U24, U26: TPS62826ADMQ; TI_DMQ0006A_TPS6282xA_1.5x1.5_SMD_DrawingVerified
U25: TPS62825ADMQ; TI_DMQ0006A_TPS6282xA_1.5x1.5_SMD_DrawingVerified
U89: TPS3808G01DRVR VIN GUARD; TI_DRV0006A_D_TPS3808_6P_EP7_DrawingVerified_CANDIDATE
U90: TPS3808G01DRVR RESET DELAY; TI_DRV0006A_D_TPS3808_6P_EP7_DrawingVerified_CANDIDATE
U91: 74AUP1G17GW,125 HIGH_TEMP CANDIDATE; Nexperia_SOT353-1_AUP1G17_06_DrawingVerified_CANDIDATE
U92, U94: 74AUP1G97GW,125 HIGH_TEMP CANDIDATE; Nexperia_SOT363-2_AUP1G97_DrawingVerified_CANDIDATE
U93: 74AUP1G06GW,125 HIGH_TEMP CANDIDATE; Nexperia_SOT353-1_AUP1G17_06_DrawingVerified_CANDIDATE
U95: NVT4858HKZ TF HS50 CANDIDATE; NXP_SOT1161-2_NVT4858HK_1.8x2.6_P0.4_DrawingVerified_CANDID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
Y2: X322524MOB4SI 24MHz CL12pF CANDIDATE; YXC_X322524MOB4SI_3225_4P_DrawingCandidate

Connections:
AVDD0P8_MIPI: C235.1, C246.1
AVDD1P8_MIPI: C240.1, C245.1
AVDD1P8_PMU: C238.1, C239.1
BANK0_VDDIO: C570.1, J1.107
BANK1_VDDIO: C571.1, J1.136
BANK2_VDDIO: C572.1, J1.90
BANK3_VDDIO: C573.1, J1.123
BANK4_VDDIO: C574.1, J1.23
BANK5_VDDIO: C575.1, J1.103
CODEC_VCM: C63.1, C66.1
CORE_PGOOD_5V: U21.2, U22.E1, U23.E1, U24.1, U25.1, U26.1
DDR_VREF: C61.2, C62.1, R65.2, R66.1
DISABLE_OR_TF: U13.13, U14.4
FB_1V8: R210.2, R211.1, U25.3
FB_3V3: R213.2, R214.1, U26.3
FB_CORE: R201.2, R202.1, U21.3
FB_DDR: R207.2, R208.1, U24.3
FIXED_RAILS_PGOOD_3V3: U24.2, U25.2, U26.2, U89.6, U92.3, U94.3
GLOBAL_DISABLE: U11.13, U12.13, U14.1, U93.4
GND: C31.2, C32.2, C33.2, C34.2, C45.2, C62.2, C63.2, C66.2, C67.2, C68.2, C205.2, C209.2, C215.2, C222.2, C227.2, C232.2, C233.2, C234.2, C235.2, C236.2, C237.2, C238.2, C239.2, C240.2, C241.2, C242.2, C243.2, C244.2, C245.2, C246.2, C501.2, C502.2, C503.2, C504.2, C505.2, C506.2, C507.2, C508.2, C509.2, C510.2, C511.2, C512.2, C513.2, C514.2, C515.2, C516.2, C517.2, C518.2, C519.2, C520.2, C521.2, C522.2, C523.2, C524.2, C525.2, C526.2, C527.2, C528.2, C529.2, C530.2, C531.2, C532.2, C533.2, C534.2, C535.2, C536.2, C537.2, C538.2, C539.2, C541.2, C542.2, C543.2, C544.2, C545.2, C546.2, C547.2, C548.2, C549.2, C550.2, C551.2, C553.2, C554.2, C555.2, C556.2, C557.2, C558.2, C559.2, C560.2, C561.2, C563.2, C564.2, C565.2, C566.2, C567.2, C568.2, C569.2, C570.2, C571.2, C572.2, C573.2, C574.2, C575.2, C576.2, C577.2, C809.2, C810.2, C811.2, C812.2, C813.2, C814.2, C816.2, J1.1, J1.2, J1.3, J1.36, J1.49, J1.57, J1.64, J1.71, J1.78, J1.89, J1.106, R64.2, R66.2, R69.2, R70.2, R71.2, R202.2, R208.2, R211.2, R214.2, R526.2, U11.6, U12.6, U12.8, U12.10, U12.11, U12.12, U13.1, U13.4, U13.6, U13.8, U13.11, U13.15, U14.2, U21.4, U22.A1, U22.B1, U22.B2, U22.B3, U23.A1, U23.B1, U23.B2, U23.B3, U24.4, U25.4, U26.4, U89.5, U89.7, U90.5, U90.7, U91.3, U92.1, U92.2, U93.3, U94.1, U94.2, U95.7, Y2.2, Y2.4
MIC_BIAS: C67.1, C68.1, J1.50
MODE_TF: U11.15, U12.15, U14.6
RESET_DELAYED_1V8: U90.6, U91.2
RESET_RELEASE_REQUEST_1V8: U90.4, U94.4
RSTN: C45.1, J1.122, U94.6
STORAGE_ENABLE_1V8: U92.4, U93.2
SW_CPU: U22.C1, U22.C2, U22.C3
SW_KPU: U23.C1, U23.C2, U23.C3
TFCARD_CLK: J1.21, U95.8
TFCARD_CMD: J1.22, U95.13
TFCARD_D0: J1.17, U95.10
TFCARD_D1: J1.18, U95.9
TFCARD_D2: J1.19, U95.12
TFCARD_D3: J1.20, U95.11
TF_HOST_CLK: U11.1, U95.5
TF_HOST_CMD: U11.4, U95.16
TF_HOST_D0: U11.8, U95.3
TF_HOST_D1: U11.11, U95.4
TF_HOST_D2: U12.1, U95.1
TF_HOST_D3: U12.4, U95.2
VDD0P8_CORE: C501.1, C502.1, C503.1, C504.1, C505.1, C506.1, C507.1, C508.1, C509.1, C510.1, C511.1, C512.1, C513.1, C514.1, C515.1, C516.1, R201.1
VDD0P8_CPU: C517.1, C518.1, C519.1, C520.1, U22.A3
VDD0P8_DDR_CORE: C233.1, C529.1, C530.1, C531.1, C532.1, C533.1
VDD0P8_KPU: C521.1, C522.1, C523.1, C524.1, C525.1, C526.1, C527.1, C528.1, U23.A3
VDD1P1_DDR_IO: C61.1, C534.1, C535.1, C536.1, C537.1, C538.1, C539.1, C541.1, C542.1, C543.1, C544.1, C545.1, C546.1, C547.1, C548.1, C549.1, C550.1, C551.1, C553.1, C554.1, C555.1, C556.1, C557.1, C558.1, C559.1, C560.1, C561.1, R63.2, R65.1, R207.1
VDD1P8: C563.1, C564.1, C565.1, C566.1, C567.1, C568.1, C569.1, C576.1, C577.1, C809.1, C810.1, C811.1, C812.1, C813.1, C814.1, J1.8, R210.1, U89.1, U89.4, U90.1, U90.2, U91.5, U92.5, U93.5, U94.5, U95.15
VDD_3V3: C31.1, C32.1, C33.1, C34.1, C816.1, J1.7, R213.1, U11.14, U12.14, U13.14, U14.3, U14.5, U95.14
VIN_5V: C205.1, C209.1, C215.1, C222.1, C227.1, C232.1, J1.4, J1.5, J1.6, R67.1, R68.1, R525.1, U21.6, U22.D1, U22.D2, U22.D3, U23.D1, U23.D2, U23.D3, U24.6, U25.6, U26.6
VIN_GUARD_SENSE: R525.2, R526.1, U89.2

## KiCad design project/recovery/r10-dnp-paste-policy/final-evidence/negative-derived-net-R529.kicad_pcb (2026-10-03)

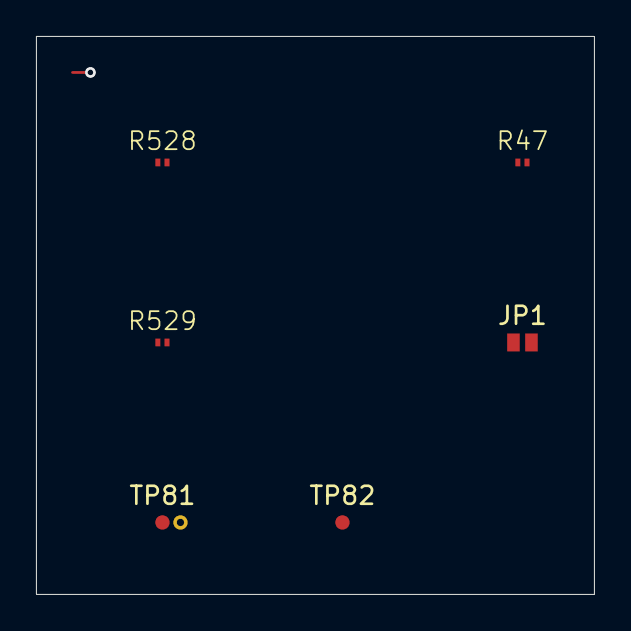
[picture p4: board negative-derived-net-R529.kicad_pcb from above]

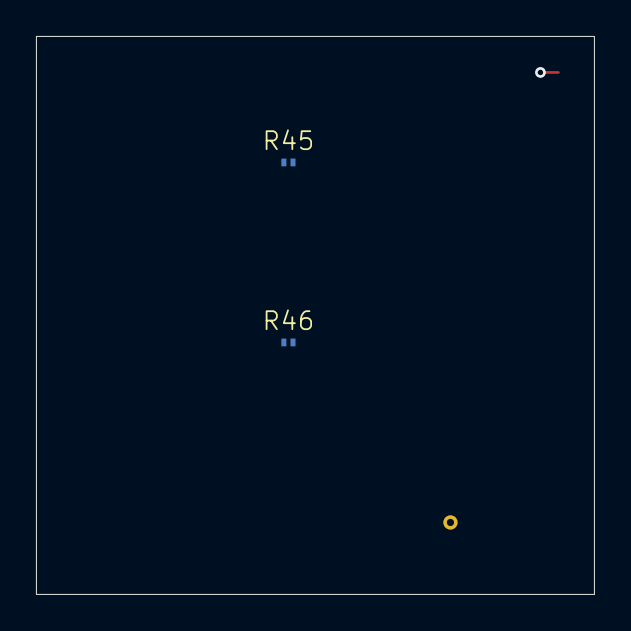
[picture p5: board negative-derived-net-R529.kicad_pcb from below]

Board: 2 copper layers, 31.0 x 31.0 mm, 8 parts (2 on the bottom side), 3 nets.

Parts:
JP1: OPEN=EMMC / CLOSED=TF; COLD ONLY; Core_Cold_Selector_Open_SolderBridge_CANDIDATE
R45: 10k BOOT0 HIGH / DNP; Vishay_CRCW0201_SourceLand_PROCESS_CANDIDATE
R46: 10k BOOT1 HIGH; Vishay_CRCW0201_SourceLand_PROCESS_CANDIDATE
R47: 10k BOOT1 LOW / DNP; Vishay_CRCW0201_SourceLand_PROCESS_CANDIDATE
R528: 0R QUALIFICATION STRAP DNP; Vishay_CRCW0201_SourceLand_PROCESS_CANDIDATE
R529: 100k DEFAULT INHIBIT; Vishay_CRCW0201_SourceLand_PROCESS_CANDIDATE
TP81: PMU OUT0 OBSERVE ONLY; Core_PMUSTATUS_Top_TestPad_0p8_CANDIDATE
TP82: PMU OUT1 OBSERVE ONLY; Core_PMUSTATUS_Top_TestPad_0p8_CANDIDATE

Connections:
BOOT1: R46.1, R47.1
BOOT_VOLTAGE_QUALIFIED_1V8: R528.2, R529.1
VDD1P8: R45.2, R46.2, R528.1, R529.2

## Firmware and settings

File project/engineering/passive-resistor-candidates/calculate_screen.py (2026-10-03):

#!/usr/bin/env python3
"""Reproduce the bounded resistor-candidate screen from its frozen netlist extract.

No CAD file is modified. Resistance acceptance bands are requirements, not a
manufacturer lifetime model. Run from any directory; outputs stay beside script.
"""
from pathlib import Path
import hashlib
import json
import re

OUT = Path(__file__).resolve().parent
ROOT = OUT.parents[1]
snapshot = json.loads((OUT / 'input-snapshot.json').read_text())
rails = {r['rail']: r for r in snapshot['static_rail_source']['rails']}
v18lo, v18hi = [rails['1V8'][f'regulator_static_{x}_V'] for x in ('min', 'max')]
v33lo, v33hi = [rails['3V3'][f'regulator_static_{x}_V'] for x in ('min', 'max')]
vddlo = rails['DDR']['regulator_static_min_V']
tol = 0.10
def bounds(r, t=tol):
    return [r * (1-t), r * (1+t)]
def crcw(r):
    return 'CRCW0201' + {4700:'4K70',10000:'10K0',22000:'22K0',43000:'43K0',47000:'47K0',100000:'100K',1000000:'1M00'}[r] + 'FKED'

source_specs = {
    'CRCW': ('/workspace/shared/k230-reference/mechanical/passive-review/vishay-CRCW0201e3.pdf', 'https://www.vishay.com/docs/20052/crcw0201e3.pdf', '20052, 21-Sep-2022, pp1-4'),
    'TNPW': ('/workspace/shared/k230-reference/TNPW_e3.pdf', 'https://www.vishay.com/docs/28758/tnpw_e3.pdf', '28758, 10-Apr-2026, pp2-4'),
    'TNPW_LANDS': ('/workspace/shared/k230-reference/Vishay_28950.pdf', 'https://www.vishay.com/doc?28950', '28950, 12-Jul-2022, p1'),
    'TPS3808': ('/workspace/shared/k230-reference/tps3808.pdf', 'https://www.ti.com/lit/ds/symlink/tps3808.pdf', 'Rev N, Aug-2026, electrical characteristics p6'),
    'TPS6282X': ('/workspace/shared/k230-reference/tps62827.pdf', 'https://www.ti.com/lit/ds/symlink/tps62827.pdf', 'electrical characteristics p5'),
    'TPS62864': ('/workspace/shared/k230-reference/tps62864.pdf', 'https://www.ti.com/lit/ds/symlink/tps62864.pdf', 'Rev C, pp5-8 and Table8-1 p12'),
    'LVC32': ('/workspace/shared/k230-reference/mechanical/sn74lvc1g32-ti.pdf', 'https://www.ti.com/lit/ds/symlink/sn74lvc1g32.pdf', 'Rev W, Aug-2026, pp6-7'),
    'TMUX': ('/workspace/shared/k230-switch-review/tmux1574-ti-rev-c.pdf', 'https://www.ti.com/lit/ds/symlink/tmux1574.pdf', 'Rev C, p6 and sections8.3.4/8.3.5'),
    'MICRON_EMMC': ('/workspace/shared/k230-memory-review/thermal-candidates/micron-emmc.pdf', 'https://e2e.ti.com/cfs-file/__key/communityserver-discussions-components-files/234/EMMC_5F00_DATASHEET.pdf', 'Micron automotive eMMC Rev G, Table13 p27'),
    'MICRON_LP4': ('/workspace/shared/k230-memory-review/thermal-candidates/micron-lp4.pdf', 'https://www.mouser.com/datasheet/2/671/200b_z00m_sdp_ddp_auto_lpddr4_lpddr4x-3193603.pdf', 'Micron automotive LPDDR4/4X Rev F, Table153 p223 and Table170 p234'),
}
sources = {k: {'url':u,'locator':d,'local_sha256':hashlib.sha256(Path(p).read_bytes()).hexdigest()} for k,(p,u,d) in source_specs.items()}
sources.update({
 'AUP97': {'url':'https://assets.nexperia.com/documents/data-sheet/74AUP1G97.pdf','locator':'Rev14 pp6-8; 125C column; discrete VCC test points'},
 'AUP17': {'url':'https://assets.nexperia.com/documents/data-sheet/74AUP1G17.pdf','locator':'Rev14 pp5-7; 125C column; discrete VCC test points'},
 'AUP06': {'url':'https://assets.nexperia.com/documents/data-sheet/74AUP1G06.pdf','locator':'Rev12 pp5-7; 125C column'},
 'K230_GUIDE': {'url':'https://github.com/kendryte/k230_docs/blob/main/en/00_hardware/K230_Hardware_Design_Guide.md','locator':'power table VDD3P3_SD=50mA design budget; not transient maximum'},
 'K230_PINOUT': {'url':'https://kendryte-download.canaan-creative.com/developer/k230/HDK/K230%E7%A1%AC%E4%BB%B6%E6%96%87%E6%A1%A3/K230_PINOUT_V1.2_20240822.xlsx','locator':'main rows12/13/32/82, PMU IO AVDD1P8_LDO; default rows67-69/71 input/pulldown'},
 'K230_IO': {'url':'https://atta.szlcsc.com/upload/public/pdf/source/20240304/CED0BDC8B8BEDC72BFC23F1C8A2ED83A.pdf','locator':'Manufacturer-authored datasheet mirror, PDF pp29-30; generic IO, PMU applicability unproven'},
 'I2C_RC': {'url':'https://www.ti.com/lit/an/slva689/slva689.pdf','locator':'p2, ideal30-70% RC rise-time relation'},
})
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

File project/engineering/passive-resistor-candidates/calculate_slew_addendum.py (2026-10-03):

#!/usr/bin/env python3
"""Bounded U14 slew and existing-family alternative calculations; no CAD writes."""
from pathlib import Path
import json
import math

out=Path(__file__).resolve().parent
base=json.loads((out/'static-screen.json').read_text())
vmin,vmax=base['rail_bounds_V']['3V3']
vinf=vmin-9.75e-6*11000
factor=math.log((vinf-.8)/(vinf-2.0))
d={
 'status':'U14_INPUT_SLEW_NOT_CLOSED_BY_R33_CHANGE; BOUNDED_SCHMITT_ALTERNATIVE_ONLY',
 'cad_edits':False,
 'LVC_existing':{
  'part':'SN74LVC1G32DBVR','source':'https://www.ti.com/lit/ds/symlink/sn74lvc1g32.pdf','revision':'W','pages':[6,7,8,10,13,14],
  'max_input_dt_dv_ns_per_V':10,'applicable_VCC_V':[3.0,3.6],
  'GLOBAL_DISABLE_model':{'Rmax_ohm':11000,'sink_leakage_A':9.75e-6,'Vinf_V':vinf,'illustrative_crossing_V':[.8,2.0],'ln_factor':factor,'average_limit_Cmax_F':10e-9*1.2/(11000*factor),'local_slope_at_2V_Cmax_F':10e-9*(vinf-2.0)/11000,'known_typical_input_C_sum_F':10e-12,'average_dt_dv_at_10pF_ns_per_V':11000*10e-12*factor/1.2*1e9,'C_is_guaranteed':False,'missing_C':['U93 output','trace','pads','measurement fixture'],'interpretation':'Illustrative necessary slope screen, not a manufacturer-defined test interval or observed failure. Actual capacitance and transient waveforms unavailable.'},
  'MODE_TF':'Cold-only JP1 makes this a fixed strap during valid stable-supply operation. Open is pulled low; closed tracks3V3. No powered switching authorized; supply ramp/contact settling still unqualified.',
  'output_load':'Only U13.EN plus R33 and PCB/probe capacitance. R33 does not set normal push-pull output rise time.',
  'output_capacitance_condition_F':50e-12,'output_tpd_max_s':4e-9,'output_tpd_conditions':'3.3V±0.3V,125C table, CL50pF/RL500ohm measurement network, input tr/tf≤2.5ns. Not an output-rise-time guarantee and not directly applicable to the slow input.',
  'dedicated_output_rise_fall_max_found':False,
 },
 'AUP_alternative':{
  'part':'74AUP1G97GW,125','source':'https://assets.nexperia.com/documents/data-sheet/74AUP1G97.pdf','revision':'14','pages':[3,4,5,7,8,9,10,11],
  'correct_OR':'A=1; Y=B OR C','incorrect_B_high_configuration':'B=1; Y=A OR NOT C',
  'proposed_GW_pin_map':{'1':'B=GLOBAL_DISABLE','2':'GND','3':'A=VDD_3V3','4':'Y=DISABLE_OR_TF','5':'VCC=VDD_3V3','6':'C=MODE_TF'},
  'supply_V':[.8,3.6],'max_input_V':3.6,'static_rail_headroom_to_3p6V_V':3.6-vmax,
  'input_leakage_A':.75e-6,'GLOBAL_DISABLE_total_high_leakage_A':5.5e-6,'GLOBAL_DISABLE_high_min_V':vmin-5.5e-6*11000,'MODE_TF_total_input_leakage_A':4.75e-6,'MODE_TF_low_max_V':4.75e-6*11000,
  'Schmitt_thresholds_at_discrete_3V_125C':{'VTplus_max_V':2.32,'VTminus_min_V':.88,'hysteresis_min_V':.79,'GLOBAL_DISABLE_high_margin_V':vmin-5.5e-6*11000-2.32,'GLOBAL_DISABLE_low_margin_V':.88-.39,'MODE_TF_low_margin_V':.88-4.75e-6*11000,'MODE_TF_high_margin_V':vmin-2.32,'gate':'These are3.0V tabulated thresholds. Extension to3.245–3.392V is not silently interpolated; full-range interpretation/characterization remains open.'},
  'slow_input_evidence':'Existing nexperia-aup97-slow-input-review.json: specified Schmitt thresholds/hysteresis, no input-transition row, and manufacturer handbook support slow inputs at valid stable supply. Dynamic table fast-input conditions are not slew restrictions.',
  'continuous_range_output_125C':{'supply_V':[.8,3.6],'IOL_A':20e-6,'VOL_max_V':.11,'IOH_A':-20e-6,'VOH_min_expression':'VCC-0.11V'},
  'R33_options':{},
  'source_dynamic_conditions':{'supply_V':[3.0,3.6],'CL_to_tpd_max':{'5pF':4.3e-9,'10pF':5.1e-9,'15pF':5.7e-9,'30pF':7.4e-9},'input_tr_tf_max_s':3e-9,'measurement':'50% input-to50% output, RL1Mohm. No standalone maximum output rise/fall specification. Slow-input application does not inherit these nanosecond delay guarantees.'},
  'actual_capacitive_load_verified':False,
  'retained_gates':['Same supply rail means no retained-high promise during rail loss.','Below0.8V and especially0.2–0.8V is not deterministic logic.','AtVCC0–0.2V additional IOFF is0.75uA; do not call it ordinary powered logic.','Actual output rise/fall, load capacitance, receiver switch timing, source noise and threshold-range applicability need validation.','Keep local bypass;6-pin SOT363-2 symbol/footprint remap required. No drop-in5-pin replacement.']
 }
}
for r in [43000,220000,270000]:
 lo,hi=r*.9,r*1.1
 sink=vmax/lo+2e-6
 d['AUP_alternative']['R33_options'][str(r)]={'resistance_screen_ohm':[lo,hi],'total_acceptance_fraction':.1,'sink_bound_A':sink,'reserve_to_20uA_A':20e-6-sink,'continuous_range_20uA_row_pass':sink<=20e-6,'low_margin_if_20uA_row_applies_V':.45-.11 if sink<=20e-6 else None,'active_high_min_V':vmin-.11,'active_high_margin_to_TMUX_VIH_V':vmin-.11-1.2,'unpowered_Ioff_A':.75e-6,'unpowered_Ioff_condition':'VCC=0; VI or VO=0–3.6V','hypothetical_separate_live_pullup_high_min_V':vmin-(.75e-6+2e-6)*hi,'hypothetical_separate_live_pullup_high_margin_V':vmin-(.75e-6+2e-6)*hi-1.2,'same_rail_power_loss_high_claim':False}
assert not d['AUP_alternative']['R33_options']['43000']['continuous_range_20uA_row_pass']
assert d['AUP_alternative']['R33_options']['270000']['continuous_range_20uA_row_pass']
(out/'u14-slew-addendum.json').write_text(json.dumps(d,indent=2)+'\n')
print(json.dumps({'LVC_average_C_limit_pF':d['LVC_existing']['GLOBAL_DISABLE_model']['average_limit_Cmax_F']*1e12,'AUP_270k':d['AUP_alternative']['R33_options']['270000']},indent=2))

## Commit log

2026-10-03 Initialize K230 R2.1 recovery checkpoint documentation
    Stage: partial electrical/footprint delta; missing v12 baseline.
    Fresh KiCad 9.0.2: 254 components, 1509 bindings, 0 errors and 150 missing-library ERC warnings.
    No active whole-board PCB; not production-ready.
2026-10-03 Restore verified v12 + R2.1 editable engineering checkpoint
    Stage: restored schematic and candidate-footprint source; not production-ready.
    Publish 986 inspected files with SHA256SUMS, source provenance and required upstream MIT notice.
    Fresh KiCad 9.0.2: 254 components, 1509 pin bindings, zero ERC errors/warnings; all 10 footprint libraries resolve. Rechecked against the exact public source copy.
    Remaining: 105 unassigned footprints; no active complete six-layer board, routing, thermal/timing/DFM or manufacturing qualification. Historical trials retain their limited scope.
    Baseline ZIP SHA256: 63dab93b8433b3a367571ec64b11568b9c81dc466e8d562ce2108b647d341e58
    R2.1 ZIP SHA256: 4e23cf611b37900d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
    [01_SoC_1.kicad_sch, 01studio-soc-to-lpddr4-65nets.csv, 02_SoC_2.kicad_sch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]
2026-10-03 Add R3 conditional footprint coverage and rename root project notes
    Assign source-reviewed candidate footprints to L22-L26 and R574 only.
    Coverage: 155 assigned, 99 unassigned; 254 components and 1509 pin bindings remain unchanged, with R528 DNP preserved.
    Fresh KiCad 9.0.2 ERC: zero errors/warnings. Isolated fixture DRC passes; clearance negative control rejects as expected. Native recheck performed against exact publication copy.
    Preserve all 27 frozen engineering changes plus their manifest. Root project notes renamed to 哦READ.MD as requested; existing history preserved.
    Remaining gates include whole-board six-layer layout/routing, inductor under-body restrictions, thermal/timing/DFM an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
    [10_Six_Rail_Power.kicad_sch, 16_TF_Voltage_Translation.kicad_sch, CRCW0201_NEGATIVE_CLEARANCE.kicad_pcb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]
2026-10-03 Add R4 conditional BGA identity and footprint coverage
    Assign U1/U2/U3 candidate footprints: 743 physical lands, 158 assigned and 96 remaining references. Preserve all 254 components, 1509 pin bindings, values and population attributes.
    Fresh KiCad 9.0.2 checks on exact public copy: zero ERC violations, zero isolated six-layer geometry-fixture DRC violations, and native 390/200/153 numbered-pad recount. Independent 30+17 review checks are retained.
    Correct eMMC maximum-body/courtyard drawing and K230 orientation cue without changing inherited copper/mask/paste pad subtrees. No historical routing, vias or fanout imported.
    38 changed/new files only; retain exact root notes filename 哦READ.MD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
    [01_SoC_1.kicad_sch, 02_SoC_2.kicad_sch, 03_SoC_3.kicad_sch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]
2026-10-03 Add R5 conditional 43k eMMC DAT pullup checkpoint
    Change only R563-R570 Value and Footprint fields to 43k CRCW020143K0FKED candidates. Preserve 254 references, 457 nets, 1509 pin/function/type/net bindings and all other exported component/population attributes. Coverage: 166 assigned, 88 gaps; R528 DNP preserved.
    Fresh KiCad 9.0.2 export and ERC plus full-attribute independent comparison pass on the exact public copy. The required +/-10% total resistance envelope gives 38.7-47.3k within the cited 10-50k source range; this is not an arbitrary-life guarantee.
    CORE PG material is review-only with an unchanged-graph bridge; no supervisor alternative or topology change adopted.
    28 changed/new fil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
    [14_EMMC_Local_Bias.kicad_sch, CMK230_Core_REVIEW.kicad_sch]
2026-10-03 Add R6 conditional passive footprint coverage
    Assign candidates to 25 ordinary bias resistors and L21 only. Preserve all 254 component values, 457 nets, 1509 bindings and population attributes; R45/R47/R528 remain DNP. Coverage: 192 assigned, 62 gaps.
    Exact publication-copy KiCad 9.0.2 export/ERC and full-component/graph comparison pass. L21 isolated six-layer fixture DRC passes; deliberate 1.40mm clearance rejects the 1.39mm gap. Native pad1 +X start mapping and recorded paste SVG aperture parity verified.
    Keep independent graph, geometry and paste-override evidence. Three original explanatory/native-CAM SVGs inspected; no vendor pages, PDFs or runtime files uploaded.
    60 changed/new files o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
    [08_Clock_Reset_Boot.kicad_sch, 09_Cold_Storage_Selector.kicad_sch, 10_Six_Rail_Power.kicad_sch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]
2026-10-03 R7: add conditional link footprints and fabricated copper features
    Add ten footprint bindings and exclude JP1/TP81/TP82 from BOM; preserve all 254 values, 457 nets, 1509 pin/function/type/net bindings, on-board and DNP states. Coverage 202 assigned / 52 gaps.
    Fresh KiCad 9.0.2 ERC passes. Independent exact-copy schematic, geometry, population, placement and CAM controls pass. Ten-reference isolated fixture has zero rule violations and three expected unrouted shared-net connections. Default paste still contains R528's two apertures despite DNP; explicit assembly/stencil variant remains a release gate. No complete core PCB, routing or manufacturing qualification.
    Preserve 65 normalized sourc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
    [09_Cold_Storage_Selector.kicad_sch, 10_Six_Rail_Power.kicad_sch, 13_PMU_Automatic_Startup.kicad_sch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]
2026-10-03 R8: add conditional ferrite and feedforward source lands
    Add thirteen footprint assignments: FB202-FB210 and C202/C219/C224/C229. Preserve all other component attributes, 254 values, 457 nets, 1509 pin/function/type/net bindings and BOM/population flags. Coverage 215 assigned / 39 gaps.
    Fresh exact-copy KiCad 9.0.2 ERC and isolated geometry DRC pass. Native save/reload and complete copper/mask/paste aperture geometry match source CAM. Eight independent negative controls reject as expected, including physical clearance violations. All 89 frozen public source files plus manifest are preserved byte-identically; 1231 remote file hashes, sizes and modes match the local tree. Vendor originals and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
    [10_Six_Rail_Power.kicad_sch, 18um_copper_shrunk_to_35um_width.kicad_pcb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]
2026-10-03 R9: add conditional eMMC bypass footprint candidates
    Assign C64/C65/C69/C70/C71/C72 footprints while preserving all 254 values, other component metadata, 457 nets, 1509 complete pin/node bindings, BOM and population states. Coverage 221 assigned / 33 gaps. Internal EMMC_VDDIM, VCCQ and VCC roles remain distinct.
    Fresh exact-copy KiCad 9.0.2 ERC and isolated geometry DRC pass. Full schematic metadata, fresh exported components/libparts/nets, source land/body ranges and saved/native CAM dimensions verified. Seven independent negative controls reject, including native physical 0.10mm clearance against 0.20mm rule. All 52 frozen source files plus manifest preserved byte-identically; all 1277 re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
    [11_DDR_USB_MIPI_Bias.kicad_sch, CMK230_Core_REVIEW.kicad_sch, EMMC_BYPASS_LANDS_GEOMETRY_ONLY.kicad_pcb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]
2026-10-03 R10: verify review-only DNP paste derivation policy
    Add 108 new tool/review files plus manifest. All 1265 existing project files remain byte-identical to R9; circuit stays RCV-R9, 221 assigned / 33 footprint gaps. Preserve values, nets, BOM/population and canonical CAD.
    Exact-copy KiCad 9.0.2 policy suite passes 42 checks including 16 required negative rejections. Strict master/source/derived FPID, population and electrical pad-net parity fails closed on unknown or unsupported ownership. Non-paste board tokens, native copper/mask/outline/Fab, drill geometry and placement are preserved by the bounded synthetic fixture tests.
    Recovered ten-reference R7 fixture independently rerun after hash-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
    [DERIVED_STENCIL_REVIEW_ONLY-B_Cu.gbl, DERIVED_STENCIL_REVIEW_ONLY-B_Mask.gbs, DERIVED_STENCIL_REVIEW_ONLY-B_Paste.gbp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]
2026-10-03 R11: add nine conditional 22uF source-land assignments
    Assign C206-C208, C212-C214, C540/C552/C562 to the Samsung CL31B226 source-land candidate. Preserve all 254 values and other non-footprint identities, 457 nets, 1509 complete pin bindings and DNP/BOM/on-board flags. Coverage 230 assigned / 24 gaps.
    Exact-copy independent audit passes all 77 checks: source schematic/generator scope, library ownership, input/source hashes, geometry and native CAM. Fresh KiCad 9.0.2 ERC and isolated fixture DRC pass. Six negative controls reject, including a physical native clearance violation. Courtyard clearance is 0.25mm from the mask envelope to the inner edge of its 0.05mm stroke.
    All 50 frozen sourc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
    [10_Six_Rail_Power.kicad_sch, 12_Local_Decoupling.kicad_sch, BULK22_LANDS_GEOMETRY_ONLY.kicad_pcb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]
2026-10-03 R12: preserve baseline and add unpromoted input-bank sibling
    Add a separate RCV-INBANK-R12 candidate with exactly eight input value/footprint changes and four capacitor removals. Candidate: 250 components, 1501 bindings, 457 nets, 238 assigned / 12 gaps. All 1417 existing R11 project files remain byte-identical; preferred comparison baseline remains 254/1509 with 230 assigned / 24 gaps. Candidate is not promoted.
    Exact-copy independent audit verifies fresh and regenerated ERC0, exact circuit/native population/library/pin-CSV contract, six retained 100nF bypasses, DNP safeguards, 34-reference source bridge and 16 rejected negative controls. No vendor originals or runtime files included. Both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
    [01_SoC_1.kicad_sch, 02_SoC_2.kicad_sch, 03_SoC_3.kicad_sch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]
